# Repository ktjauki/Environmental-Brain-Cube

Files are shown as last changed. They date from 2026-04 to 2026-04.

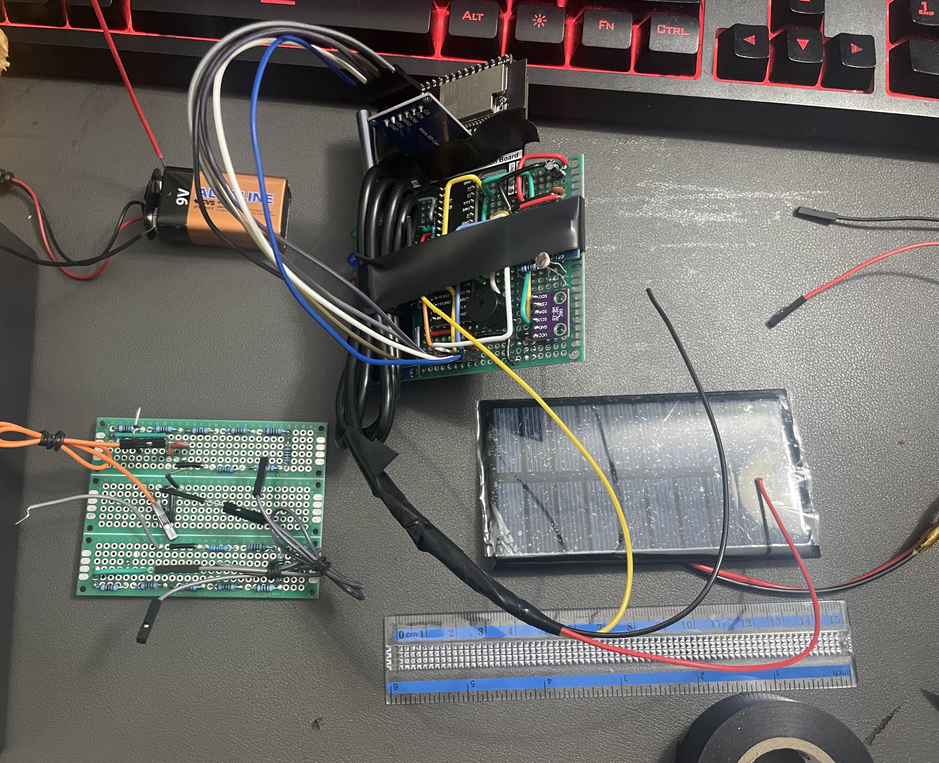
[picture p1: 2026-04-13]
Media/Components of system.JPG

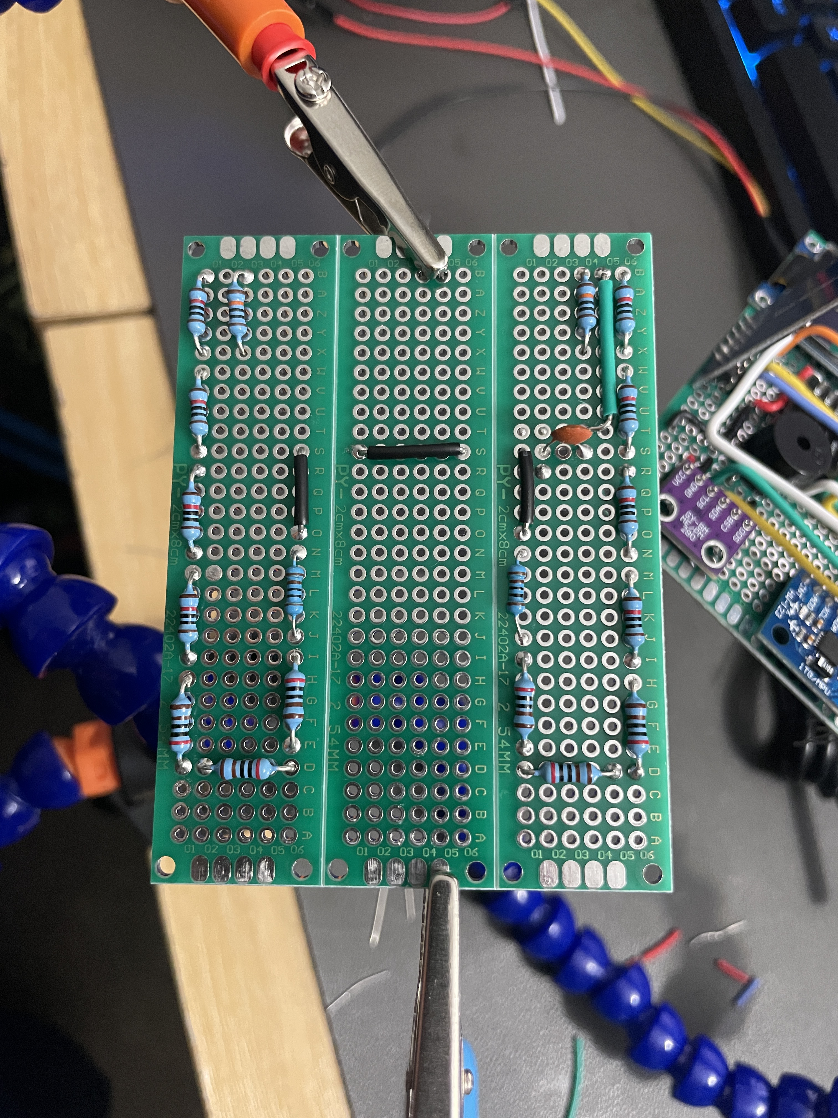
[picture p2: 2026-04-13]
Media/Voltage divider setup.JPG

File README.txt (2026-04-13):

Environmental Brain Cube (EBC)

Overview
The Environmental Brain Cube (EBC) is a compact ESP32-based embedded system designed to monitor, analyze, and evaluate environmental conditions in real time.

The system integrates multiple sensors to measure temperature, humidity, pressure, motion, light, and power, while logging data for post-processing in MATLAB. It is designed to determine environment classification and long-term suitability, with applications in space exploration and autonomous systems.

The project demonstrates a complete pipeline:
data acquisition → processing → evaluation → prediction → decision-making

Full Report:
See Project Report folder or GitHub repository.

Key Features
- Multi-sensor environmental monitoring
- Real-time OLED display + serial output
- SD card logging (CSV + summaries)
- Threshold-based warning system (LEDs + buzzer)
- Environment classification:
  - Normal
  - Warm-Dry
  - Warm-Humid
  - Cold
- MATLAB-based:
  - Data visualization
  - Trend analysis
  - Long-term prediction
  - Suitability evaluation

Hardware System

Core Components
- ESP32 WROVER-E (main controller)
- BME280 – air temperature, humidity, pressure
- DS18B20 – ground temperature
- MPU6050 – acceleration & gyroscope
- Photoresistor – light sensing
- OLED (SSD1306) – display
- SD Card Module – data logging
- 5V Solar Panel – power input sensing
- 9V Battery – power source

System Architecture

1. Data Acquisition
   Sensors collect environmental data continuously

2. Processing
   ESP32 converts raw data into usable values
   Invalid data is filtered

3. Evaluation
   Values compared to predefined thresholds
   Environment matched to closest profile

4. Output
   OLED + Serial Monitor display
   SD card logging
   LED/Buzzer alerts

5. Post-Processing
   MATLAB used for analysis, visualization, and predictions

Repository Structure

Environmental-Brain-Cube/
|
|-- Arduino Code/          # ESP32 programs (FREE run, MODES classification, SUITABILITY analysis)
|-- MATLAB Scripts/        # MATLAB scripts for data processing, plotting, and prediction
|-- MATLAB Outputs/        # Generated graphs, figures, and analysis results
|-- CSV Logged Data Files/ # Raw sensor data collected from test runs (CSV format)
|-- CAD Files/             # 3D models and design files for the enclosure
|-- Media/                 # Images of setup + Google Drive link to videos (videos stored externally due to large size)
|-- Project Report/        # Full engineering report (PDF)
|-- README.txt

Experimental Setup

Experiments were conducted using a controlled simulation box to replicate different environments:

- Normal – ambient conditions
- Warm-Dry – heated air, low humidity
- Warm-Humid – heated water, high humidity
- Cold – cooled environment

All conditions were stabilized before testing to ensure consistent data collection.

Data & Analysis

Data Collection
- Air temperature
- Ground temperature
- Humidity
- Pressure
- Light level
- Motion (acceleration)
- Battery voltage
- Solar voltage

MATLAB Processing
- Time-series plots
- Stability vs drift analysis
- Trend-based predictions
- Time-to-limit estimation
- Environment classification validation

Results Summary
- System successfully classified environments based on sensor data
- Stable environments showed consistent readings over time
- Trend analysis identified potential long-term instability
- Power analysis indicated battery depletion trends over extended use

Key Engineering Concepts
- Embedded systems design (ESP32)
- Sensor integration (I2C, analog, digital)
- Data logging and processing
- Environmental modeling
- Trend-based prediction systems
- Power monitoring (battery vs solar)
- Experimental validation

Applications
- Space exploration systems
- Planetary environmental monitoring
- Autonomous robotics
- Remote sensing platforms

Limitations
- Simplified simulation environment
- No direct current sensing (power estimated from voltage)
- Sensor accuracy constraints
- Prediction models are trend-based (not physics-based)

Future Work
- Add current sensing for accurate power analysis
- Implement wireless data transmission
- Improve prediction models (nonlinear / ML)
- Test in real-world outdoor environments
- Integrate into mobile robotic systems

Author
Kevin Jauki
Mechanical Engineering
George Mason University

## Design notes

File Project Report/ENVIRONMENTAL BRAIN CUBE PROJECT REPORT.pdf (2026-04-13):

# Environmental Brain Cube (EBC)

# Kevin Jauki

# Personal Project Report

3/20/2026

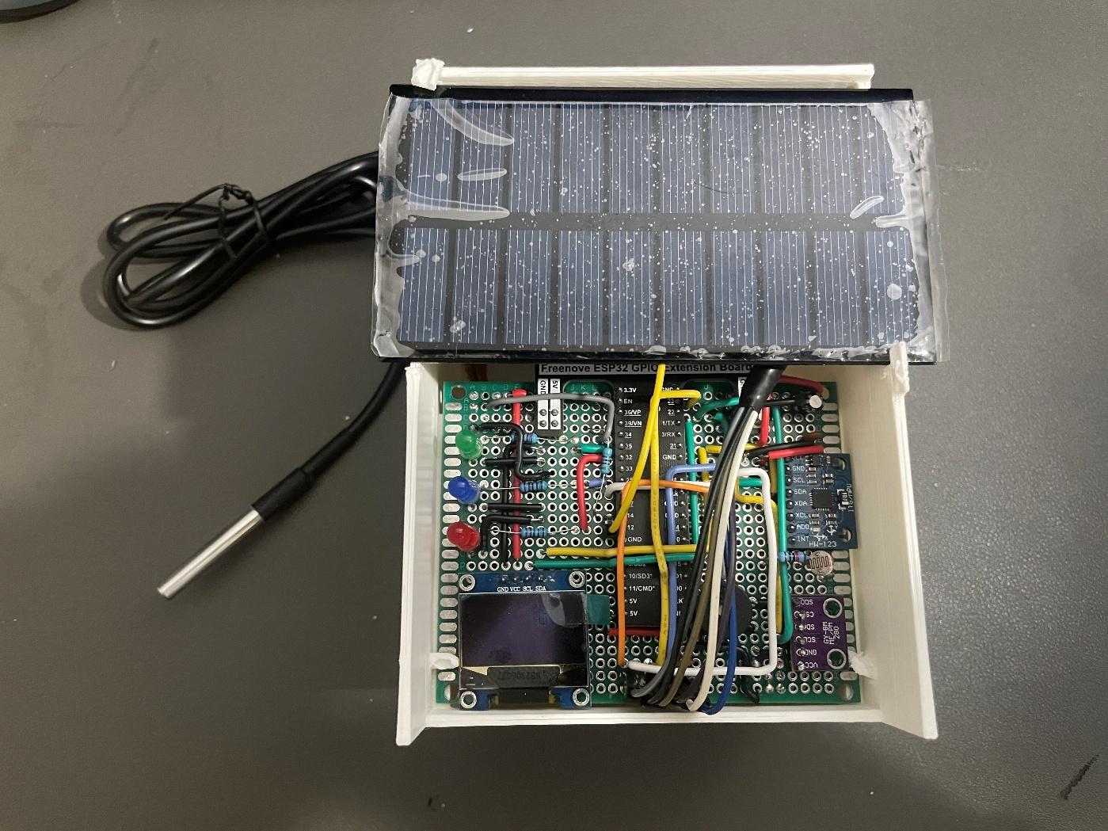
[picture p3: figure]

## Abstract

The Environmental Brain Cube (EBC) is a compact environmental monitoring and evaluation

system. It is designed to analyze environmental conditions and make conclusions per user

defined parameters. The system makes use of multiple sensors to measure air temperature,

ground temperature, pressure, humidity, motion, and light intensity. All these measurements are

displayed and logged to an SD card in real time.

The primary goal of this project is to see whether a system can autonomously make correct

conclusions of a given environment for long term use. The EBC was tested in simulated

environments of normal, warm-humid, warm-dry, and cold. These conditions were set in

controlled container setup. Output data was then analyzed using MATLAB to identify trends and

predict the environment’s long-term behavior.

Results showed that the system can correctly classify environments and determine suitability of

the system in a set environment. This demonstrates the foundation for applications in space

exploration as well as environmental monitoring systems.

## 1. Introduction

In a lot of engineering applications, understanding and adapting to environmental conditions is

very important for reliable operation. A system set in an unknown environment is vulnerable to

failure due to harsh conditions it was not prepared for. This is especially important in space

exploration, where factors such as temperature, pressure, and humidity can significantly impact

system functions and reliability. It is therefore important to collect data about a given

environment to better understand it and determine if any systems meant to run in this

environment will safely do so.

The purpose of this project is to develop an integrated system capable of sensing, monitoring,

and evaluating given environmental conditions in real time. The Environmental Brain Cube

allows for such capabilities, by using a multi-sensor platform to collect data, identify trends, and

determine whether a given environment is suitable for long term operation. This system provides

a comprehensive understanding of both ambient and surface level conditions.

To validate the system’s results, controlled experiments were conducted using a simulation box

with different environmental conditions including normal, warm-humid, warm-dry, and cold. The

data collected during these tests is logged and analyzed to evaluate system performance and

determine how accurately the EBC can classify an environment and predict suitability for long

term use.

## 2. System Overview

## 2.1 Hardware components

The system consists of sensing, processing, power, storage, and output components integrated

into one embedded system:

Table 1: EBC Component list

Component | Description
ESP32 WROVER (Microcontroller) | Dual-core processor used for data acquisition, control logic, power management, and communication between all components; operates at 3.3V
BME280 | Measures ambient temperature (°C), relative humidity (%), and atmospheric pressure (hPa)
MPU6050 | Measures motion responses including acceleration (x, y, z axes) and angular velocity (gyroscope)
DS18B20 | Measures ground temperature (°C) on which the system operates
5V Solar Panel | Reads voltage variations due to lighting conditions to estimate theoretical power output
9V Lithium Battery | Serves as the primary power storage source for the system
LEDs | Provide visual indicators when sensor readings exceed defined thresholds
Active Buzzer | Produces an audible alert when any system parameter crosses set limits
Photoresistor | Measures light intensity to classify environmental lighting conditions
OLED Display (SSD1306) | Displays real-time sensor data and system status
SD Card Module (128GB SD Card) | Logs collected data for storage and further analysis

Sensor specifications and operating characteristics were obtained from manufacturer datasheets

[1]–[3].

## 2.2 Voltage Divider

To safely measure voltages above the ESP32’s 3.3V ADC limit, voltage dividers were

implemented for both the battery and solar panel.

Each divider consisted of two resistors:

- Top resistor ≈ 100 kΩ
- Bottom resistor: ≈ 47 kΩ

The output voltage to the ESP32 is given by:

Vout = Vin ×

Rbottom

Rtop + Rbottom

This relation is based on standard voltage divider principles [5]

This ensures that higher input voltages, like those of the 9V battery and 5V solar panel, are

scaled down to a safe measurable range. The ESP32 reads this reduced voltage, and the original

voltage is reconstructed using the inverse relation.

## 2.3 Physical Construction and Integration

The system was assembled using a combination of soldered wiring on perfboards and a custom

housing design.

Circuit Assembly:

- Components were mounted on perfboards for structural stability
- Electrical connections were made using soldered wires
- Power and ground lines were distributed across common rails

Resistors and Supporting Components:

- 4.7 kΩ resistor used as pull-up for the DS18B20 data pin
- 220 Ω resistors used for current limiting on LEDs
- Voltage divider resistors (~100 kΩ and ~47 kΩ) used for voltage sensing
- ~10 kΩ resistor used in the photoresistor voltage divider

Capacitors

- 10 µF capacitors placed near power inputs (ESP32 and SD card module and Solar panel)

to stabilize voltage

- 0.1 µF capacitors used for noise filtering in sensitive analog pins

Housing Design

The enclosure was designed using Autodesk Inventor and fabricated using FDM 3D printing on

an Ender 3D printer. It was printed using PLA material to provide structural support and

protection for all components. Its main purpose was to organize internal wiring to reduce

interference and to allow access to sensors while maintaining compactness.

The final assembled system integrated all electrical and mechanical components into a compact,

portable unit suitable for controlled environmental testing.

## 2.4 Architecture

The system follows a layered process of sensing, processing, decision making, and outputting:

Data Acquisition

- Sensors collect environmental data:

- BME280 – temperature, humidity, and pressure
- DS18B20 – ground/surface temperature
- MPU6050 – motion and vibration
- Photoresistor – light intensity
- Voltage dividers – monitor power system readings from the solar panel and

battery

Processing

- Raw data is collected by the ESP32 from the sensors and converted to engineering units
- Any invalid or missing data is filtered to provide a reasonable reading
- Data is then organized for further calculations and logging

Evaluation

- The system evaluates the processed data against given thresholds
- For environmental classification, processed data is compared with set environment types,

and the best match is used as the final decision

- For environmental suitability, processed data is compared with set thresholds to see if it

stayed within those thresholds and how much the offsets were.

Output

- OLED Display:
- Shows a real-time visualization of measurements being taken or processing being

conducted

- Serial Monitor:

- Like the OLED display, the serial monitor shows a more in-depth real time

visualization of measurements and processes

- SD Card Logging:
- All collected data including result summaries and conclusions are logged to the

SD card as csv and text files.

- Warnings:
- Any values that cross past a threshold are flagged and activate a visual (led ON)

and audible (buzzer sound) output

Post-Processing

- Logged csv data is imported to MATLAB where it will be further processed to generate

graphs and comparison tables which will be used for trend analysis and long-term

predictions

## 3. Experimental Setup

## 3.1 Simulation Box

Experiments were conducted using a transparent plastic container with a lid, that served as a

controlled environment enclosure. This allowed conditions to be stabilized for the duration of a

test. The Environmental Brain Cube was first placed in a small open container with sand where

the DS18B20 was to be placed for ground temperature readings, then placed inside the main test

container.

## 3.2 Environmental Conditions

Different environments were made using these elements:

- Normal: No additions (left to operate alone in the box)
- Warm-Dry: A warm blower blew warm air into the container through a small opening.

This allowed for dry air to enter and reduces humidity (~15–35%).

- Warm-Humid: A bowl with hot water was set inside the container to increase

temperature and humidity (~60–70%)

- Cold: The simulation box was placed in a freezer to cool down(~4–12°C)
- Light: A desk lamp was used to simulate light input

All conditions were allowed to stabilize before data was recorded.

## 4. Methods

## 4.1 Test Procedure

Each test followed the same procedure

1. Place the EBC system inside the simulation box with the selected environment set up
2. Start the test run and begin data display and logging
3. Record the measured data to the SD card throughout the run
4. Monitor the system for any warnings or faults
5. End the test after the set duration and view the results

## 4.2 Data Collection

Data was continuously collected and stored on a time basis. This was in the form of a csv file

uploaded to the SD card for later analysis. Minimum and maximum values for each

parameter were collected for future average computation.

Logged parameters:

- Air temperature (BME280)
- Ground temperature (DS18B20)
- Humidity
- Pressure
- Light level
- Acceleration (motion and vibration)
- Battery voltage
- Solar panel voltage

## 5. Software and Logic

## 5.1 Arduino code system logic

The ESP32 system runs a continuous loop to monitor environmental and system parameters. The

control code was developed using the Arduino IDE [4].

- Sensor readings are taken for air temperature, ground temperature, humidity, pressure,

light level, acceleration, and voltage

- Each value is compared against predefined threshold limits
- Warnings are triggered if limits are exceeded
- All data is logged to the SD card with time tracking for later analysis
- The system uses non-blocking timing to ensure consistent and reliable data collection

## 5.2 Mode/Comparison Logic

The system compares collected data against predefined environmental profiles to match the best

profile with the test conditions that were set.

Table 2: Environment Profiles and their respective parameters

Mode | Temperature(°C) | Humidity (%) | Pressure (hPa)
Normal | 20.0 – 24.0 | 30.0 – 50.0 | 995.0 – 1025.0
Warm-Dry | 24.0 – 30.0 | 15.0 – 35.0 | 995.0 – 1025.0
Warm-Humid | 26.0 – 32.0 | 60.0 – 70.0 | 995.0 – 1025.0
Cold | 4.0 – 12.0 | 35.0 – 65.0 | 995.0 – 1025.0

At the end of a run, average values are calculated and compared to the ranges above for each

profile. The system determines which environment closely matches and a rating is assigned

based on how many parameters fall within the expected range.

## 5.3 Suitability Logic

The suitability logic determines whether the environment is safe for the system to run in for the

duration of the test run, as well as for future long-term use. The user sets environment parameters

for their needs and the system considers environment safe if all parameters of the test environment meet those of the set environment. Failure occurs when a parameter exceeds limits

for a continuous set time (not just a short spike). This triggers the system to deem the

environment unsafe and stop the program.

## 5.4 Prediction Logic

Prediction logic estimates long term behavior of an environment based on trends observed during

a run. Stable values that stabilize over time indicate that the environment is likely safe and steady

for continued use. Short spikes or disturbances are seen as external effects and are not used in

prediction calculations. However, continuous rising or falling trends are considered warnings of

instability for long term use of the system. Based on observed behavior, the system determines if

parameters will either stabilize around the most recent steady values or continue trending toward

the system limits. If a parameter shows continued increase or decrease, the system estimates

whether it may eventually reach set limits in the future.

## 6. Data Analysis

## 6.1 Graphs

MATLAB was used to create visualizations of the recorded parameters [6], which helped to

illustrate the system's behavior during each test. These parameters included air temperature,

ground temperature, humidity, pressure, light level, acceleration, battery voltage, and solar

voltage. Each graph showed how the values changed over the duration of the test. For example, a temperature plot for the warm-dry condition is shown in Figure 1 (Appendix), while humidity

and pressure plots are provided in Figures 2 and 3 (Appendix).

## 6.2 Environmental Matching

The collected data helped classify the test environment by comparing what was measured against

a set of predefined environmental conditions. To do this, average temperature, humidity, and

pressure values were calculated and then checked against the expected ranges for each mode.

Whichever environment came closest to the measured data was chosen as the match.

The plotted data in the Appendix backs up this comparison, allowing the relationship between

the measured values and the expected ranges to be visualized. The final classification shows how

closely the system's recorded conditions lined up with what the experimental setup was designed

to produce. A summary of the test run was also produced for each matching evaluation, as seen

in Figure 4.

## 6.3 Trend Analysis

Trend analysis was done by looking at the shape and progression of the plotted data over the

duration of the run. Parameters that appeared to stay rather constant or settled down were taken

as a sign of stability, suggesting that the environmental conditions were consistent throughout the

run. On the other hand, values that drifted gradually up or down were looked at more closely to

figure out whether they were genuine environmental changes or were simply brief disturbances.

Patterns that stood out, like a value stabilizing after an initial jump, or a steady drift in one

direction, were used to get a better read on how the system was behaving. Such trends can be

seen in the plotted results included in the Appendix, with Figure 5 being a good example.

## 6.3 Predictions

Predictions about future system behavior were drawn from the trends observed in the MATLAB

plots. For parameters that showed stable behavior, it was assumed they would continue to sit

within a steady range going forward. Where a continuous rise or fall was spotted, the system

estimated whether the parameter would eventually approach or push past defined limits, and

when relevant, a rough time frame for reaching those limits was worked out based on how

quickly the value was changing. For parameters that showed no real long-term trend, no

prediction of limit exceedance was needed.

Examples of this prediction behavior, along with trend extensions, are shown in the Appendix,

with Figure 5 being a good illustration where the prediction is overlaid directly onto the

measured data. A suitability summary at the end of suitability test run evaluations showed an

overview of performance and predictions, as shown in Figure 6.

## 7. Results and Discussion

The results from the experimental runs show that the Environmental Brain Cube (EBC) was able

to successfully monitor and record environmental conditions across all tested scenarios. The

collected data and the MATLAB analysis gave a clear picture of the system’s performance,

environmental behavior, and overall suitability.

For the different environments, the system operated steadily, with all most parameters staying

within defined safe thresholds. As expected, the warm and warm-humid environments produced

noticeable increases in both air and ground temperature, with humidity levels rising significantly in the warm-humid case. These trends are visible in the temperature and humidity plots shown in

Figure 9 and 10 in the Appendix. The warm-dry environment, on the other hand, showed high

temperatures but reduced humidity, confirming that the environmental controls used in the

simulation box were effective in making a warm-dry environment and the system correctly

identified that environment.

The cold environment led to lower temperature and humidity readings. All the parameters

remained within acceptable ranges throughout the test. No critical failures were observed in runs

where conditions stayed within threshold limits, suggesting that the system can hold up across a

range of moderate environments.

Trend analysis revealed that many parameters either stayed stable or showed minor fluctuations

before settling down. This shows that some disturbances were caused by external factors rather

than any underlying environmental instability. In cases where parameters showed a continuous

rise or fall, the prediction logic flagged this as unsuitable for long term use if those trends were

to continue. These behaviors can be seen in the plotted data with prediction overlays, such as he

voltage plot in Figure 7 in the Appendix, which shows that for long term use, the battery voltage

would decrease significantly and won’t power the system.

The environment matching logic further confirmed that the measured data lined up closely with

the intended test conditions. In most cases, the system correctly classified the environment based

on average temperature and humidity values, showing that both the experimental setup and the

comparison logic were effective in producing and identifying distinct environmental profiles.

Overall, the results indicate that the EBC system is well capable of reliably collecting

environmental data, identifying trends, and evaluating suitability. While the simulation setup offers a simplified model of real world conditions, the behavior observed throughout testing

suggests that the system could be extended to more complex environments with further

adjustments.

## 8. Conclusion

The Environmental Brain Cube (EBC) successfully demonstrated the ability to monitor, record,

and analyze environmental conditions within a controlled simulation setup. Across all test

environments, the system reliably collected data and provided meaningful insights into

temperature, humidity, pressure, and parameters such as power behavior.

The results showed that the system performs well under stable conditions and can distinguish

between different environmental profiles. The implemented suitability and prediction logic

allowed the system to assess whether an environment is safe for continued operation and identify

potential long-term risks based on observed trends.

Overall, the project validates the concept of a compact environmental monitoring system capable

of supporting decision making in different environments, for use in applications such as space

exploration, where systems must operate reliably in extreme and unpredictable environments

## 9. Limitations

While the system performed effectively, several limitations were identified:

- The simulation box represents a simplified environment and does not fully replicate real

world conditions

- Environmental changes were manually introduced, which may lead to inconsistencies

between runs

- Sensor accuracy and resolution (e.g. DHT11 limitations) may affect precision of collected

data

- Power calculations are based on voltage measurements and estimated assumptions rather

than direct current sensing

- Prediction models are trend based and do not account for complex physical interactions

or sudden environmental changes

These limitations should be considered when interpreting results and extending the system to real

applications.

## 10. Improvements

Several improvements can be made to enhance the system’s performance and applicability:

- Integrate current sensing for more accurate power and energy calculations
- Improve environmental control using automated heating, cooling, and humidity systems

- Use higher precision sensors to improve data accuracy
- Expand prediction models to include more advanced methods (e.g. machine learning)
- Test the system in more realistic outdoor or field environments

Future developments will focus on increasing realism, accuracy, and system autonomy.

## Appendix

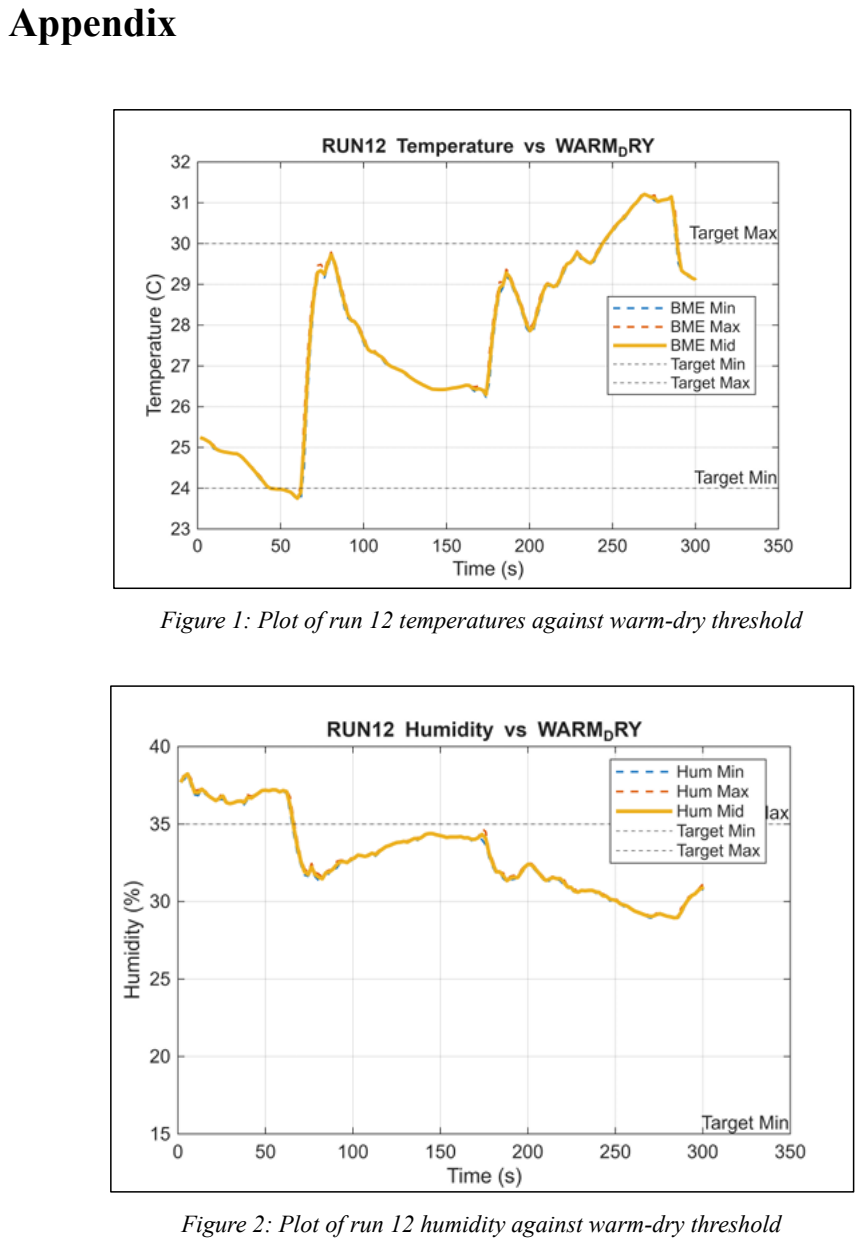
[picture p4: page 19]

Figure 1: Plot of run 12 temperatures against warm-dry threshold

Figure 2: Plot of run 12 humidity against warm-dry threshold

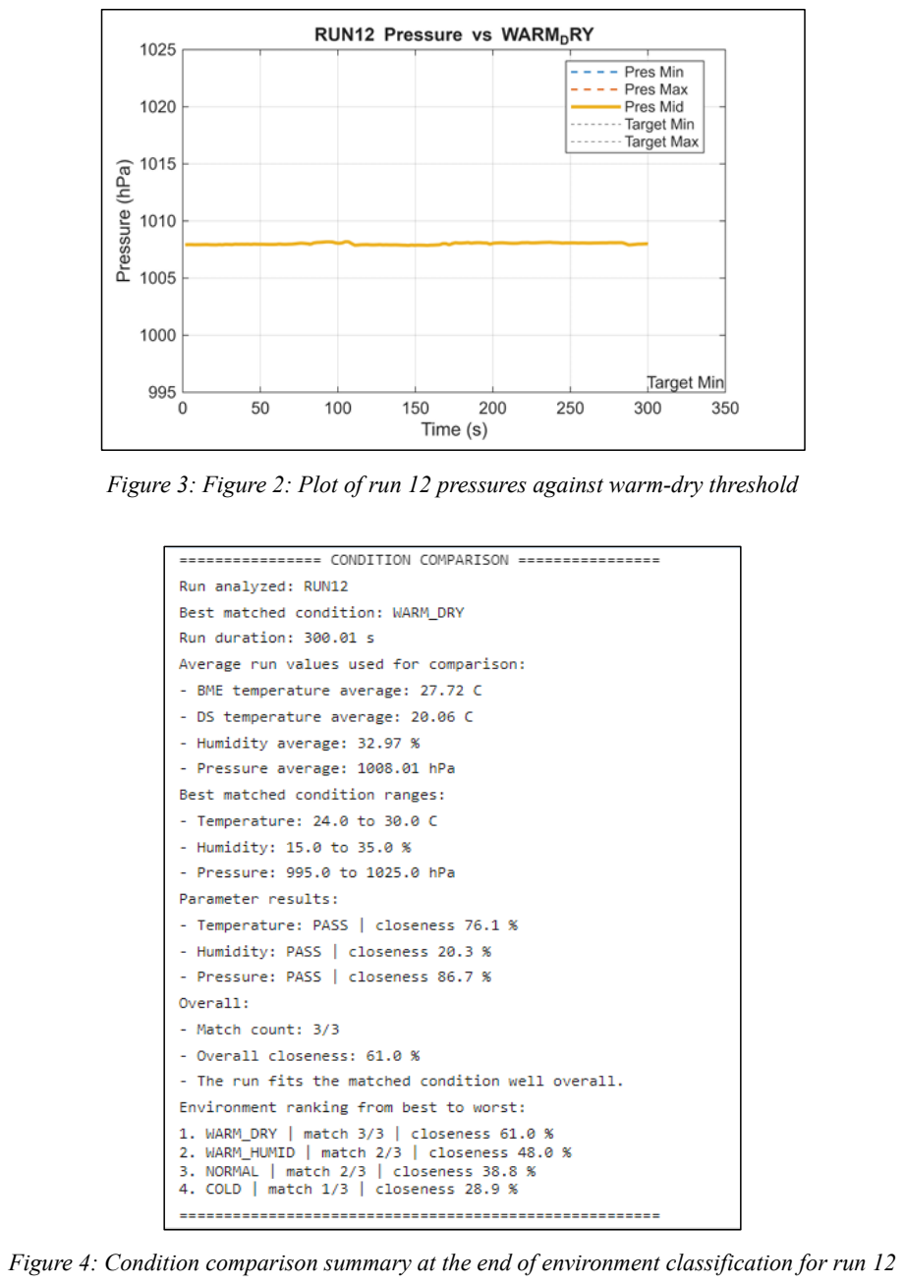
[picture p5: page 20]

Figure 3: Figure 2: Plot of run 12 pressures against warm-dry threshold

Figure 4: Condition comparison summary at the end of environment classification for run 12

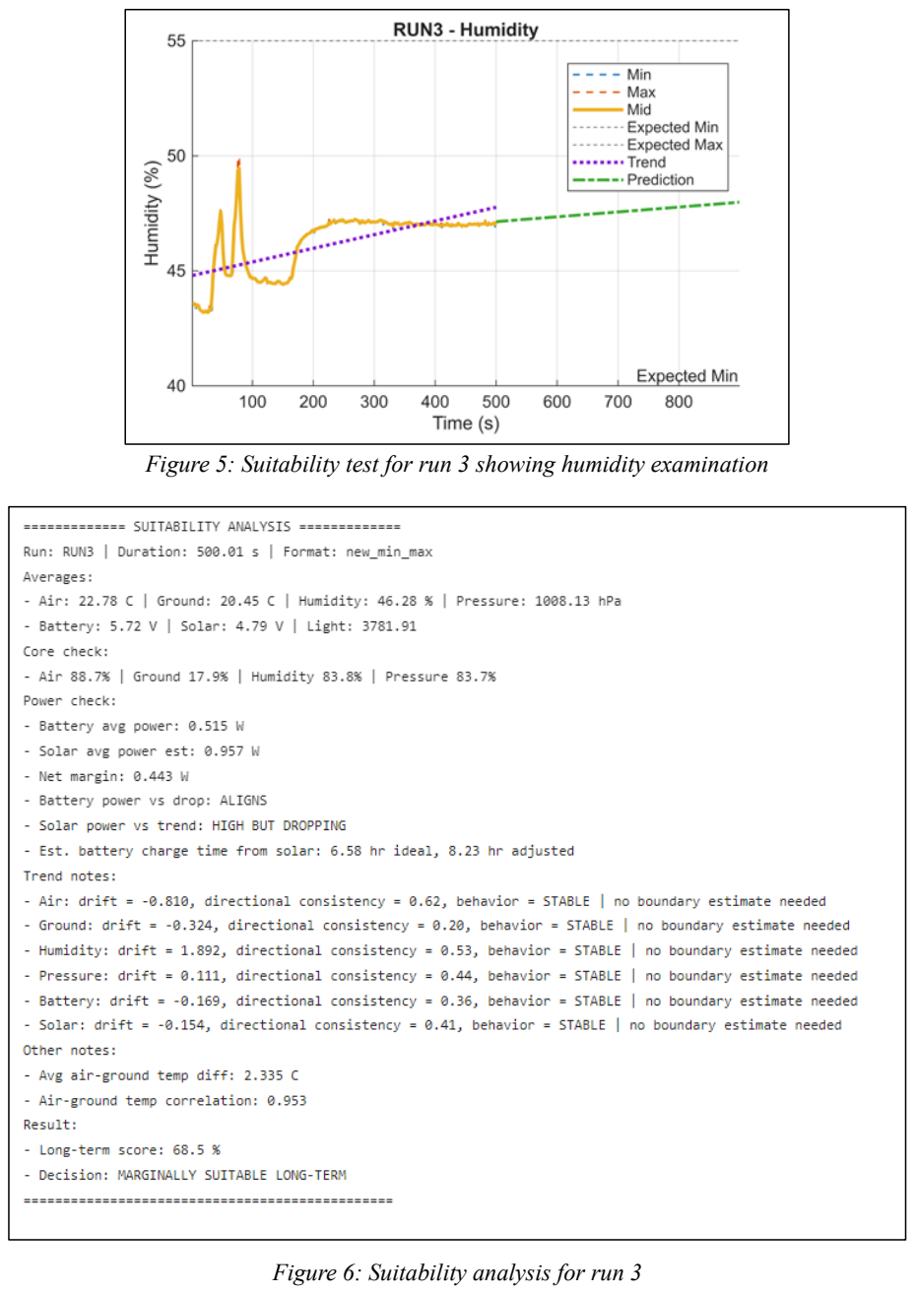
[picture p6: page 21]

Figure 5: Suitability test for run 3 showing humidity examination

Figure 6: Suitability analysis for run 3

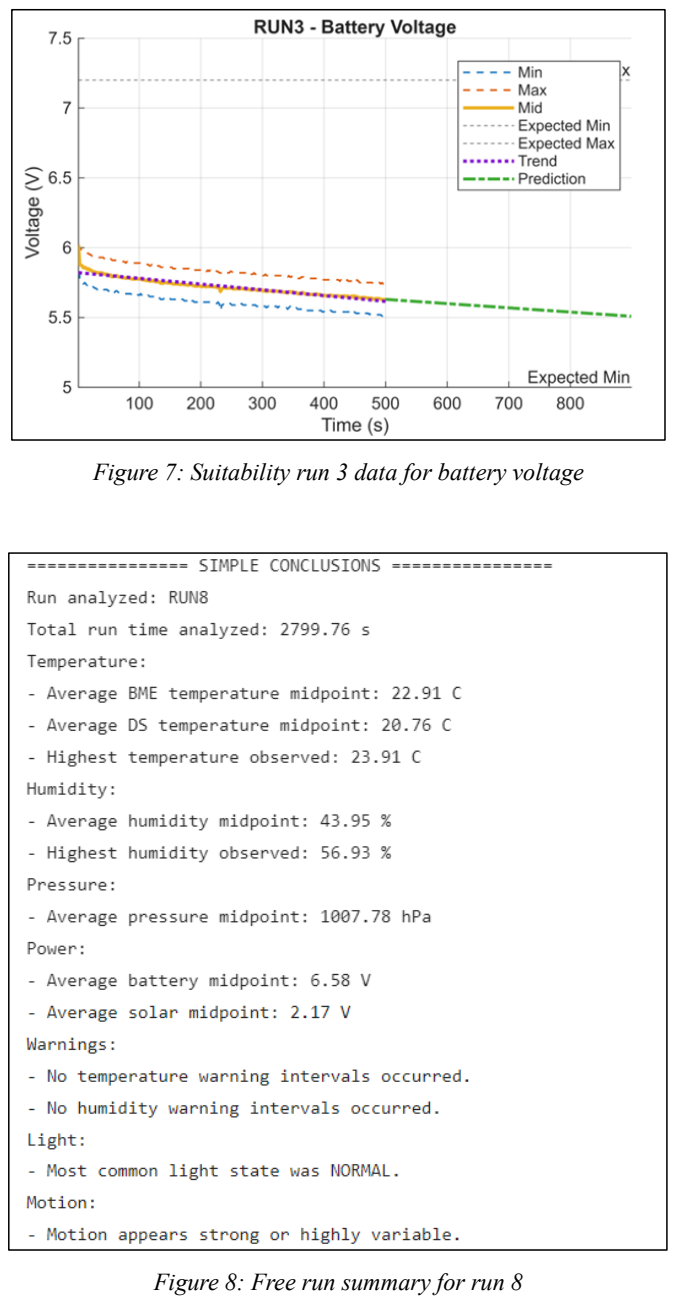
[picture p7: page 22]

Figure 7: Suitability run 3 data for battery voltage

Figure 8: Free run summary for run 8

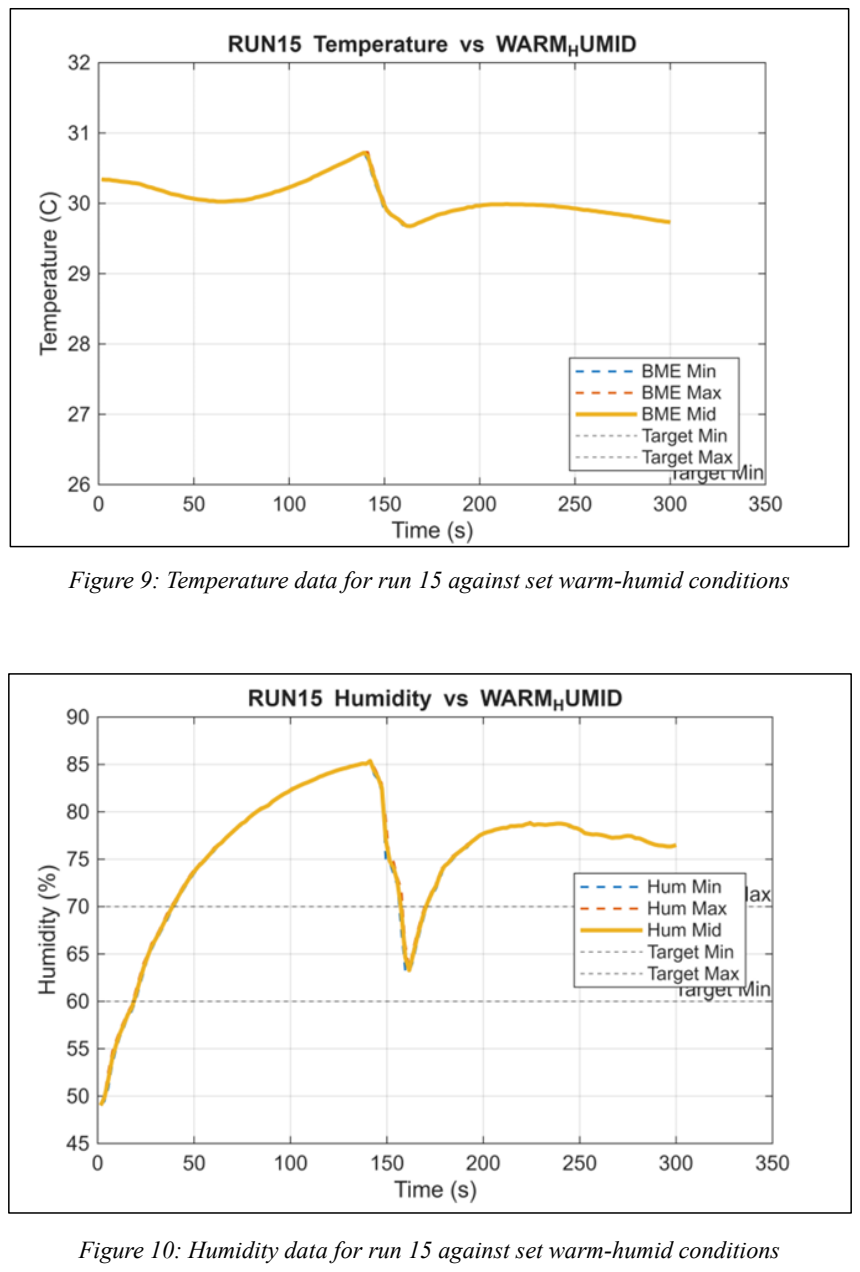
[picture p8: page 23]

Figure 9: Temperature data for run 15 against set warm-humid conditions

Figure 10: Humidity data for run 15 against set warm-humid conditions

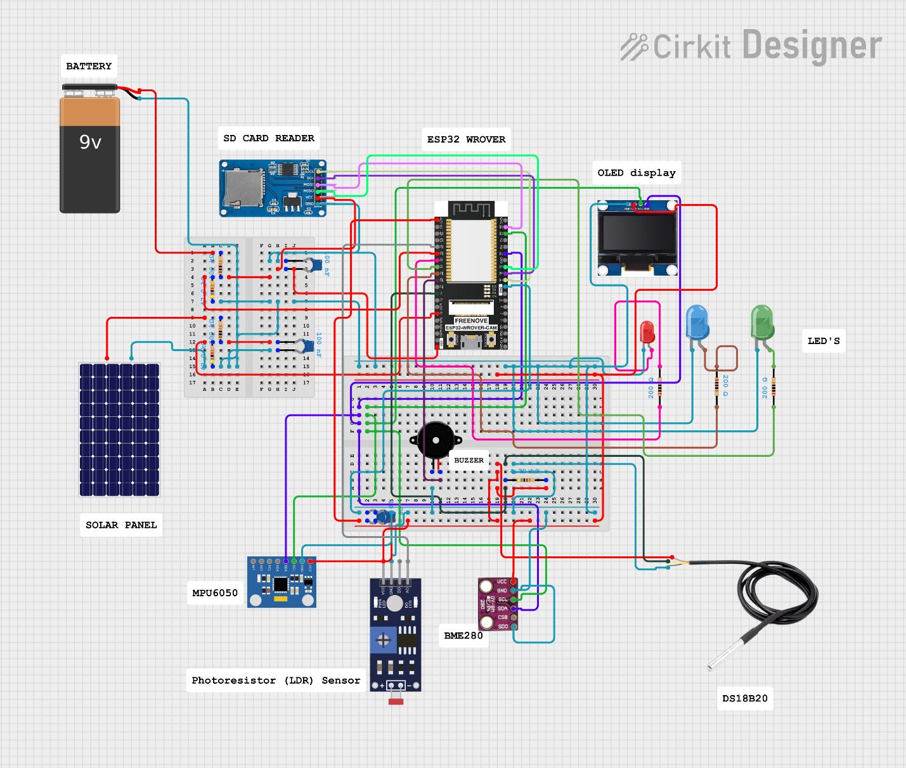
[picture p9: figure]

Figure 11: Rough layout of EBC components

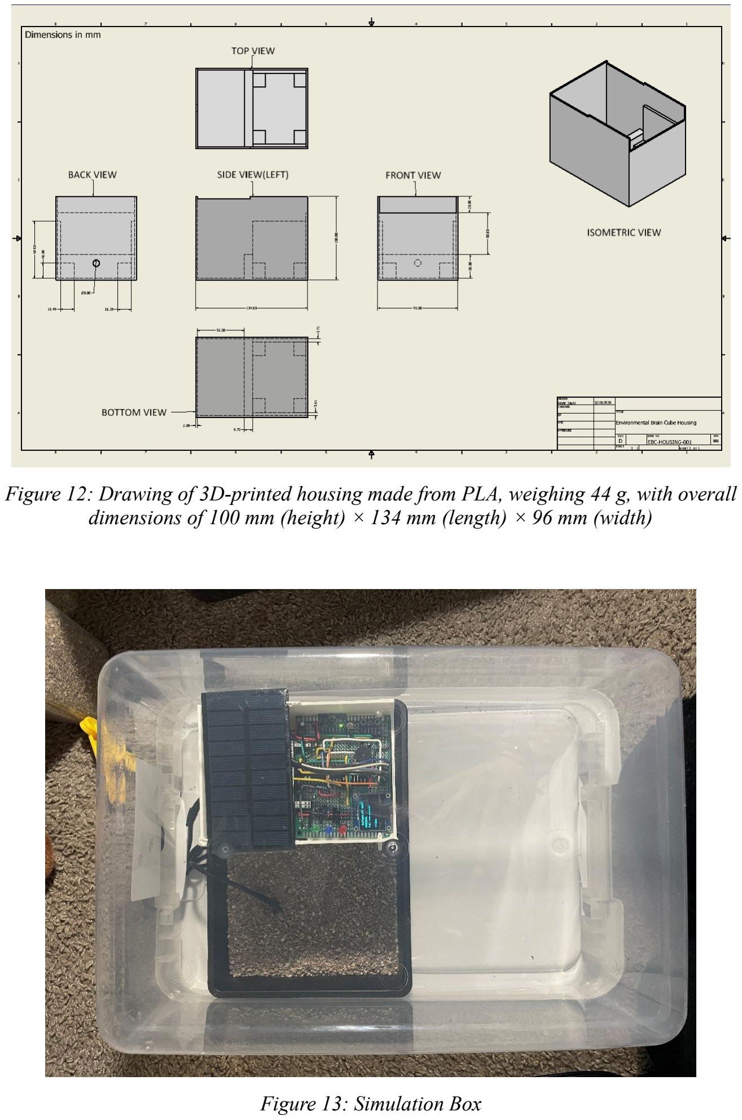
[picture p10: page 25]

Figure 12: Drawing of 3D-printed housing made from PLA, weighing 44 g, with overall dimensions of 100 mm (height) × 134 mm (length) × 96 mm (width)

Figure 13: Simulation Box

## Supplementary Material

All supporting materials including source code, data files, CAD models, and experimental media

are provided separately: https://github.com/ktjauki/Environmental-Brain-Cube.git

## References

[1] Bosch Sensortec, BME280 Datasheet, 2018.
[2] TDK InvenSense, MPU6050 Datasheet, 2013.
[3] Maxim Integrated, DS18B20 Datasheet, 2015.
[4] Arduino, Arduino IDE Documentation.
[5] J. W. Nilsson and S. A. Riedel, Electric Circuits.
[6] MathWorks, MATLAB Documentation.

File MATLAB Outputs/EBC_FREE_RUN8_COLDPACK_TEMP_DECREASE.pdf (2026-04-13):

## KEVIN JAUKI

%% Environmental Brain Cube - Free Scan Analysis
% This script looks at free scan log data from the cube. % It reads one run, makes graphs, shows warning counts, % and prints simple conclusions at the end.
%
% Main things:
% - reads the CSV text file
% - finds the run to use
% - makes midpoint values from min/max data
% - plots temperature, humidity, pressure, power, light, motion % - shows summary tables
% - prints simple conclusions
%

clear; clc; close all;

%% settings
fileName = "ebc_free_log.csv";
runChoice = "8"; | % "latest" or a run number like "2" (make sure run
number is accurate and quoted"")

tempWarnC = 50;
humWarnHigh = 85;

%% check file
if ~isfile(fileName)
error("File not found: " + fileName); end

%% read file as lines
txt = fileread(fileName);
lines = splitlines(string(txt)); lines = strtrim(lines);
lines = lines(lines ~= "");

%% keep only real data lines dataLines = strings(0,1);

for i = 1:length(lines)
lineNow = lines(i);

if startsWith(lineNow, "RUN") && ~startsWith(lineNow, "=== RUN") parts = split(lineNow, ",");
if numel(parts) >= 30
dataLines(end+1,1) = lineNow; %#ok<SAGROW>

end
end
end

if isempty(dataLines)
error("No valid RUN data rows found."); end

%% make arrays
n = length(dataLines);

runNum = nan(n,1);
timeSec = nan(n,1);

lightMin = nan(n,1);
lightMax = nan(n,1);
lightState = strings(n,1);

bmeTempMin = nan(n,1);
bmeTempMax = nan(n,1);

bmeHumMin = nan(n,1);
bmeHumMax = nan(n,1);

bmePresMin = nan(n,1);
bmePresMax = nan(n,1);

dsTempMin = nan(n,1);
dsTempMax = nan(n,1);

battMin = nan(n,1);
battMax = nan(n,1);

solarMin = nan(n,1);
solarMax = nan(n,1);

axMin = nan(n,1);
axMax = nan(n,1);

ayMin = nan(n,1);
ayMax = nan(n,1);

azMin = nan(n,1);
azMax = nan(n,1);

gxMin = nan(n,1);
gxMax = nan(n,1);

gyMin = nan(n,1);
gyMax = nan(n,1);

gzMin = nan(n,1);
gzMax = nan(n,1);

%% pull values from each row
for i = 1:n
row = split(dataLines(i), ",");
row = strtrim(row);

runNum(i) = sscanf(row(1), "RUN%d"); timeSec(i) = makeNum(row(3));

lightMin(i) = makeNum(row(4)); lightMax(i) = makeNum(row(5)); lightState(i) = row(6);

bmeTempMin(i) = makeNum(row(7)); bmeTempMax(i) = makeNum(row(8));

bmeHumMin(i) = makeNum(row(9)); bmeHumMax(i) = makeNum(row(10));

bmePresMin(i) = makeNum(row(11)); bmePresMax(i) = makeNum(row(12));

dsTempMin(i) = makeNum(row(13)); dsTempMax(i) = makeNum(row(14));

battMin(i) = makeNum(row(15)); battMax(i) = makeNum(row(16));

solarMin(i) = makeNum(row(17)); solarMax(i) = makeNum(row(18));

axMin(i) = makeNum(row(19)); axMax(i) = makeNum(row(20));

ayMin(i) = makeNum(row(21)); ayMax(i) = makeNum(row(22));

azMin(i) = makeNum(row(23)); azMax(i) = makeNum(row(24));

gxMin(i) = makeNum(row(25)); gxMax(i) = makeNum(row(26));

gyMin(i) = makeNum(row(27)); gyMax(i) = makeNum(row(28));

gzMin(i) = makeNum(row(29));

gzMax(i) = makeNum(row(30)); end

%% make table
T = table(runNum,timeSec,... lightMin,lightMax,lightState,... bmeTempMin,bmeTempMax,...
bmeHumMin,bmeHumMax,...
bmePresMin,bmePresMax,...
dsTempMin,dsTempMax,...
battMin,battMax,...
solarMin,solarMax,...
axMin,axMax,...
ayMin,ayMax,...
azMin,azMax,...
gxMin,gxMax,...
gyMin,gyMax,...
gzMin,gzMax);

%% choose run
allRuns = unique(T.runNum);

if runChoice == "latest"
runToUse = max(allRuns);
else
runToUse = double(runChoice); end

D = T(T.runNum == runToUse, :);
D = sortrows(D, "timeSec");

if isempty(D)
error("Selected run not found."); end

fprintf("Using RUN%d\n", runToUse);

Using RUN8
fprintf("Intervals logged: %d\n", height(D));

Intervals logged: 1381
fprintf("Run duration: %.2f s\n", max(D.timeSec));

Run duration: 2799.76 s

%% make midpoint values
D.bmeTempMid = (D.bmeTempMin + D.bmeTempMax) / 2; D.dsTempMid = (D.dsTempMin + D.dsTempMax) / 2; D.bmeHumMid = (D.bmeHumMin + D.bmeHumMax) / 2;

D.bmePresMid = (D.bmePresMin + D.bmePresMax) / 2;

D.battMid = (D.battMin + D.battMax) / 2; D.solarMid = (D.solarMin + D.solarMax) / 2; D.lightMid = (D.lightMin + D.lightMax) / 2;

D.axMid = (D.axMin + D.axMax) / 2;
D.ayMid = (D.ayMin + D.ayMax) / 2;
D.azMid = (D.azMin + D.azMax) / 2;

D.gxMid = (D.gxMin + D.gxMax) / 2; D.gyMid = (D.gyMin + D.gyMax) / 2; D.gzMid = (D.gzMin + D.gzMax) / 2;

%% temperature graph
figure
plot(D.timeSec, D.bmeTempMin, '--', 'LineWidth', 1) hold on
plot(D.timeSec, D.bmeTempMax, '--', 'LineWidth', 1) plot(D.timeSec, D.bmeTempMid, 'LineWidth', 2)

plot(D.timeSec, D.dsTempMin, ':', 'LineWidth', 1) plot(D.timeSec, D.dsTempMax, ':', 'LineWidth', 1) plot(D.timeSec, D.dsTempMid, 'LineWidth', 2)

yline(tempWarnC, '--', 'Temp warning')
grid on
xlabel('Time (s)')
ylabel('Temperature (C)')
title("RUN" + runToUse + " Temperature")
legend('BME Min','BME Max','BME Mid','DS Min','DS Max','DS Mid','Location','best')

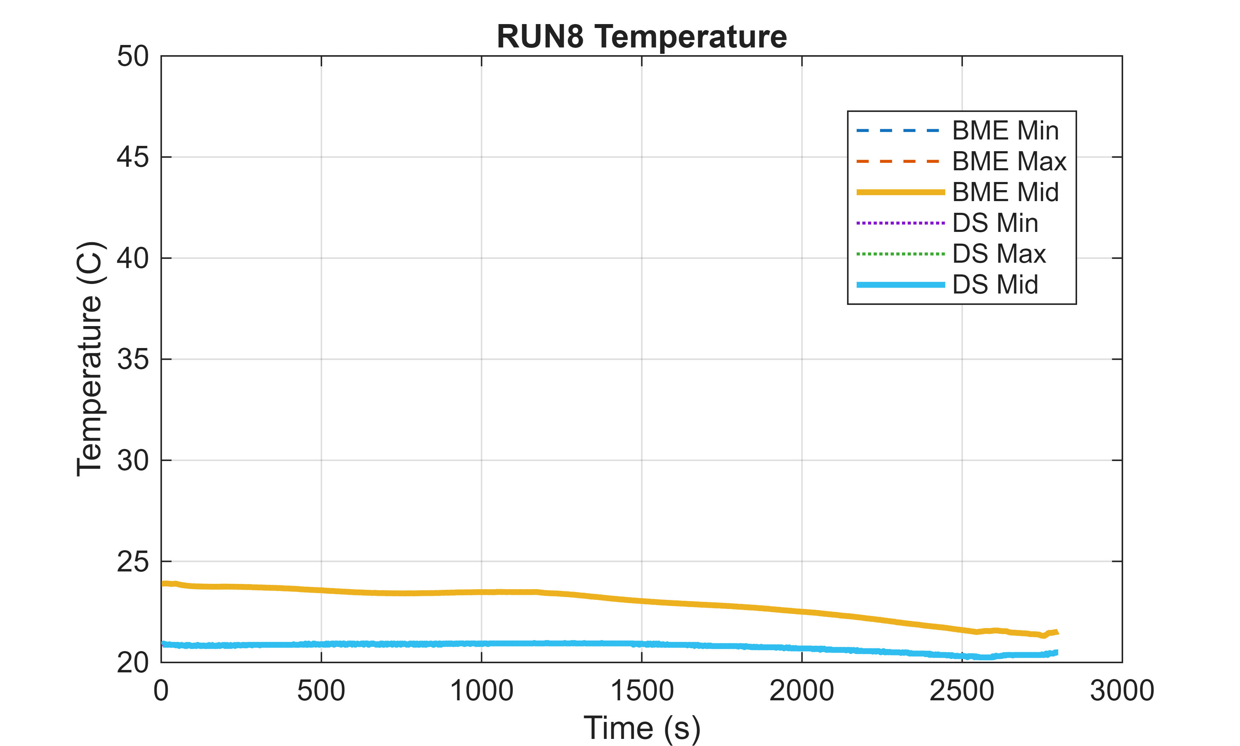
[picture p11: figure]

%% humidity graph
figure
plot(D.timeSec, D.bmeHumMin, '--', 'LineWidth', 1) hold on
plot(D.timeSec, D.bmeHumMax, '--', 'LineWidth', 1) plot(D.timeSec, D.bmeHumMid, 'LineWidth', 2) yline(humWarnHigh, '--', 'Humidity warning')
grid on
xlabel('Time (s)')
ylabel('Humidity (%)')
title("RUN" + runToUse + " Humidity")
legend('Hum Min','Hum Max','Hum Mid','Location','best')

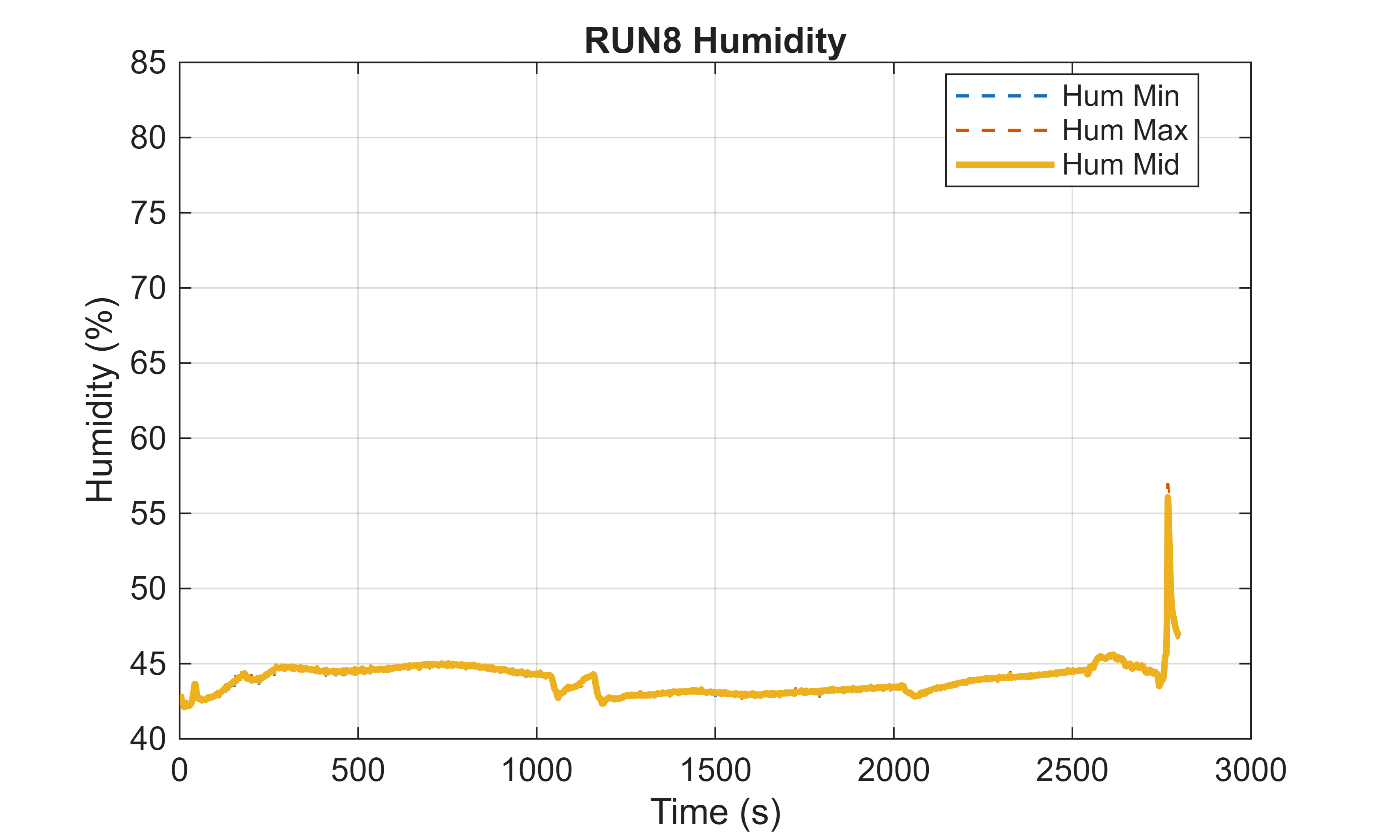
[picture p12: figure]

%% pressure graph
figure
plot(D.timeSec, D.bmePresMin, '--', 'LineWidth', 1) hold on
plot(D.timeSec, D.bmePresMax, '--', 'LineWidth', 1) plot(D.timeSec, D.bmePresMid, 'LineWidth', 2)
grid on
xlabel('Time (s)')
ylabel('Pressure (hPa)')
title("RUN" + runToUse + " Pressure")
legend('Pres Min','Pres Max','Pres Mid','Location','best')

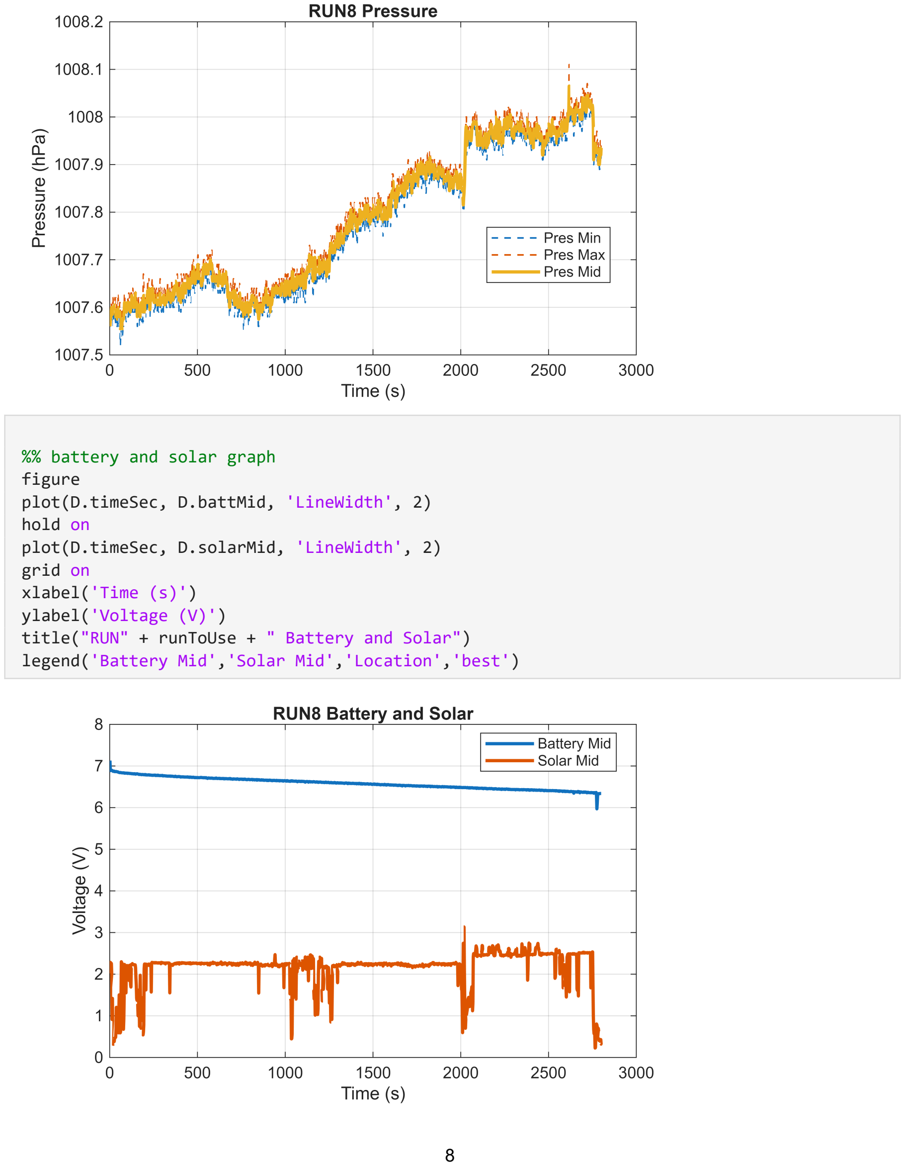
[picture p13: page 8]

%% battery and solar graph
figure
plot(D.timeSec, D.battMid, 'LineWidth', 2) hold on
plot(D.timeSec, D.solarMid, 'LineWidth', 2) grid on
xlabel('Time (s)')
ylabel('Voltage (V)')
title("RUN" + runToUse + " Battery and Solar") legend('Battery Mid','Solar Mid','Location','best')

%% light graph
figure
plot(D.timeSec, D.lightMin, '--', 'LineWidth', 1) hold on
plot(D.timeSec, D.lightMax, '--', 'LineWidth', 1) plot(D.timeSec, D.lightMid, 'LineWidth', 2)
grid on
xlabel('Time (s)')
ylabel('Light Raw')
title("RUN" + runToUse + " Light")
legend('Light Min','Light Max','Light Mid','Location','best')

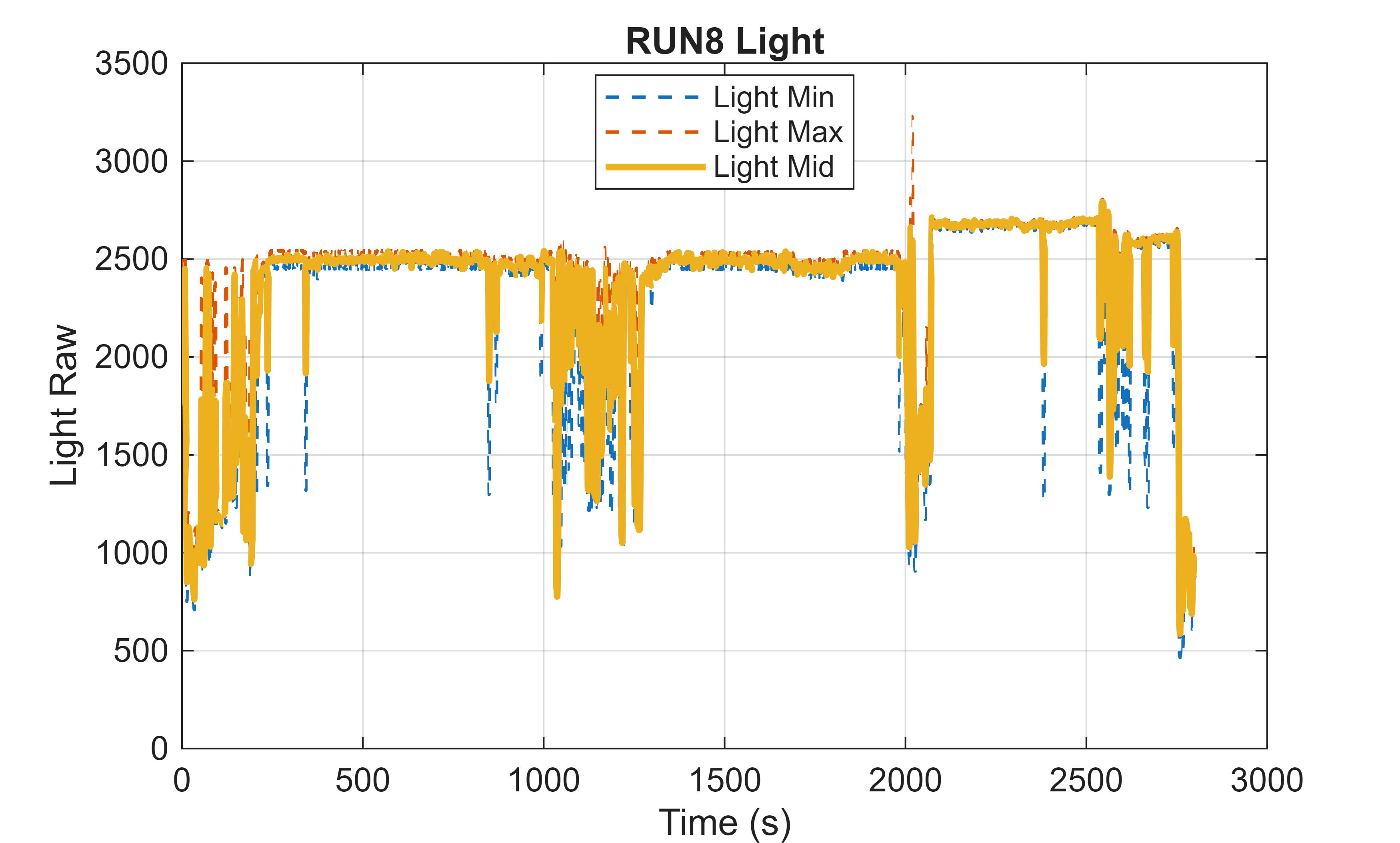
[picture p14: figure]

%% accel graph
figure
plot(D.timeSec, D.axMid, 'LineWidth', 1.5) hold on
plot(D.timeSec, D.ayMid, 'LineWidth', 1.5) plot(D.timeSec, D.azMid, 'LineWidth', 1.5) grid on
xlabel('Time (s)')
ylabel('Acceleration (m/s^2)')
title("RUN" + runToUse + " Acceleration Midpoints") legend('Ax','Ay','Az','Location','best')

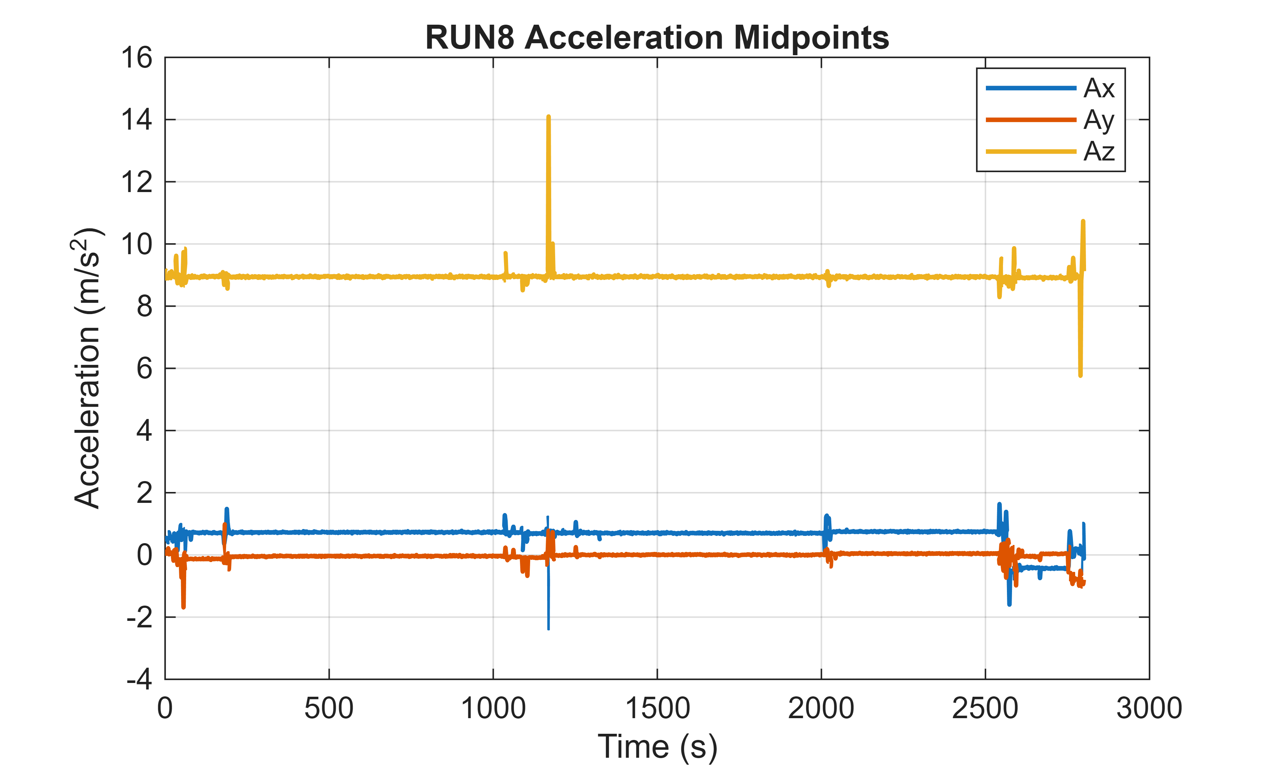
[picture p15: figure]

%% gyro graph
figure
plot(D.timeSec, D.gxMid, 'LineWidth', 1.5) hold on
plot(D.timeSec, D.gyMid, 'LineWidth', 1.5) plot(D.timeSec, D.gzMid, 'LineWidth', 1.5) grid on
xlabel('Time (s)')
ylabel('Gyro (dps)')
title("RUN" + runToUse + " Gyro Midpoints") legend('Gx','Gy','Gz','Location','best')

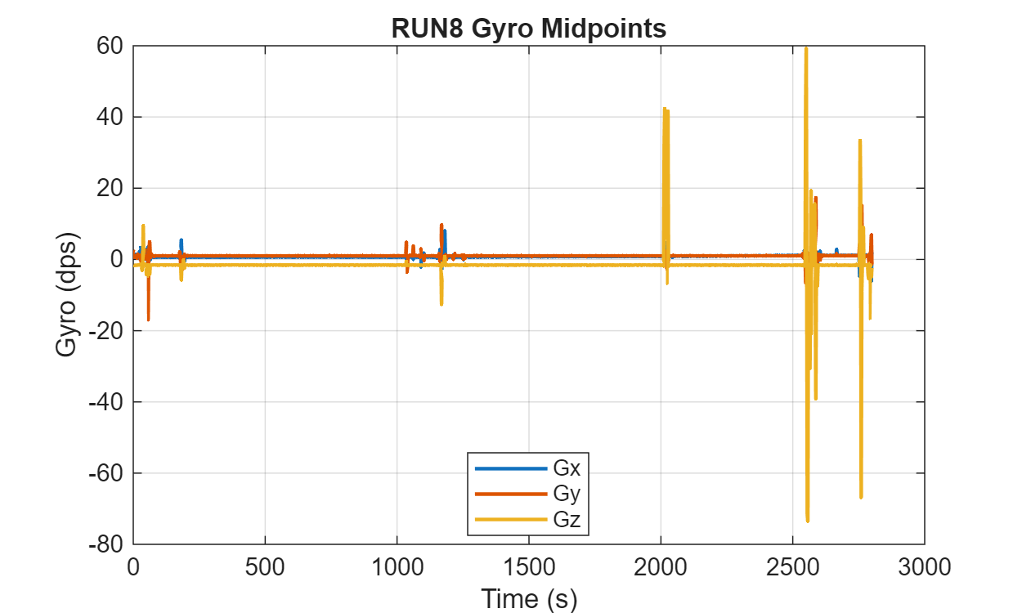
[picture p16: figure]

%% summary table
Parameter = [
"BME Temp (C)"
"DS Temp (C)"
"Humidity (%)"
"Pressure (hPa)"
"Battery (V)"
"Solar (V)"
"Light (raw)"
];

OverallMin = [
min(D.bmeTempMin,[],'omitnan') min(D.dsTempMin,[],'omitnan') min(D.bmeHumMin,[],'omitnan') min(D.bmePresMin,[],'omitnan') min(D.battMin,[],'omitnan') min(D.solarMin,[],'omitnan') min(D.lightMin,[],'omitnan') ];

OverallMax = [
max(D.bmeTempMax,[],'omitnan') max(D.dsTempMax,[],'omitnan') max(D.bmeHumMax,[],'omitnan') max(D.bmePresMax,[],'omitnan') max(D.battMax,[],'omitnan') max(D.solarMax,[],'omitnan') max(D.lightMax,[],'omitnan')

];

MidAverage = [
mean(D.bmeTempMid,'omitnan') mean(D.dsTempMid,'omitnan') mean(D.bmeHumMid,'omitnan') mean(D.bmePresMid,'omitnan') mean(D.battMid,'omitnan')
mean(D.solarMid,'omitnan')
mean(D.lightMid,'omitnan')
];

Summary = table(Parameter, OverallMin, OverallMax, MidAverage); Summary

Summary = 7×4 table

| Parameter | OverallMin | OverallMax | MidAverage
1 | "BME Temp (C)" | 21.3000 | 23.9100 | 22.9063
2 | "DS Temp (C)" | 20.2500 | 21 | 20.7584
3 | "Humidity (%)" | 41.9800 | 56.9300 | 43.9452
4 | "Pressure (hPa)" | 1.0075e+03 | 1.0081e+03 | 1.0078e+03
5 | "Battery (V)" | 5.8400 | 7.1300 | 6.5820
6 | "Solar (V)" | 0.0400 | 3.7300 | 2.1664
7 | "Light (raw)" | 464 | 3227 | 2.3468e+03

%% warning table
tempWarnCount = sum((D.bmeTempMax > tempWarnC) | (D.dsTempMax > tempWarnC));
humWarnCount = sum(D.bmeHumMax > humWarnHigh);

WarningSummary = table( ...
runToUse, ...
height(D), ...
tempWarnCount, ...
humWarnCount, ...
100*tempWarnCount/height(D), ...
100*humWarnCount/height(D), ...
'VariableNames', ...

{'Run','Intervals','TempWarningCount','HumidityWarningCount','TempWarningPercent','H umidityWarningPercent'});

WarningSummary

WarningSummary = 1×6 table

| Run | Intervals | TempWarningCount | HumidityWarningCount
1 | 8 | 1381 | 0 | 0

%% light summary
lightCat = categorical(D.lightState);
cats = categories(lightCat);
counts = countcats(lightCat);

LightSummary = table(cats, counts, 100*counts/sum(counts), ... 'VariableNames', {'LightState','Count','Percent'});

LightSummary

LightSummary = 2×3 table

| LightState | Count | Percent
1 | 'DARK' | 34 | 2.4620
2 | 'NORMAL' | 1347 | 97.5380

%% simple conclusions
fprintf('\n================ SIMPLE CONCLUSIONS ================\n');

================ SIMPLE CONCLUSIONS ================

fprintf('Run analyzed: RUN%d\n', runToUse);

Run analyzed: RUN8
fprintf('Total run time analyzed: %.2f s\n', max(D.timeSec));

Total run time analyzed: 2799.76 s

fprintf('\nTemperature:\n');

Temperature:
fprintf('- Average BME temperature midpoint: %.2f C\n', mean(D.bmeTempMid,'omitnan'));
- Average BME temperature midpoint: 22.91 C
fprintf('- Average DS temperature midpoint: %.2f C\n', mean(D.dsTempMid,'omitnan'));
- Average DS temperature midpoint: 20.76 C
fprintf('- Highest temperature observed: %.2f C\n', ... max([max(D.bmeTempMax,[],'omitnan'), max(D.dsTempMax,[],'omitnan')]));
- Highest temperature observed: 23.91 C

fprintf('\nHumidity:\n');

Humidity:
fprintf('- Average humidity midpoint: %.2f %%\n', mean(D.bmeHumMid,'omitnan'));
- Average humidity midpoint: 43.95 %
fprintf('- Highest humidity observed: %.2f %%\n', max(D.bmeHumMax,[],'omitnan'));
- Highest humidity observed: 56.93 %

fprintf('\nPressure:\n');

Pressure:
fprintf('- Average pressure midpoint: %.2f hPa\n', mean(D.bmePresMid,'omitnan'));
- Average pressure midpoint: 1007.78 hPa

fprintf('\nPower:\n');

Power:
fprintf('- Average battery midpoint: %.2f V\n', mean(D.battMid,'omitnan'));
- Average battery midpoint: 6.58 V
fprintf('- Average solar midpoint: %.2f V\n', mean(D.solarMid,'omitnan'));
- Average solar midpoint: 2.17 V

fprintf('\nWarnings:\n');

Warnings:
if tempWarnCount == 0
fprintf('- No temperature warning intervals occurred.\n');
else
fprintf('- Temperature warnings occurred in %d intervals.\n', tempWarnCount); end
- No temperature warning intervals occurred.

if humWarnCount == 0
fprintf('- No humidity warning intervals occurred.\n');
else
fprintf('- Humidity warnings occurred in %d intervals.\n', humWarnCount); end
- No humidity warning intervals occurred.

if ~isempty(cats)
[~, idx] = max(counts);
fprintf('\nLight:\n');
fprintf('- Most common light state was %s.\n', string(cats(idx))); end

Light:
- Most common light state was NORMAL.

accSpread = mean([ ...
max(D.axMax,[],'omitnan') - min(D.axMin,[],'omitnan'), ... max(D.ayMax,[],'omitnan') - min(D.ayMin,[],'omitnan'), ... max(D.azMax,[],'omitnan') - min(D.azMin,[],'omitnan')], 'omitnan');

gyroSpread = mean([ ...
max(D.gxMax,[],'omitnan') - min(D.gxMin,[],'omitnan'), ... max(D.gyMax,[],'omitnan') - min(D.gyMin,[],'omitnan'), ... max(D.gzMax,[],'omitnan') - min(D.gzMin,[],'omitnan')], 'omitnan');

fprintf('\nMotion:\n');

Motion:
if accSpread < 0.05 && gyroSpread < 10 fprintf('- Motion appears low and stable.\n'); elseif accSpread < 0.3 && gyroSpread < 50
fprintf('- Motion appears moderate.\n');
else
fprintf('- Motion appears strong or highly variable.\n'); end
- Motion appears strong or highly variable.

function x = makeNum(s)
s = strtrim(string(s));

if s == "NA" || s == ""
x = NaN;
else
x = str2double(s);
end
end

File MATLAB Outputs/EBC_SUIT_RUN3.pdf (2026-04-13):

## KEVIN JAUKI

%% Environmental Brain Cube - Suitability Analysis
% This script looks at one suitability run from the log file. %
% It does these things:
% - reads the suitability log
% - picks one run
% - works with old or new log format
% - compares values to expected ranges
% - checks if values seem stable or drifting % - makes plots for all main variables
% - gives a simple long term decision

clear; clc; close all;

%% settings
fileName = "ebc_suitability_log.csv";
runChoice = "3"; % "latest" or a run number like "2" (make sure run number is accurate and quoted"")

showMinMaxBands = true;
showTrendLines = true;
useGroundTempInCore = true;

% prediction window settings predictionMaxHours = 24;
predictionMinExtraFrac = 0.10; predictionMaxExtraFrac = 0.80;

% settling OR trend behavior settings prediction.recentFrac = 0.30; prediction.startFrac = 0.20; prediction.settleSlopeFrac = 0.35; prediction.returnFrac = 0.25; prediction.maxSettleHours = 8; prediction.maxLinearHours = 24; prediction.minPointsRecent = 6;

% prediction settings for battery / solar prediction.minSlopeForLinear = 0.02; prediction.energyMinSlopeForLinear = 0.05; prediction.energySettleSlopeFrac = 0.20;

% curved prediction settings prediction.allowCurved = true; prediction.curveImproveFrac = 0.90;

prediction.minCurveStrength = 0.002; prediction.maxCurveAccelFrac = 0.80; prediction.curvePoints = 140;

% keep graph future time under control
prediction.graphMaxHours = 24;

% power settings
powerCfg.measuredSystemCurrentA = 0.09; | % measured max system draw
powerCfg.measuredSupplyVoltageV = 5.83; | % measured supply voltage
powerCfg.solarRatedVoltageV = 5.0; | % panel rated voltage
powerCfg.solarRatedCurrentA = 0.20; | % panel rated current
powerCfg.solarRatedPowerW = powerCfg.solarRatedVoltageV * powerCfg.solarRatedCurrentA;

% simple battery charge assumption
% this is just an estimate from available solar power powerCfg.assumedBatteryVoltageV = 5.83; % use measured supply side as simple estimate
powerCfg.assumedBatteryCapacitymAh = 500; | % change if using a different battery
powerCfg.chargeEfficiency = 0.80; | % assumed charging loss estimate

% EXPECTED RANGES
% should match Arduino code
expected.TempAirMin = 20.0;
expected.TempAirMax = 25.0;

expected.TempGroundMin = 20.0; expected.TempGroundMax = 25.0;

expected.HumMin = 40.0;
expected.HumMax = 55.0;

expected.PresMin = 950.0;
expected.PresMax = 1050.0;

expected.BattMin = 5.00;
expected.BattMax = 7.20;

expected.SolarMin = 3.50;
expected.SolarMax = 5.50;

expected.LightMin = 0;
expected.LightMax = 4095;

expected.AxMin = -16.0; expected.AxMax = 16.0; expected.AyMin = -16.0; expected.AyMax = 16.0; expected.AzMin = -16.0; expected.AzMax = 16.0;

expected.GxMin = -250.0; expected.GxMax = 250.0;

expected.GyMin = -250.0; expected.GyMax = 250.0; expected.GzMin = -250.0; expected.GzMax = 250.0;

%% long term decision settings longTerm.centerGoodThreshold = 70; longTerm.centerMarginalThreshold = 45;

longTerm.nearFutureHoursCritical = 24; longTerm.nearFutureHoursWatch = 168;

longTerm.maxDriftTempC = 1.5; longTerm.maxDriftHumPct = 5.0; longTerm.maxDriftPreshPa = 3.0; longTerm.maxDriftBattV = 0.25; longTerm.maxDriftSolarV = 0.35;

longTerm.minDirectionalFraction = 0.70; longTerm.windowFraction = 0.20;

%% check file
if ~isfile(fileName)
error("File not found: " + fileName); end

%% read file lines
txt = fileread(fileName);
lines = splitlines(string(txt)); lines = strtrim(lines);
lines = lines(lines ~= "");

%% keep only real run rows dataLines = strings(0,1);

for i = 1:numel(lines)
lineNow = lines(i);

if startsWith(lineNow, "RUN") && ~startsWith(lineNow, "=== RUN") dataLines(end+1,1) = lineNow; %#ok<SAGROW>
end
end

if isempty(dataLines)
error("No valid RUN rows found."); end

%% detect log format
firstParts = split(dataLines(1), ","); numCols = numel(firstParts);

oldFormatCols = 19;

newFormatCols = 33;

if numCols == oldFormatCols logFormat = "old_single_value"; elseif numCols >= newFormatCols
logFormat = "new_min_max";
else
error("Unknown suitability log format. Found %d columns.", numCols); end

fprintf("Detected log format: %s\n", logFormat);

Detected log format: new_min_max

%% create arrays
N = numel(dataLines);

runNum = nan(N,1);
timeSec = nan(N,1);

lightMin = nan(N,1); lightMax = nan(N,1); lightMid = nan(N,1); lightState = strings(N,1);

bmeTempMin = nan(N,1); bmeTempMax = nan(N,1); bmeTempMid = nan(N,1); bmeHumMin = nan(N,1); bmeHumMax = nan(N,1); bmeHumMid = nan(N,1); bmePresMin = nan(N,1); bmePresMax = nan(N,1); bmePresMid = nan(N,1); dsTempMin = nan(N,1); dsTempMax = nan(N,1); dsTempMid = nan(N,1);

battMin = nan(N,1); battMax = nan(N,1); battMid = nan(N,1); solarMin = nan(N,1); solarMax = nan(N,1); solarMid = nan(N,1);

axMin = nan(N,1); axMax = nan(N,1); axMid = nan(N,1);
ayMin = nan(N,1); ayMax = nan(N,1); ayMid = nan(N,1);
azMin = nan(N,1); azMax = nan(N,1); azMid = nan(N,1);

gxMin = nan(N,1); gxMax = nan(N,1); gxMid = nan(N,1); gyMin = nan(N,1); gyMax = nan(N,1); gyMid = nan(N,1); gzMin = nan(N,1); gzMax = nan(N,1); gzMid = nan(N,1);

tempWarn = nan(N,1);
humWarn = nan(N,1);
presWarn = nan(N,1);

%% read rows
for i = 1:N
p = split(dataLines(i), ",");
p = strtrim(p);

runNum(i) = sscanf(p(1), "RUN%d"); timeSec(i) = toNum(p(3));

if logFormat == "old_single_value" lightMid(i) = toNum(p(4));
lightMin(i) = lightMid(i);
lightMax(i) = lightMid(i);
lightState(i) = classifyLight(lightMid(i), 1000, 3800);

bmeTempMid(i) = toNum(p(5)); bmeTempMin(i) = bmeTempMid(i); bmeTempMax(i) = bmeTempMid(i);
bmeHumMid(i) = toNum(p(6)); bmeHumMin(i) = bmeHumMid(i); bmeHumMax(i) = bmeHumMid(i);
bmePresMid(i) = toNum(p(7)); bmePresMin(i) = bmePresMid(i); bmePresMax(i) = bmePresMid(i);
dsTempMid(i) = toNum(p(8)); dsTempMin(i) = dsTempMid(i); dsTempMax(i) = dsTempMid(i);
battMid(i) = toNum(p(9)); | battMin(i) = battMid(i); | battMax(i) =
battMid(i);
solarMid(i) = toNum(p(10)); solarMin(i) = solarMid(i); solarMax(i) = solarMid(i);

axMid(i) = toNum(p(11)); axMin(i) = axMid(i); axMax(i) = axMid(i); ayMid(i) = toNum(p(12)); ayMin(i) = ayMid(i); ayMax(i) = ayMid(i); azMid(i) = toNum(p(13)); azMin(i) = azMid(i); azMax(i) = azMid(i);

gxMid(i) = toNum(p(14)); gxMin(i) = gxMid(i); gxMax(i) = gxMid(i); gyMid(i) = toNum(p(15)); gyMin(i) = gyMid(i); gyMax(i) = gyMid(i); gzMid(i) = toNum(p(16)); gzMin(i) = gzMid(i); gzMax(i) = gzMid(i);

tempWarn(i) = toNum(p(17));
humWarn(i) = toNum(p(18));
presWarn(i) = toNum(p(19));

else
lightMin(i) = toNum(p(4));
lightMax(i) = toNum(p(5));
lightMid(i) = mean([lightMin(i), lightMax(i)], 'omitnan');
lightState(i) = string(p(6));
bmeTempMin(i) = toNum(p(7)); | bmeTempMax(i) = toNum(p(8)); | bmeTempMid(i)
= mean([bmeTempMin(i), bmeTempMax(i)], 'omitnan'); bmeHumMin(i) = toNum(p(9)); bmeHumMax(i) = toNum(p(10)); bmeHumMid(i) = mean([bmeHumMin(i), bmeHumMax(i)], 'omitnan'); bmePresMin(i) = toNum(p(11)); bmePresMax(i) = toNum(p(12)); bmePresMid(i) = mean([bmePresMin(i), bmePresMax(i)], 'omitnan'); dsTempMin(i) = toNum(p(13)); dsTempMax(i) = toNum(p(14)); dsTempMid(i) = mean([dsTempMin(i), dsTempMax(i)], 'omitnan');
battMin(i) = toNum(p(15)); | battMax(i) = toNum(p(16)); | battMid(i) =
mean([battMin(i), battMax(i)], 'omitnan');

solarMin(i) = toNum(p(17)); solarMax(i) = toNum(p(18)); solarMid(i) = mean([solarMin(i), solarMax(i)], 'omitnan');

axMin(i) = toNum(p(19)); axMax(i) = toNum(p(20)); axMid(i) = mean([axMin(i), axMax(i)], 'omitnan'); ayMin(i) = toNum(p(21)); ayMax(i) = toNum(p(22)); ayMid(i) = mean([ayMin(i), ayMax(i)], 'omitnan'); azMin(i) = toNum(p(23)); azMax(i) = toNum(p(24)); azMid(i) = mean([azMin(i), azMax(i)], 'omitnan');

gxMin(i) = toNum(p(25)); gxMax(i) = toNum(p(26)); gxMid(i) = mean([gxMin(i), gxMax(i)], 'omitnan'); gyMin(i) = toNum(p(27)); gyMax(i) = toNum(p(28)); gyMid(i) = mean([gyMin(i), gyMax(i)], 'omitnan'); gzMin(i) = toNum(p(29)); gzMax(i) = toNum(p(30)); gzMid(i) = mean([gzMin(i), gzMax(i)], 'omitnan');

tempWarn(i) = toNum(p(31));
humWarn(i) = toNum(p(32));
presWarn(i) = toNum(p(33)); end
end

%% make table
T = table(runNum,timeSec, ... lightMin,lightMax,lightMid,lightState, ... bmeTempMin,bmeTempMax,bmeTempMid, ... bmeHumMin,bmeHumMax,bmeHumMid, ... bmePresMin,bmePresMax,bmePresMid, ... dsTempMin,dsTempMax,dsTempMid, ... battMin,battMax,battMid, ... solarMin,solarMax,solarMid, ... axMin,axMax,axMid, ...
ayMin,ayMax,ayMid, ...
azMin,azMax,azMid, ...
gxMin,gxMax,gxMid, ...
gyMin,gyMax,gyMid, ...
gzMin,gzMax,gzMid, ...
tempWarn,humWarn,presWarn);

%% choose run
runs = unique(T.runNum);
runs = runs(~isnan(runs));

if isempty(runs)
error("No valid runs found."); end

if runChoice == "latest"
runToUse = max(runs);

else
runToUse = double(runChoice); end

D = T(T.runNum == runToUse, :);
D = sortrows(D, "timeSec");

if isempty(D)
error("Selected run not found."); end

fprintf("Using RUN%d\n", runToUse);

Using RUN3
fprintf("Rows logged: %d\n", height(D));

Rows logged: 248
fprintf("Run duration: %.2f s\n", max(D.timeSec));

Run duration: 500.01 s

%% average values
runDurationSec = max(D.timeSec);

avgAirTemp = mean(D.bmeTempMid, 'omitnan'); avgGroundTemp = mean(D.dsTempMid, 'omitnan'); avgHum = mean(D.bmeHumMid, 'omitnan'); avgPres = mean(D.bmePresMid, 'omitnan'); avgBatt = mean(D.battMid, 'omitnan'); avgSolar = mean(D.solarMid, 'omitnan'); avgLight = mean(D.lightMid, 'omitnan');

avgAx = mean(D.axMid, 'omitnan'); avgAy = mean(D.ayMid, 'omitnan'); avgAz = mean(D.azMid, 'omitnan');

avgGx = mean(D.gxMid, 'omitnan'); avgGy = mean(D.gyMid, 'omitnan');
avgGz = mean(D.gzMid, 'omitnan');

summaryStats = table( ...
avgAirTemp, avgGroundTemp, avgHum, avgPres, avgBatt, avgSolar, avgLight, ... avgAx, avgAy, avgAz, avgGx, avgGy, avgGz, ...
'VariableNames', {'AvgAirTemp','AvgGroundTemp','AvgHumidity','AvgPressure', ...

'AvgBattery','AvgSolar','AvgLight','AvgAx','AvgAy','AvgAz','AvgGx','AvgGy','AvgGz'}) ;

disp("Run average values:")

Run average values:
disp(summaryStats)
AvgAirTemp | AvgGroundTemp | AvgHumidity | AvgPressure | AvgBattery | AvgSolar | AvgLight | AvgAx | AvgAy | AvgAz | AvgGx | AvgGy | AvgGz
__________ | _____________ | ___________ | ___________ | __________ | ________ | ________ | _______ | ________ | ______ | _______ | _____ | _______
22.782 | 20.447 | 46.284 | 1008.1 | 5.7183 | 4.7869 | 3781.9 | 0.31395 | -0.71393 | 8.9636 | 0.88518 | 1.047 | -1.6077

%% compare averages to expected ranges
[airPass, airClose, airOffset] = compareToRange(avgAirTemp, expected.TempAirMin,
expected.TempAirMax);
[groundPass, groundClose, groundOffset] = compareToRange(avgGroundTemp, expected.TempGroundMin, expected.TempGroundMax);
[humPass, humClose, humOffset] = compareToRange(avgHum, expected.HumMin, expected.HumMax);
[presPass, presClose, presOffset] = compareToRange(avgPres, expected.PresMin, expected.PresMax);

[battPass, battClose, battOffset] = compareToRange(avgBatt, expected.BattMin, expected.BattMax);
[solarPass, solarClose, solarOffset] = compareToRange(avgSolar, expected.SolarMin, expected.SolarMax);
[lightPass, lightClose, lightOffset] = compareToRange(avgLight, expected.LightMin, expected.LightMax);

[axPass, axClose, axOffset] = compareToRange(avgAx, expected.AxMin, expected.AxMax); [ayPass, ayClose, ayOffset] = compareToRange(avgAy, expected.AyMin, expected.AyMax); [azPass, azClose, azOffset] = compareToRange(avgAz, expected.AzMin, expected.AzMax);

[gxPass, gxClose, gxOffset] = compareToRange(avgGx, expected.GxMin, expected.GxMax); [gyPass, gyClose, gyOffset] = compareToRange(avgGy, expected.GyMin, expected.GyMax); [gzPass, gzClose, gzOffset] = compareToRange(avgGz, expected.GzMin, expected.GzMax);

Parameter = [ ...
"Air Temperature"; "Ground Temperature"; "Humidity"; "Pressure"; ...
"Battery"; "Solar"; "Light"; ...
"Accel X"; "Accel Y"; "Accel Z"; ...
"Gyro X"; "Gyro Y"; "Gyro Z"];

RunAverage = [ ...
avgAirTemp; avgGroundTemp; avgHum; avgPres; ... avgBatt; avgSolar; avgLight; ...
avgAx; avgAy; avgAz; ...
avgGx; avgGy; avgGz];

TargetMin = [ ...
expected.TempAirMin; expected.TempGroundMin; expected.HumMin; expected.PresMin; ...
expected.BattMin; expected.SolarMin; expected.LightMin; ...

expected.AxMin; expected.AyMin; expected.AzMin; ...
expected.GxMin; expected.GyMin; expected.GzMin];

TargetMax = [ ...
expected.TempAirMax; expected.TempGroundMax; expected.HumMax; expected.PresMax; ...
expected.BattMax; expected.SolarMax; expected.LightMax; ...
expected.AxMax; expected.AyMax; expected.AzMax; ...
expected.GxMax; expected.GyMax; expected.GzMax];

Pass = [ ...
airPass; groundPass; humPass; presPass; ... battPass; solarPass; lightPass; ...
axPass; ayPass; azPass; ...
gxPass; gyPass; gzPass];

ClosenessPercent = [ ...
airClose; groundClose; humClose; presClose; ... battClose; solarClose; lightClose; ... axClose; ayClose; azClose; ...
gxClose; gyClose; gzClose];

CenterOffsetPercent = [ ...
airOffset; groundOffset; humOffset; presOffset; ... battOffset; solarOffset; lightOffset; ...
axOffset; ayOffset; azOffset; ...
gxOffset; gyOffset; gzOffset];

ComparisonTable = table(Parameter, RunAverage, TargetMin, TargetMax, ... Pass, ClosenessPercent, CenterOffsetPercent);

disp("Comparison to expected ranges:")

Comparison to expected ranges:
disp(ComparisonTable)
Parameter | RunAverage | TargetMin | TargetMax | Pass | ClosenessPercent | CenterOffsetPercent
____________________ | __________ | _________ | _________ | _____ | ________________ | ___________________
"Air Temperature" | 22.782 | 20 | 25 | true | 88.716 | 11.284
"Ground Temperature" | 20.447 | 20 | 25 | true | 17.868 | 82.132
"Humidity" | 46.284 | 40 | 55 | true | 83.793 | 16.207
"Pressure" | 1008.1 | 950 | 1050 | true | 83.735 | 16.265
"Battery" | 5.7183 | 5 | 7.2 | true | 65.299 | 34.701
"Solar" | 4.7869 | 3.5 | 5.5 | true | 71.315 | 28.685
"Light" | 3781.9 | 0 | 4095 | true | 15.291 | 84.709
"Accel X" | 0.31395 | -16 | 16 | true | 98.038 | 1.9622
"Accel Y" | -0.71393 | -16 | 16 | true | 95.538 | 4.4621
"Accel Z" | 8.9636 | -16 | 16 | true | 43.978 | 56.022
"Gyro X" | 0.88518 | -250 | 250 | true | 99.646 | 0.35407
"Gyro Y" | 1.047 | -250 | 250 | true | 99.581 | 0.41879
"Gyro Z" | -1.6077 | -250 | 250 | true | 99.357 | 0.64307

%% trend and drift checks
timeHr = D.timeSec / 3600;

trend.airTemp = analyzeLongTermTrend(timeHr, D.bmeTempMid, expected.TempAirMin, expected.TempAirMax, ...
longTerm.maxDriftTempC, longTerm.minDirectionalFraction, longTerm.windowFraction);

trend.groundTemp = analyzeLongTermTrend(timeHr, D.dsTempMid, expected.TempGroundMin, expected.TempGroundMax, ... longTerm.maxDriftTempC, longTerm.minDirectionalFraction, longTerm.windowFraction);

trend.humidity = analyzeLongTermTrend(timeHr, D.bmeHumMid, expected.HumMin, expected.HumMax, ...
longTerm.maxDriftHumPct, longTerm.minDirectionalFraction, longTerm.windowFraction);

trend.pressure = analyzeLongTermTrend(timeHr, D.bmePresMid, expected.PresMin, expected.PresMax, ...
longTerm.maxDriftPreshPa, longTerm.minDirectionalFraction, longTerm.windowFraction);

trend.battery = analyzeLongTermTrend(timeHr, D.battMid, expected.BattMin, expected.BattMax, ...
longTerm.maxDriftBattV, longTerm.minDirectionalFraction, longTerm.windowFraction);

trend.solar = analyzeLongTermTrend(timeHr, D.solarMid, expected.SolarMin, expected.SolarMax, ...
longTerm.maxDriftSolarV, longTerm.minDirectionalFraction, longTerm.windowFraction);

TrendSummary = table( ...
["Air Temp"; "Ground Temp"; "Humidity"; "Pressure"; "Battery"; "Solar"], ... [trend.airTemp.startEndDrift; trend.groundTemp.startEndDrift; trend.humidity.startEndDrift; ...
trend.pressure.startEndDrift; trend.battery.startEndDrift; trend.solar.startEndDrift], ...
[trend.airTemp.directionalFraction; trend.groundTemp.directionalFraction; trend.humidity.directionalFraction; ...
trend.pressure.directionalFraction; trend.battery.directionalFraction; trend.solar.directionalFraction], ...
[displayBoundaryTime(trend.airTemp); displayBoundaryTime(trend.groundTemp); displayBoundaryTime(trend.humidity); ...
displayBoundaryTime(trend.pressure); displayBoundaryTime(trend.battery); displayBoundaryTime(trend.solar)], ...
[string(trend.airTemp.behavior); string(trend.groundTemp.behavior); string(trend.humidity.behavior); ...

string(trend.pressure.behavior); string(trend.battery.behavior); string(trend.solar.behavior)], ...
'VariableNames',
{'Parameter','StartEndDrift','DirectionalFraction','TimeToBoundaryHours','Behavior'} );

disp("Trend summary:")

Trend summary:
disp(TrendSummary)
Parameter | StartEndDrift | DirectionalFraction | TimeToBoundaryHours | Behavior
_____________ | _____________ | ___________________ | ___________________ | ________
"Air Temp" | -0.8096 | 0.61943 | NaN | "STABLE"
"Ground Temp" | -0.3235 | 0.19838 | NaN | "STABLE"
"Humidity" | 1.8919 | 0.53441 | NaN | "STABLE"
"Pressure" | 0.1113 | 0.43725 | NaN | "STABLE"
"Battery" | -0.1685 | 0.36437 | NaN | "STABLE"
"Solar" | -0.1539 | 0.40891 | NaN | "STABLE"

%% power calculations
D.battPowerW = D.battMid * powerCfg.measuredSystemCurrentA;

avgBattPowerW = mean(D.battPowerW, 'omitnan'); maxBattPowerW = max(D.battPowerW, [], 'omitnan'); battEnergyWhRun = integratePowerWh(D.timeSec, D.battPowerW);

% direct measured supply reference
measuredSupplyPowerW = powerCfg.measuredSupplyVoltageV * powerCfg.measuredSystemCurrentA;

% solar side estimate from rated panel power scaled by logged solar voltage solarVoltageFrac = max(0, min(1.20, D.solarMid / powerCfg.solarRatedVoltageV)); D.solarPowerEstW = powerCfg.solarRatedPowerW * solarVoltageFrac;

avgSolarPowerEstW = mean(D.solarPowerEstW, 'omitnan');
maxSolarPowerEstW = max(D.solarPowerEstW, [], 'omitnan');
solarEnergyEstWhRun = integratePowerWh(D.timeSec, D.solarPowerEstW);

% net margin
D.netPowerMarginW = D.solarPowerEstW - D.battPowerW;
avgNetPowerMarginW = mean(D.netPowerMarginW, 'omitnan');

% 24 h predicted voltage and power
battPred24hV = predictValueAtHours(D.timeSec, D.battMid, expected.BattMin, expected.BattMax, trend.battery, prediction, true, 24);
solarPred24hV = predictValueAtHours(D.timeSec, D.solarMid, expected.SolarMin, expected.SolarMax, trend.solar, prediction, true, 24);

if ~isnan(battPred24hV)

battPred24hPowerW = battPred24hV * powerCfg.measuredSystemCurrentA; else
battPred24hPowerW = NaN;
end

if ~isnan(solarPred24hV)
solarPred24hPowerW = powerCfg.solarRatedPowerW * max(0, min(1.20, solarPred24hV / powerCfg.solarRatedVoltageV));
else
solarPred24hPowerW = NaN;
end

% battery voltage-drop check
battDropRateVph = min(0, trend.battery.recentSlopePerHour);

if isnan(battDropRateVph)
battPowerDropAlignment = "NOT ENOUGH DATA";
elseif avgBattPowerW > 0 && battDropRateVph < 0 battPowerDropAlignment = "ALIGNS";
elseif avgBattPowerW > 0 && abs(battDropRateVph) < 1e-6 battPowerDropAlignment = "MOSTLY STABLE";
else
battPowerDropAlignment = "MIXED";
end

% solar trend check
solarSlopeVph = trend.solar.recentSlopePerHour;

if isnan(solarSlopeVph)
solarPowerTrendAlignment = "NOT ENOUGH DATA";
elseif avgSolarPowerEstW > avgBattPowerW && solarSlopeVph >= 0 solarPowerTrendAlignment = "ALIGNS";
elseif avgSolarPowerEstW > avgBattPowerW && solarSlopeVph < 0 solarPowerTrendAlignment = "HIGH BUT DROPPING";
elseif avgSolarPowerEstW <= avgBattPowerW && solarSlopeVph < 0 solarPowerTrendAlignment = "ALIGNS";
else
solarPowerTrendAlignment = "MIXED";
end

% battery charging estimate from solar surplus
% this is an assumed estimate, not a full battery model batteryEnergyWhAssumed = (powerCfg.assumedBatteryCapacitymAh / 1000) * powerCfg.assumedBatteryVoltageV;

if avgNetPowerMarginW > 0
chargeTimeHoursIdeal = batteryEnergyWhAssumed / avgNetPowerMarginW; chargeTimeHoursAdj = batteryEnergyWhAssumed / (avgNetPowerMarginW * powerCfg.chargeEfficiency);
else chargeTimeHoursIdeal = Inf; chargeTimeHoursAdj = Inf;
end

PowerSummary = table( ...
avgBattPowerW, maxBattPowerW, battEnergyWhRun, ... avgSolarPowerEstW, maxSolarPowerEstW, solarEnergyEstWhRun, ... avgNetPowerMarginW, measuredSupplyPowerW, ...
battPred24hV, battPred24hPowerW, ...
solarPred24hV, solarPred24hPowerW, ...
chargeTimeHoursIdeal, chargeTimeHoursAdj, ... string(battPowerDropAlignment), string(solarPowerTrendAlignment), ... 'VariableNames', {'AvgBattPowerW','MaxBattPowerW','BattEnergyWhRun', ... 'AvgSolarPowerEstW','MaxSolarPowerEstW','SolarEnergyEstWhRun', ... 'AvgNetPowerMarginW','MeasuredSupplyPowerW', ... 'BattPred24hV','BattPred24hPowerW', ... 'SolarPred24hV','SolarPred24hPowerW', ... 'ChargeTimeHrIdeal','ChargeTimeHrAdj', ... 'BattPowerVsDrop','SolarPowerVsTrend'});

disp("Power summary:")

Power summary:
disp(PowerSummary)
AvgBattPowerW | MaxBattPowerW | BattEnergyWhRun | AvgSolarPowerEstW | MaxSolarPowerEstW | SolarEnergyEstWhRun | AvgNetPowerMarginW | MeasuredSupplyPowerW | BattPred24hV | BattPred24hPowerW | SolarPred24hV | SolarPred24hPowerW | ChargeTimeHrIdeal | ChargeTimeHrAdj | BattPowerVsDrop | SolarPowerVsTrend
_____________ | _____________ | _______________ | _________________ | _________________ | ___________________ | __________________ | ____________________ | ____________ | _________________ | _____________ | __________________ | _________________ | _______________ | _______________ | ___________________
0.51465 | 0.5418 | 0.071257 | 0.95737 | 0.996 | 0.13259 | 0.44273 | 0.5247 | NaN | NaN | NaN | NaN | 6.5842 | 8.2303 | "ALIGNS" | "HIGH BUT DROPPING"

%% air temp vs ground temp
avgAirGroundDelta = mean(D.bmeTempMid - D.dsTempMid, 'omitnan');
maxAirGroundDelta = max(abs(D.bmeTempMid - D.dsTempMid), [], 'omitnan');

if nnz(~isnan(D.bmeTempMid) & ~isnan(D.dsTempMid)) >= 3
airGroundCorr = corr(D.bmeTempMid, D.dsTempMid, 'Rows', 'complete'); else
airGroundCorr = NaN;
end

ExtraSummary = table( ...
avgAirGroundDelta, maxAirGroundDelta, airGroundCorr, ... 'VariableNames',
{'AvgAirMinusGroundTempC','MaxAbsAirGroundTempDiffC','AirGroundCorrelation'});

disp("Extra deductions:")

Extra deductions:
disp(ExtraSummary)

AvgAirMinusGroundTempC | MaxAbsAirGroundTempDiffC | AirGroundCorrelation
______________________ | ________________________ | ____________________
2.3354 | 2.86 | 0.95298

%% long-term score
coreClosenessList = [airClose, humClose, presClose];

if useGroundTempInCore
coreClosenessList = [coreClosenessList, groundClose]; end

coreAverageCloseness = mean(coreClosenessList, 'omitnan');

coreTrendPenalty = 0;
coreComments = strings(0,1);

[coreTrendPenalty, coreComments] = applyRealDriftPenalty( ... coreTrendPenalty, coreComments, "Air temperature", trend.airTemp, ... longTerm.nearFutureHoursCritical, longTerm.nearFutureHoursWatch);

if useGroundTempInCore
[coreTrendPenalty, coreComments] = applyRealDriftPenalty( ... coreTrendPenalty, coreComments, "Ground temperature", trend.groundTemp, ... longTerm.nearFutureHoursCritical, longTerm.nearFutureHoursWatch);
end

[coreTrendPenalty, coreComments] = applyRealDriftPenalty( ... coreTrendPenalty, coreComments, "Humidity", trend.humidity, ... longTerm.nearFutureHoursCritical, longTerm.nearFutureHoursWatch);

[coreTrendPenalty, coreComments] = applyRealDriftPenalty( ... coreTrendPenalty, coreComments, "Pressure", trend.pressure, ... longTerm.nearFutureHoursCritical, longTerm.nearFutureHoursWatch);

longTermScore = max(0, coreAverageCloseness - coreTrendPenalty); supportAverageCloseness = mean([battClose, solarClose, lightClose], 'omitnan');

coreFail = strcmp(trend.airTemp.behavior, "UNSAFE_RISING") || ... strcmp(trend.humidity.behavior, "UNSAFE_RISING") || ... strcmp(trend.pressure.behavior, "UNSAFE_RISING");

if useGroundTempInCore
coreFail = coreFail || strcmp(trend.groundTemp.behavior, "UNSAFE_RISING"); end

if coreFail
longTermDecision = "NOT IDEAL FOR LONG-TERM USE";
elseif longTermScore >= longTerm.centerGoodThreshold longTermDecision = "LIKELY SUITABLE LONG-TERM";

elseif longTermScore >= longTerm.centerMarginalThreshold longTermDecision = "MARGINALLY SUITABLE LONG-TERM";
else
longTermDecision = "WATCH FOR NEAR-FUTURE ENVIRONMENTAL CHANGE"; end

%% warning percentages
tempWarnFraction = mean(D.tempWarn == 1, 'omitnan') * 100; humWarnFraction = mean(D.humWarn == 1, 'omitnan') * 100; presWarnFraction = mean(D.presWarn == 1, 'omitnan') * 100;

%% overall summary
OverallSummary = table( ...
runToUse, runDurationSec, ...
coreAverageCloseness, supportAverageCloseness, coreTrendPenalty, longTermScore, ...
tempWarnFraction, humWarnFraction, presWarnFraction, ... string(longTermDecision), ...
'VariableNames',
{'Run','DurationSec','CoreAverageClosenessPct','SupportAverageClosenessPct', ...

'CoreTrendPenalty','LongTermScorePct','TempWarnPct','HumWarnPct','PresWarnPct','Long TermDecision'});

disp("Overall suitability summary:")

Overall suitability summary:
disp(OverallSummary)
Run | DurationSec | CoreAverageClosenessPct | SupportAverageClosenessPct | CoreTrendPenalty | LongTermScorePct | TempWarnPct | HumWarnPct | PresWarnPct | LongTermDecision
___ | ___________ | _______________________ | __________________________ | ________________ | ________________ | ___________ | __________ | ___________ | _______________________________
3 | 500.01 | 68.528 | 50.635 | 0 | 68.528 | 0 | 0 | 0 | "MARGINALLY SUITABLE LONG-TERM"

%% plots
plotVariableWithBand(D.timeSec, D.bmeTempMin, D.bmeTempMax, D.bmeTempMid, ...
expected.TempAirMin, expected.TempAirMax, ...
"Air Temperature (BME)", "Temperature (C)", runToUse, ... showMinMaxBands, showTrendLines, trend.airTemp, prediction, predictionMinExtraFrac, predictionMaxExtraFrac, false);

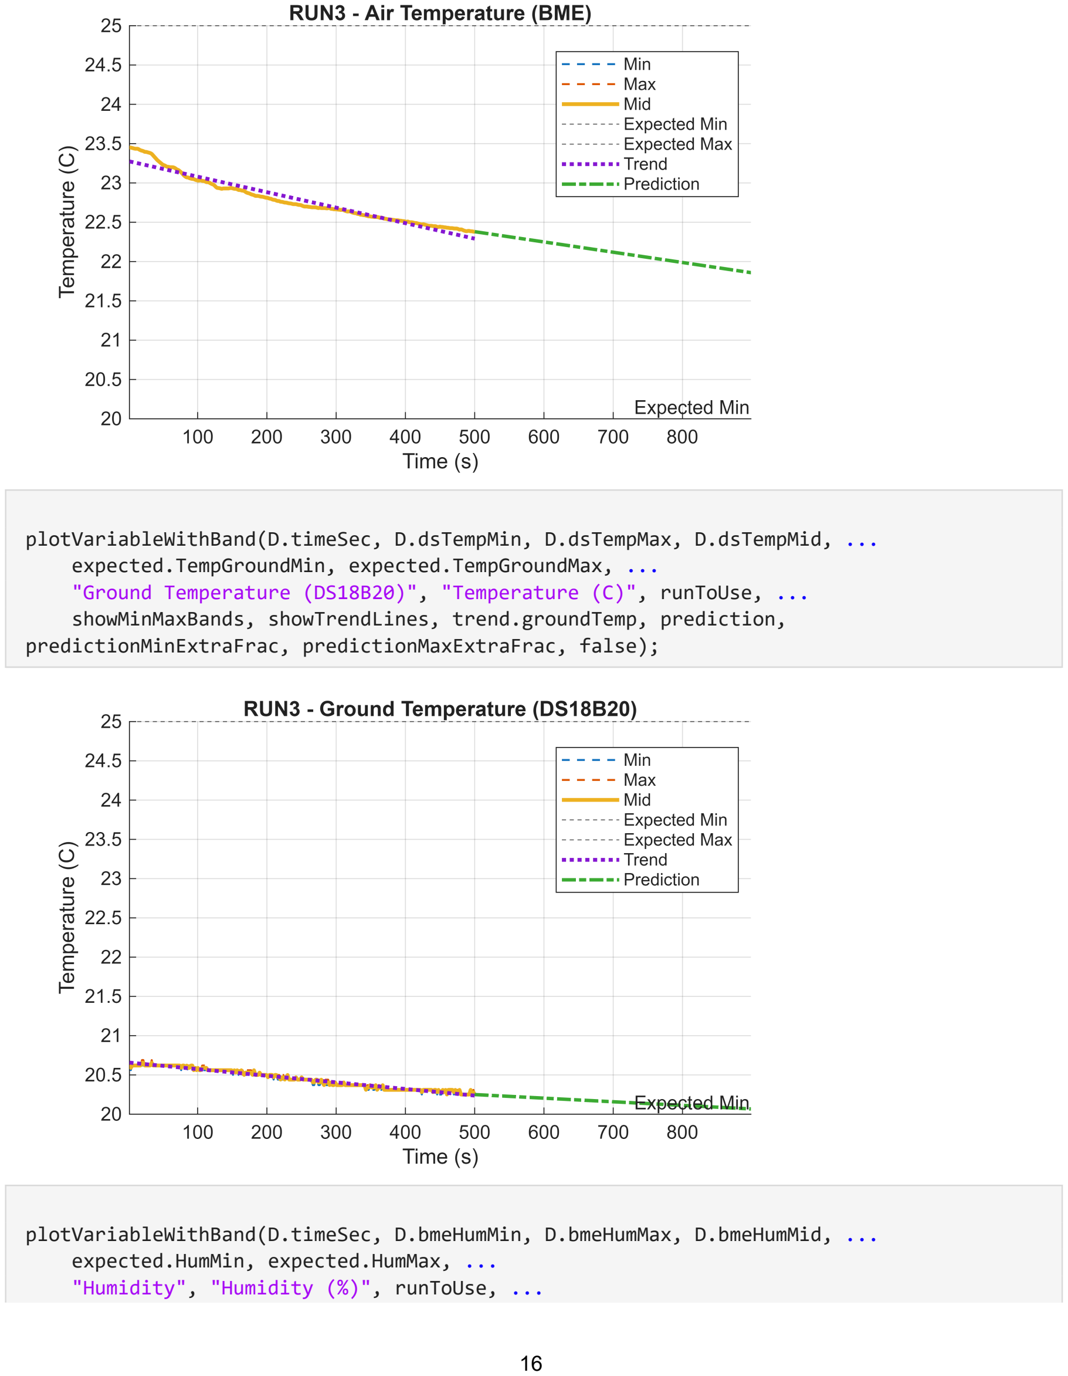
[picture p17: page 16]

plotVariableWithBand(D.timeSec, D.dsTempMin, D.dsTempMax, D.dsTempMid, ... expected.TempGroundMin, expected.TempGroundMax, ...
"Ground Temperature (DS18B20)", "Temperature (C)", runToUse, ... showMinMaxBands, showTrendLines, trend.groundTemp, prediction, predictionMinExtraFrac, predictionMaxExtraFrac, false);

plotVariableWithBand(D.timeSec, D.bmeHumMin, D.bmeHumMax, D.bmeHumMid, ... expected.HumMin, expected.HumMax, ...
"Humidity", "Humidity (%)", runToUse, ...

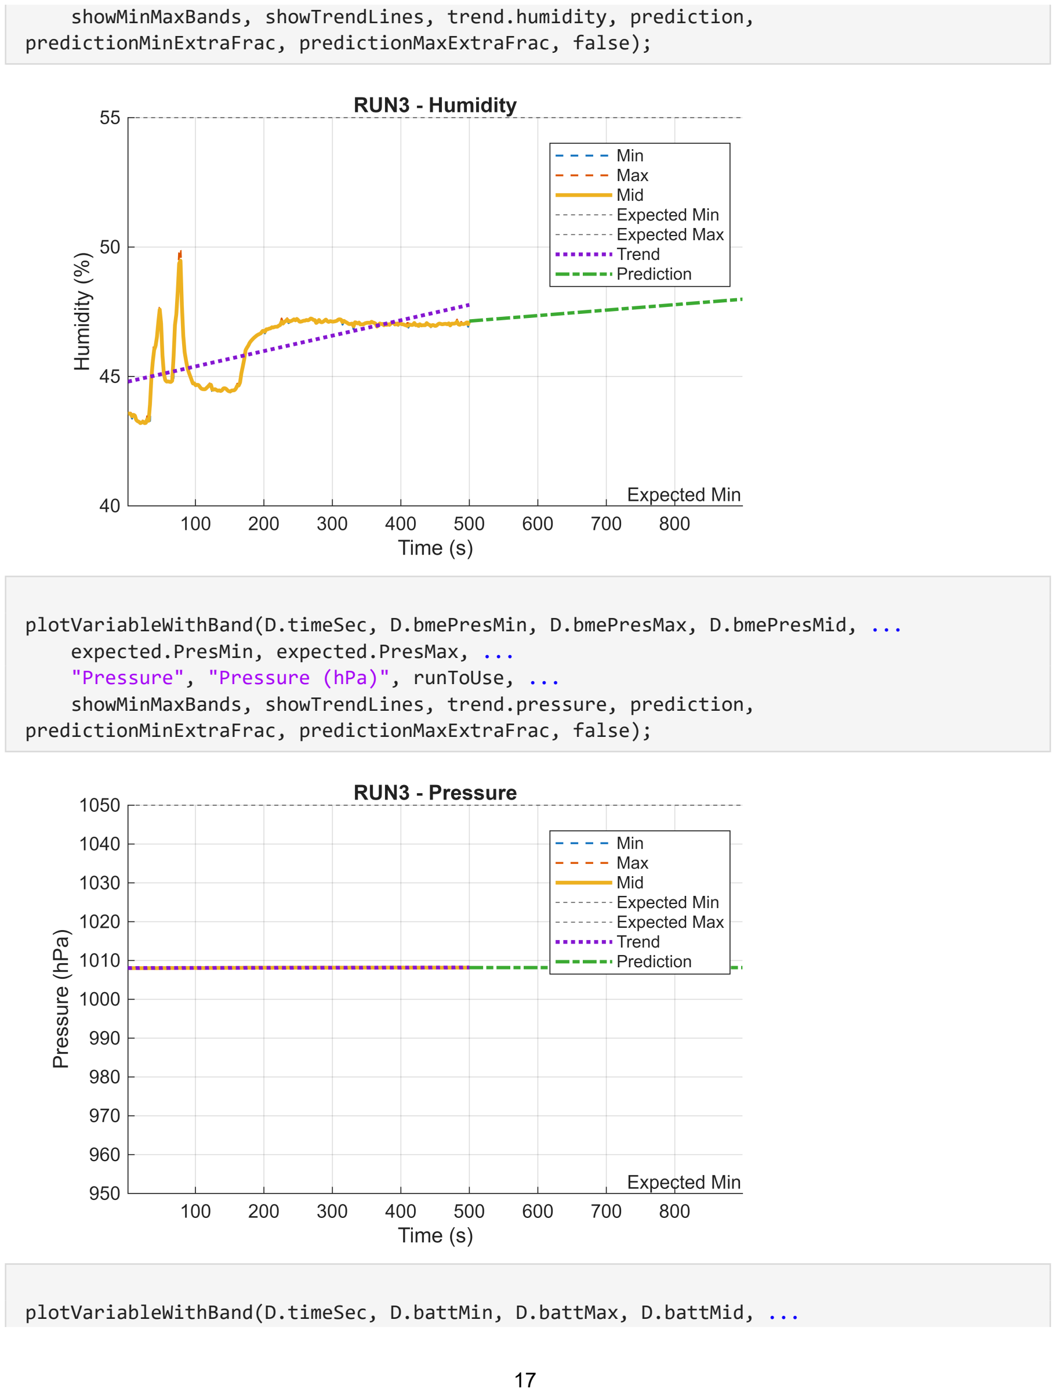
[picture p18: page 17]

showMinMaxBands, showTrendLines, trend.humidity, prediction, predictionMinExtraFrac, predictionMaxExtraFrac, false);

plotVariableWithBand(D.timeSec, D.bmePresMin, D.bmePresMax, D.bmePresMid, ... expected.PresMin, expected.PresMax, ...
"Pressure", "Pressure (hPa)", runToUse, ...
showMinMaxBands, showTrendLines, trend.pressure, prediction, predictionMinExtraFrac, predictionMaxExtraFrac, false);

plotVariableWithBand(D.timeSec, D.battMin, D.battMax, D.battMid, ...

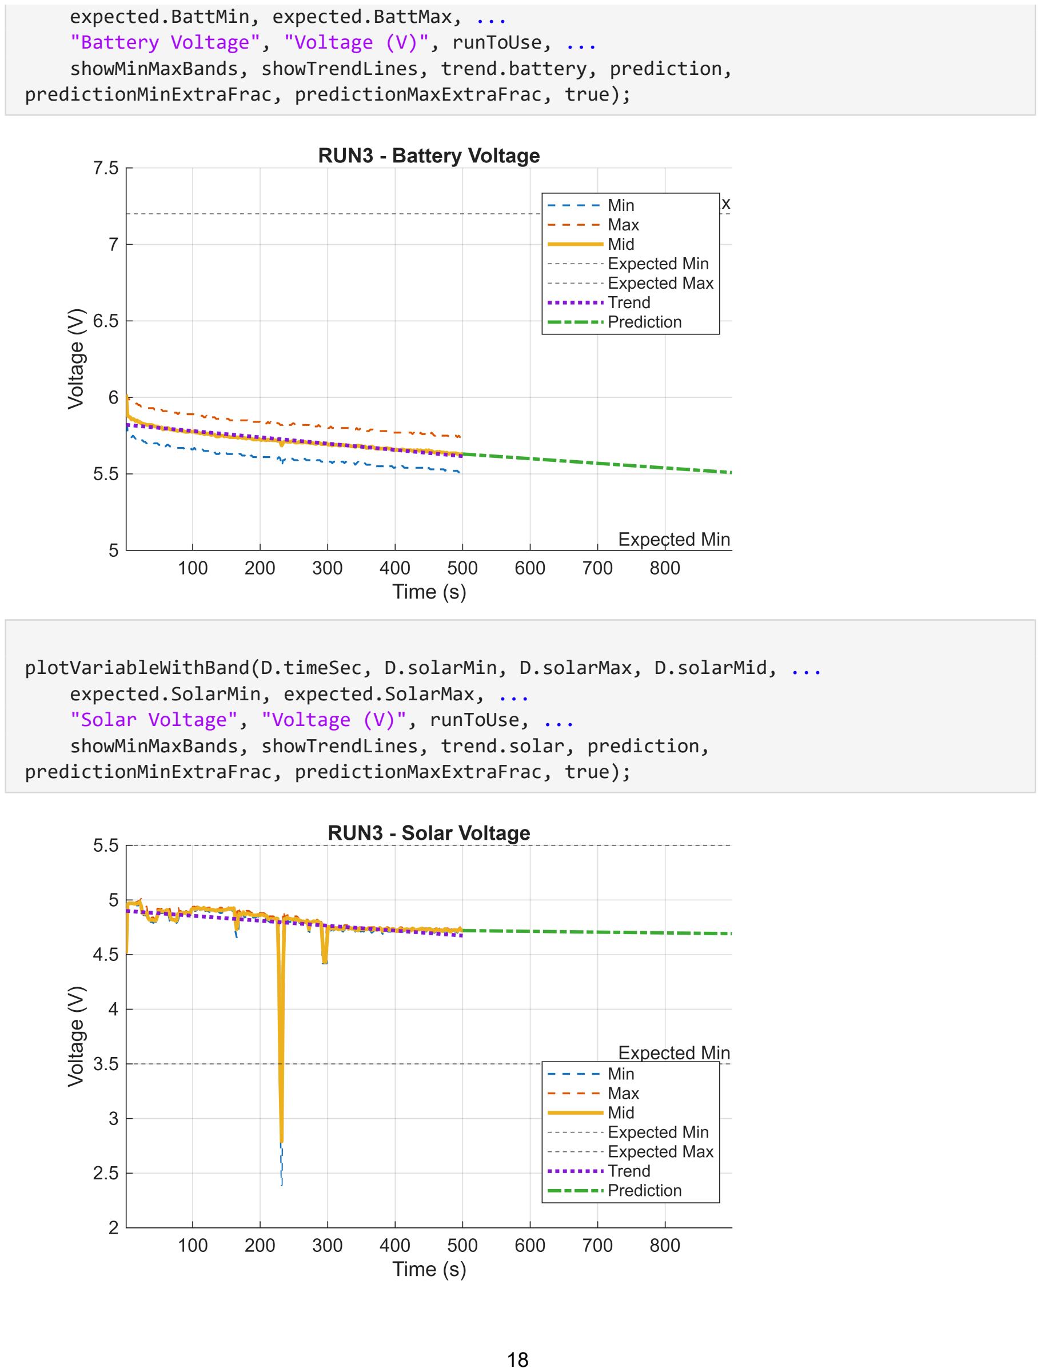
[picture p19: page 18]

expected.BattMin, expected.BattMax, ...
"Battery Voltage", "Voltage (V)", runToUse, ... showMinMaxBands, showTrendLines, trend.battery, prediction, predictionMinExtraFrac, predictionMaxExtraFrac, true);

plotVariableWithBand(D.timeSec, D.solarMin, D.solarMax, D.solarMid, ... expected.SolarMin, expected.SolarMax, ...
"Solar Voltage", "Voltage (V)", runToUse, ...
showMinMaxBands, showTrendLines, trend.solar, prediction, predictionMinExtraFrac, predictionMaxExtraFrac, true);

plotVariableWithBand(D.timeSec, D.lightMin, D.lightMax, D.lightMid, ... expected.LightMin, expected.LightMax, ...
"Light Raw", "Raw ADC", runToUse, ...
showMinMaxBands, showTrendLines, struct(), prediction, predictionMinExtraFrac, predictionMaxExtraFrac, false);

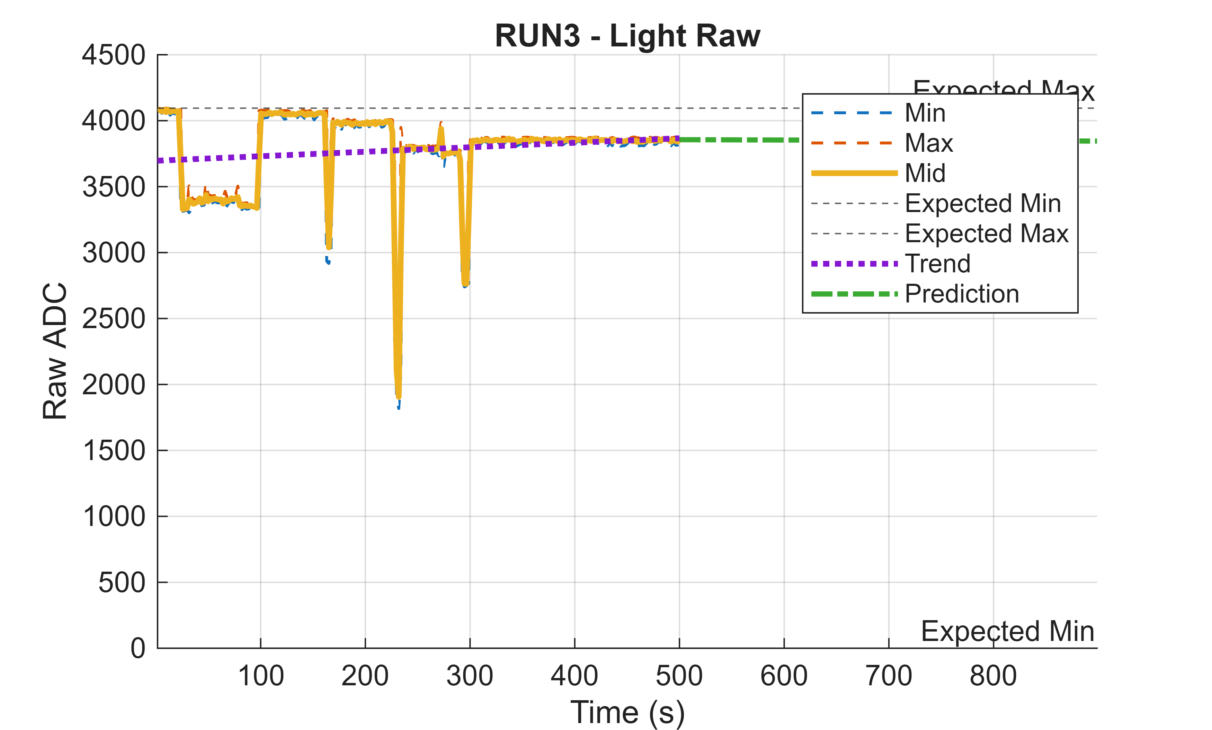
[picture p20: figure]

plotVariableWithBand(D.timeSec, D.axMin, D.axMax, D.axMid, ...
expected.AxMin, expected.AxMax, ...
"Acceleration X", "m/s^2", runToUse, ...
showMinMaxBands, showTrendLines, struct(), prediction, predictionMinExtraFrac, predictionMaxExtraFrac, false);

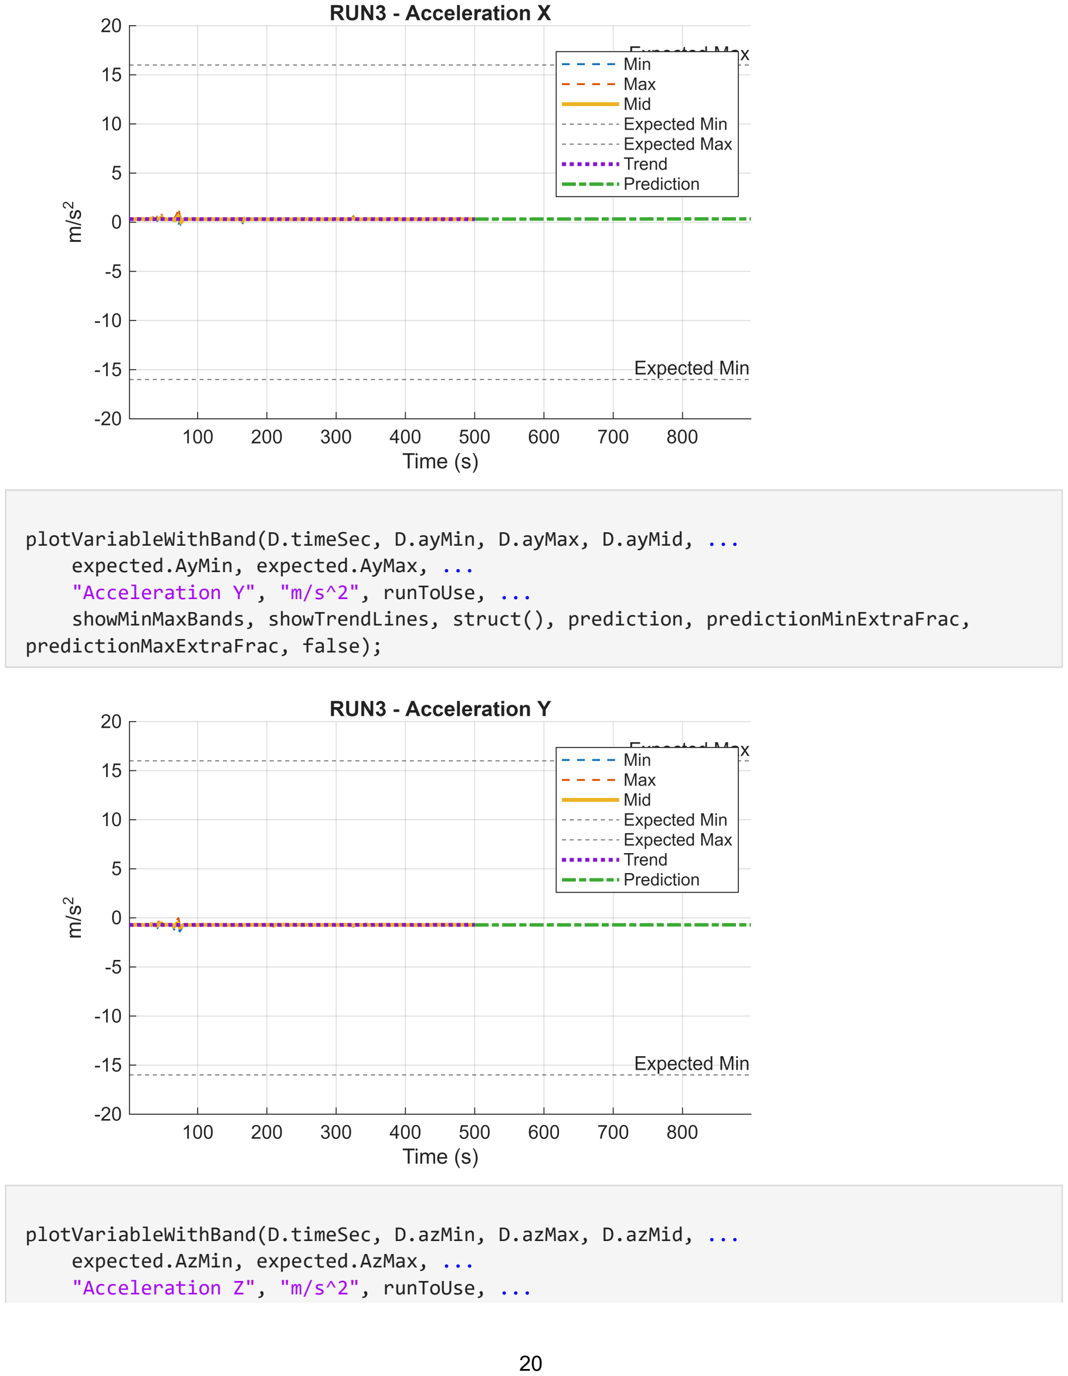
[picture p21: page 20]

plotVariableWithBand(D.timeSec, D.ayMin, D.ayMax, D.ayMid, ...
expected.AyMin, expected.AyMax, ...
"Acceleration Y", "m/s^2", runToUse, ...
showMinMaxBands, showTrendLines, struct(), prediction, predictionMinExtraFrac, predictionMaxExtraFrac, false);

plotVariableWithBand(D.timeSec, D.azMin, D.azMax, D.azMid, ... expected.AzMin, expected.AzMax, ...
"Acceleration Z", "m/s^2", runToUse, ...

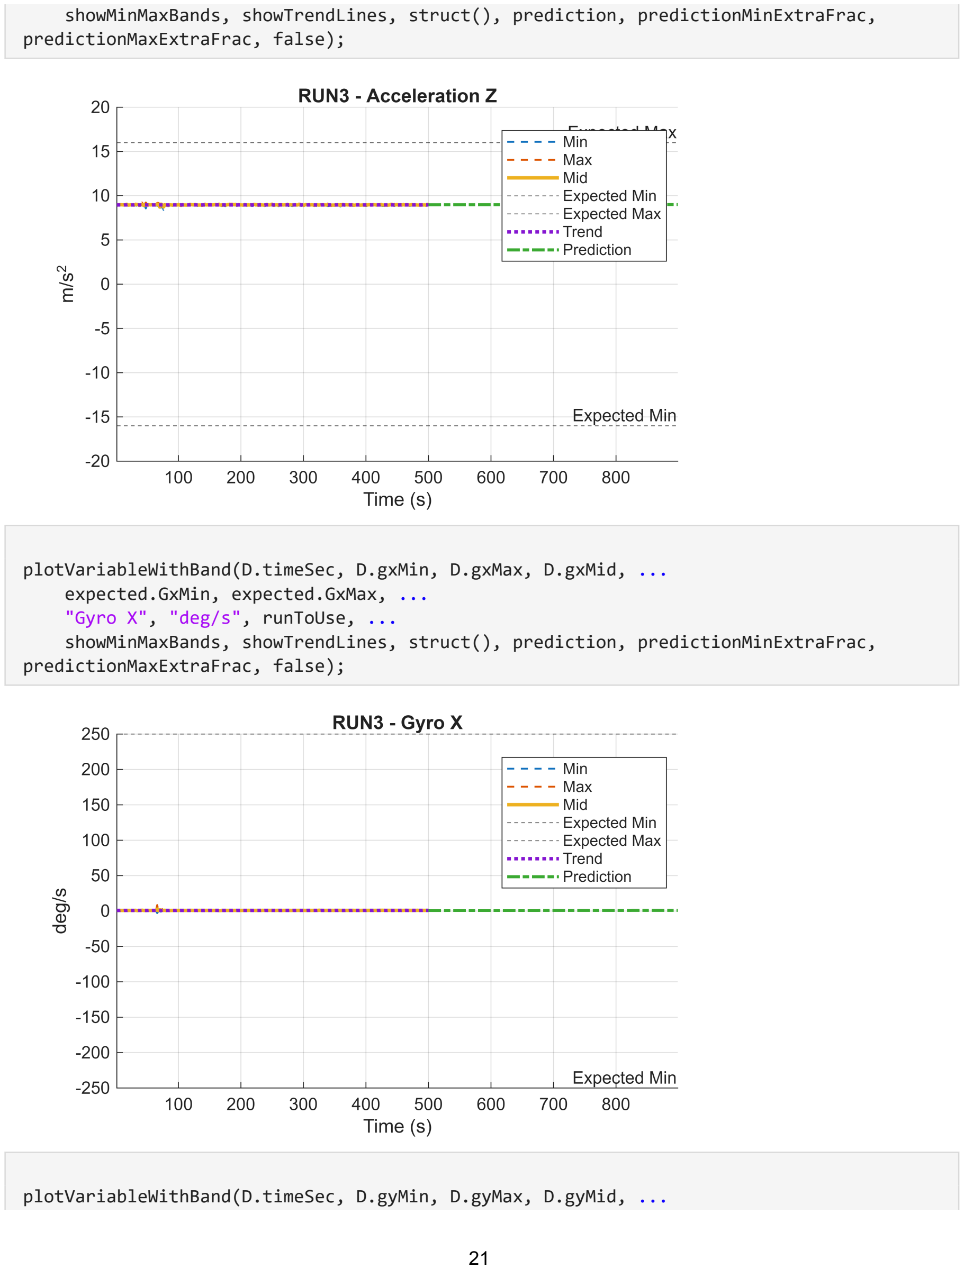
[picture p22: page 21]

showMinMaxBands, showTrendLines, struct(), prediction, predictionMinExtraFrac, predictionMaxExtraFrac, false);

plotVariableWithBand(D.timeSec, D.gxMin, D.gxMax, D.gxMid, ...
expected.GxMin, expected.GxMax, ...
"Gyro X", "deg/s", runToUse, ...
showMinMaxBands, showTrendLines, struct(), prediction, predictionMinExtraFrac, predictionMaxExtraFrac, false);

plotVariableWithBand(D.timeSec, D.gyMin, D.gyMax, D.gyMid, ...

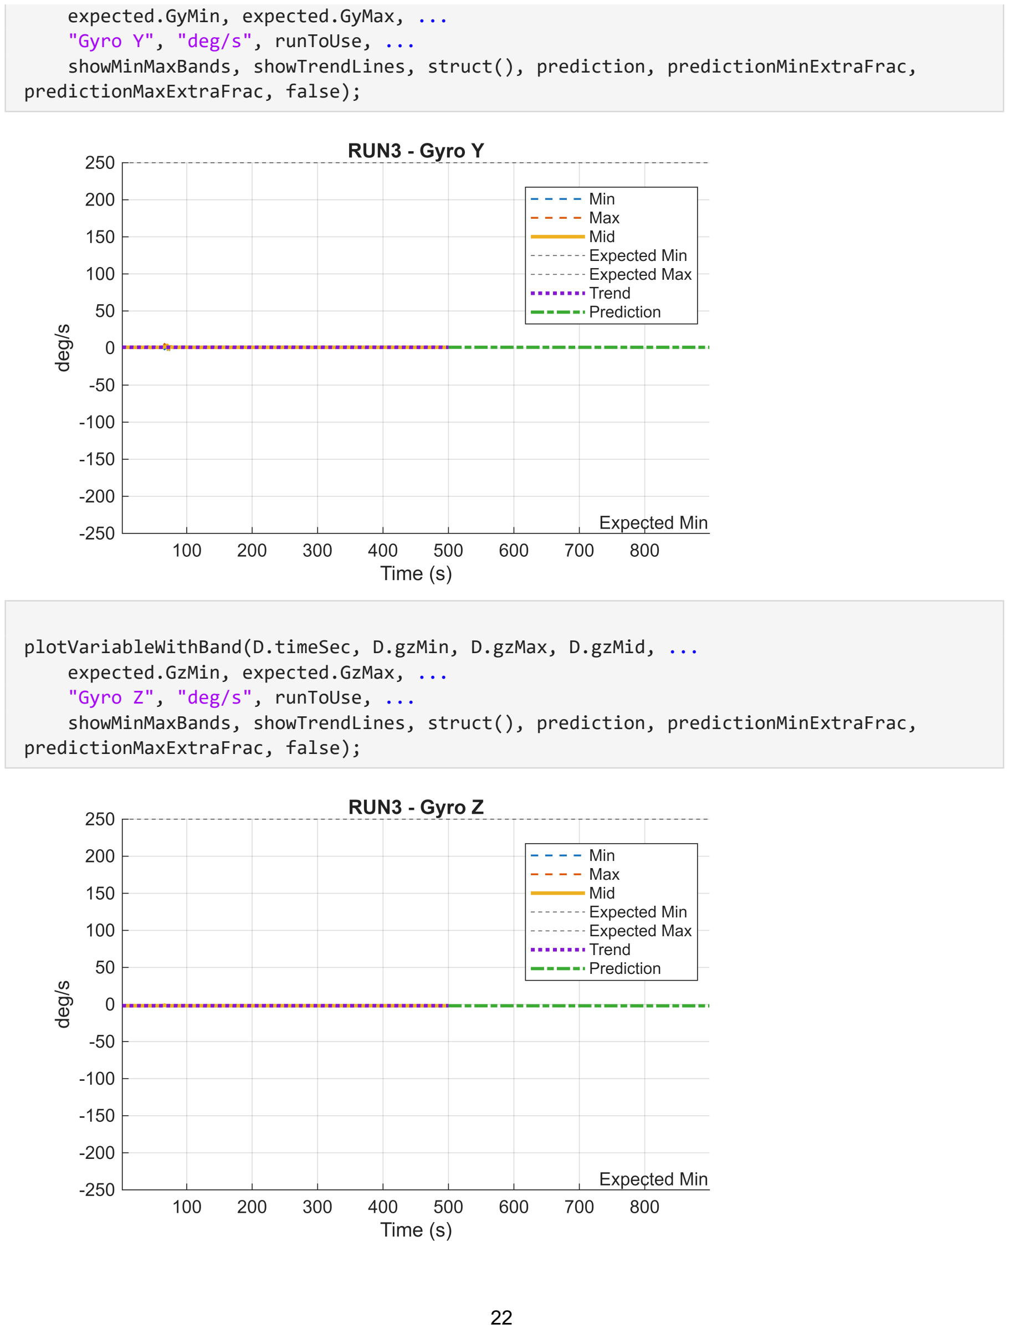
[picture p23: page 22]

expected.GyMin, expected.GyMax, ...
"Gyro Y", "deg/s", runToUse, ...
showMinMaxBands, showTrendLines, struct(), prediction, predictionMinExtraFrac, predictionMaxExtraFrac, false);

plotVariableWithBand(D.timeSec, D.gzMin, D.gzMax, D.gzMid, ...
expected.GzMin, expected.GzMax, ...
"Gyro Z", "deg/s", runToUse, ...
showMinMaxBands, showTrendLines, struct(), prediction, predictionMinExtraFrac, predictionMaxExtraFrac, false);

figure
bar([airClose, groundClose, humClose, presClose, longTermScore])
set(gca, 'XTickLabel', {'Air T','Ground T','Humidity','Pressure','Long-Term'}) ylabel('Score (%)')
title("RUN" + runToUse + " Core Closeness / Long-Term Score")
grid on

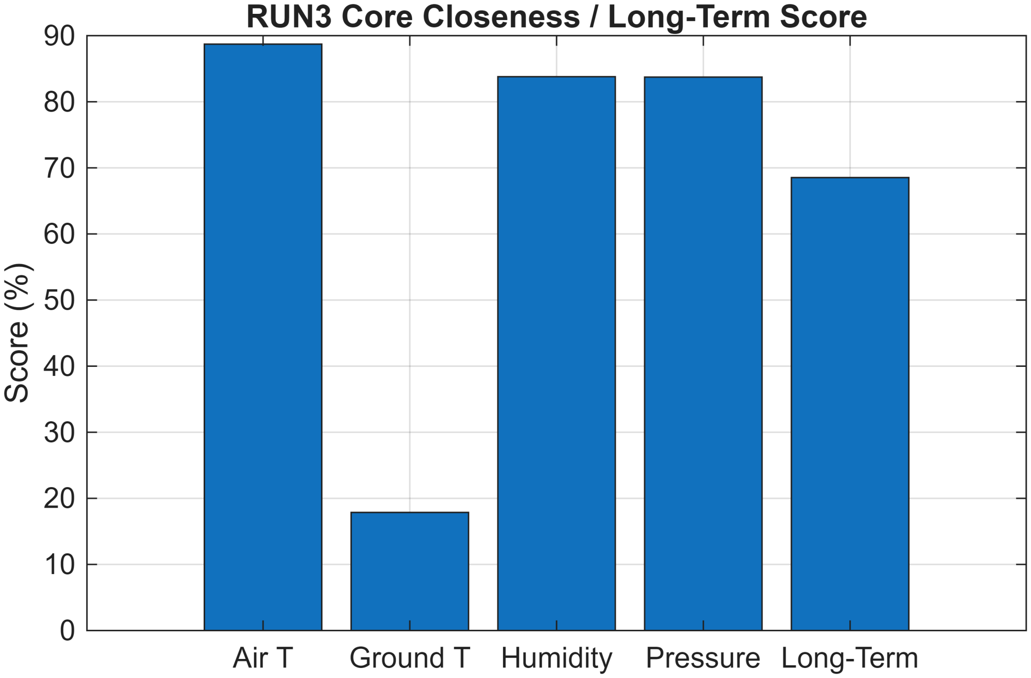
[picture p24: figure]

figure
bar([battClose, solarClose, lightClose, supportAverageCloseness]) set(gca, 'XTickLabel', {'Battery','Solar','Light','Support Avg'}) ylabel('Score (%)')
title("RUN" + runToUse + " Support Variable Closeness")
grid on

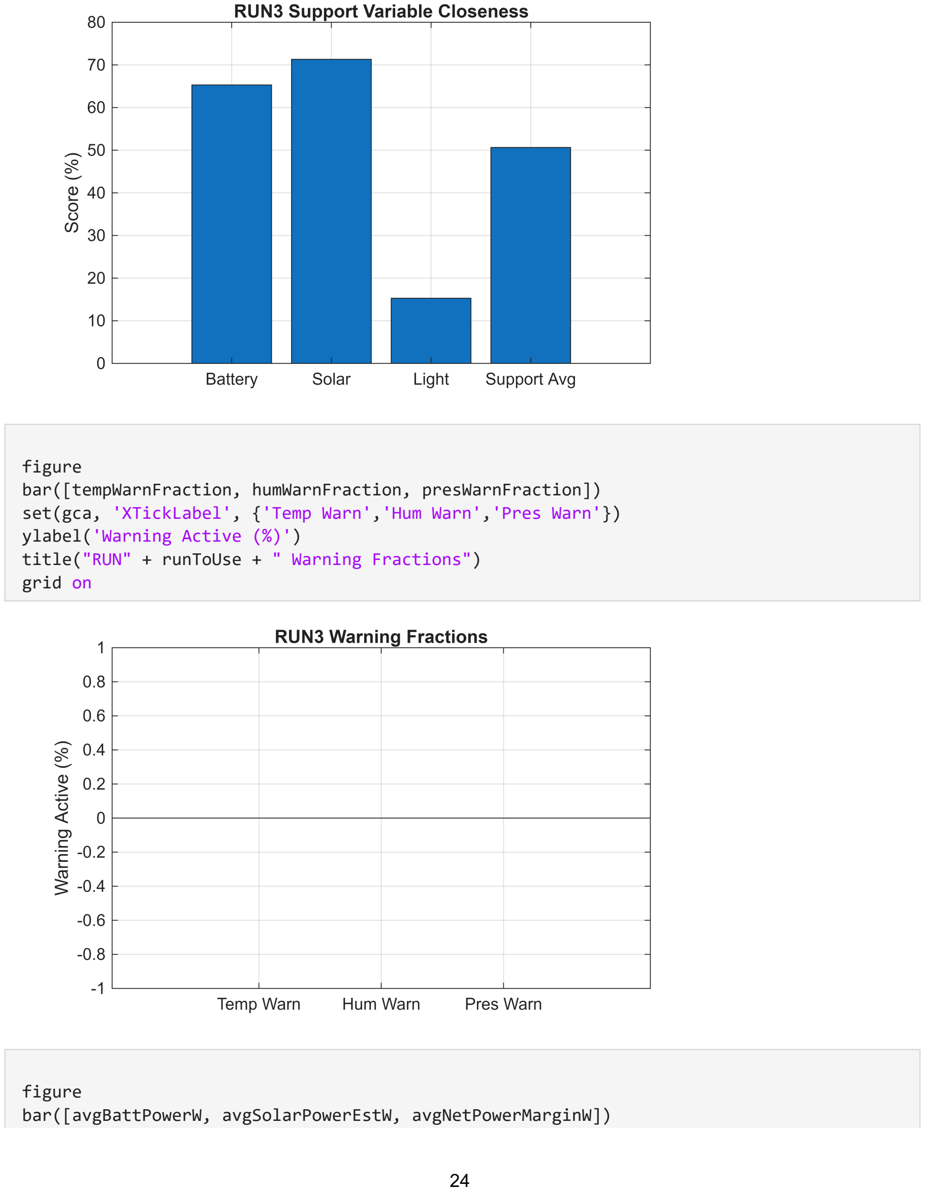
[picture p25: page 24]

figure
bar([tempWarnFraction, humWarnFraction, presWarnFraction]) set(gca, 'XTickLabel', {'Temp Warn','Hum Warn','Pres Warn'}) ylabel('Warning Active (%)')
title("RUN" + runToUse + " Warning Fractions")
grid on

figure
bar([avgBattPowerW, avgSolarPowerEstW, avgNetPowerMarginW])

set(gca, 'XTickLabel', {'Batt Power','Solar Power Est','Net Margin'}) ylabel('Power (W)')
title("RUN" + runToUse + " Power Comparison")
grid on

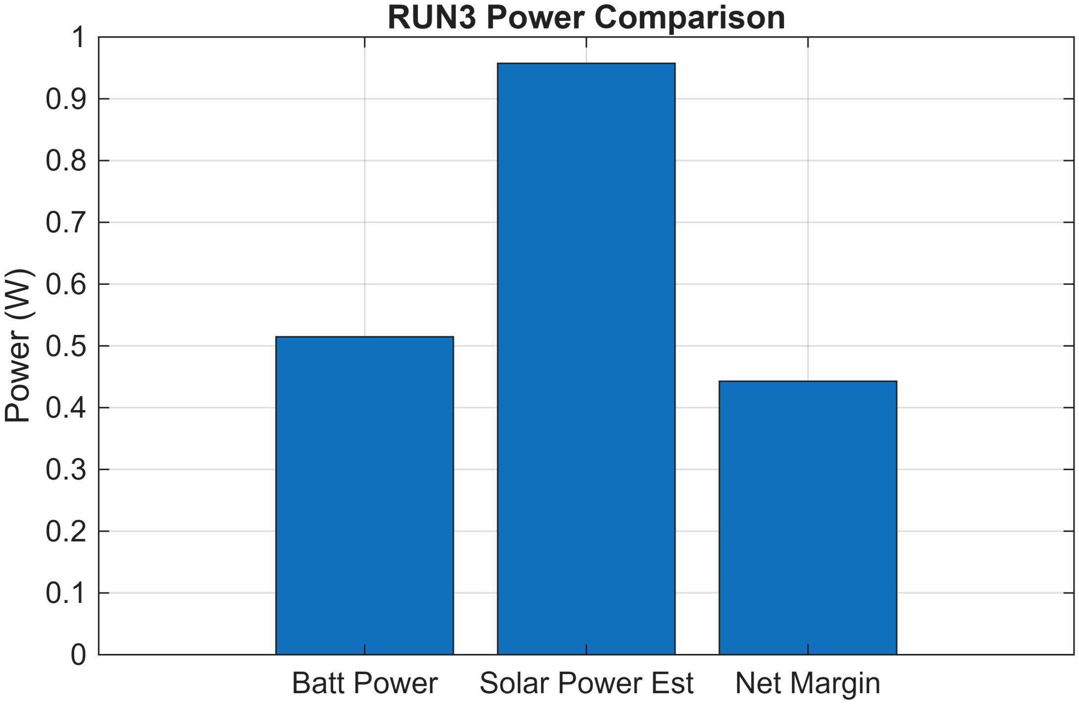
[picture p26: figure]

%% conclusions
fprintf('\n============= SUITABILITY ANALYSIS =============\n');

============= SUITABILITY ANALYSIS =============
fprintf('Run: RUN%d | Duration: %.2f s | Format: %s\n', runToUse, runDurationSec,
logFormat);
Run: RUN3 | Duration: 500.01 s | Format: new_min_max

fprintf('\nAverages:\n');

Averages:
fprintf('- Air: %.2f C | Ground: %.2f C | Humidity: %.2f %% | Pressure: %.2f
hPa\n', ...
avgAirTemp, avgGroundTemp, avgHum, avgPres);
- Air: 22.78 C | Ground: 20.45 C | Humidity: 46.28 % | Pressure: 1008.13 hPa
fprintf('- Battery: %.2f V | Solar: %.2f V | Light: %.2f\n', ...
avgBatt, avgSolar, avgLight);
- Battery: 5.72 V | Solar: 4.79 V | Light: 3781.91

fprintf('\nCore check:\n');

Core check:
fprintf('- Air %.1f%% | Ground %.1f%% | Humidity %.1f%% | Pressure %.1f%%\n', ...
airClose, groundClose, humClose, presClose);
- Air 88.7% | Ground 17.9% | Humidity 83.8% | Pressure 83.7%

fprintf('\nPower check:\n');

Power check:
fprintf('- Battery avg power: %.3f W\n', avgBattPowerW);
- Battery avg power: 0.515 W
fprintf('- Solar avg power est: %.3f W\n', avgSolarPowerEstW);
- Solar avg power est: 0.957 W
fprintf('- Net margin: %.3f W\n', avgNetPowerMarginW);
- Net margin: 0.443 W
fprintf('- Battery power vs drop: %s\n', battPowerDropAlignment);
- Battery power vs drop: ALIGNS
fprintf('- Solar power vs trend: %s\n', solarPowerTrendAlignment);
- Solar power vs trend: HIGH BUT DROPPING

if isfinite(chargeTimeHoursAdj)
fprintf('- Est. battery charge time from solar: %.2f hr ideal, %.2f hr adjusted\n', ...
chargeTimeHoursIdeal, chargeTimeHoursAdj);
else
fprintf('- Est. battery charge time from solar: not supported by current average solar margin\n');
end
- Est. battery charge time from solar: 6.58 hr ideal, 8.23 hr adjusted

fprintf('\nTrend notes:\n');

Trend notes:
printTrend("Air", trend.airTemp);
- Air: drift = -0.810, directional consistency = 0.62, behavior = STABLE | no boundary estimate needed
printTrend("Ground", trend.groundTemp);
- Ground: drift = -0.324, directional consistency = 0.20, behavior = STABLE | no boundary estimate needed

printTrend("Humidity", trend.humidity);

- Humidity: drift = 1.892, directional consistency = 0.53, behavior = STABLE | no boundary estimate needed
printTrend("Pressure", trend.pressure);
- Pressure: drift = 0.111, directional consistency = 0.44, behavior = STABLE | no boundary estimate needed
printTrend("Battery", trend.battery);
- Battery: drift = -0.169, directional consistency = 0.36, behavior = STABLE | no boundary estimate needed
printTrend("Solar", trend.solar);
- Solar: drift = -0.154, directional consistency = 0.41, behavior = STABLE | no boundary estimate needed

fprintf('\nOther notes:\n');

Other notes:
fprintf('- Avg air-ground temp diff: %.3f C\n', avgAirGroundDelta);
- Avg air-ground temp diff: 2.335 C
if ~isnan(airGroundCorr)
fprintf('- Air-ground temp correlation: %.3f\n', airGroundCorr); end
- Air-ground temp correlation: 0.953

fprintf('\nResult:\n');

Result:
fprintf('- Long-term score: %.1f %%\n', longTermScore);
- Long-term score: 68.5 %
fprintf('- Decision: %s\n', longTermDecision);
- Decision: MARGINALLY SUITABLE LONG-TERM

if ~isempty(coreComments)
fprintf('- Notes:\n');
for i = 1:numel(coreComments)
fprintf(' * %s\n', coreComments(i)); end
end

fprintf('===============================================\n');

===============================================

%% local functions
function x = toNum(s)
s = strtrim(string(s));

if s == "NA" || s == ""
x = NaN;
else
x = str2double(s);
end
end

function out = classifyLight(v, darkTh, brightTh) if isnan(v)
out = "NA";
elseif v <= darkTh
out = "DARK";
elseif v < brightTh
out = "NORMAL";
else
out = "BRIGHT";
end
end

function [isPass, closeness, centerOffsetPercent] = compareToRange(v, vMin, vMax) if isnan(v) || isnan(vMin) || isnan(vMax) || (vMax <= vMin)
isPass = false;
closeness = NaN;
centerOffsetPercent = NaN;
return
end

center = (vMin + vMax) / 2;
halfRange = (vMax - vMin) / 2;

centerOffsetPercent = abs(v - center) / halfRange * 100; closeness = max(0, 100 - centerOffsetPercent);
isPass = (v >= vMin) && (v <= vMax);
end

function tr = analyzeLongTermTrend(tHr, y, yMin, yMax, maxAllowedDrift, minDirectionalFraction, windowFraction)
good = ~(isnan(tHr) | isnan(y));
tHr = tHr(good);
y = y(good);

tr.startEndDrift = NaN;
tr.directionalFraction = NaN; tr.slopePerHour = NaN;
tr.recentSlopePerHour = NaN; tr.timeToBoundaryHours = Inf;

tr.behavior = "INSUFFICIENT_DATA"; tr.trendingTowardLimit = false; tr.predictedEndValue24h = NaN; tr.startMean = NaN;
tr.endMean = NaN;
tr.settlingLike = false;

if numel(y) < 5
return
end

n = numel(y);
w = max(2, round(windowFraction * n));

yStart = mean(y(1:w), 'omitnan');
yEnd = mean(y(end-w+1:end), 'omitnan'); drift = yEnd - yStart;

tr.startMean = yStart;
tr.endMean = yEnd;
tr.startEndDrift = drift;

dy = diff(y);

if drift > 0
dirFrac = mean(dy > 0, 'omitnan'); elseif drift < 0
dirFrac = mean(dy < 0, 'omitnan'); else
dirFrac = 0.5;
end

tr.directionalFraction = dirFrac;

pAll = polyfit(tHr, y, 1);
tr.slopePerHour = pAll(1);

recentStartIdx = max(1, n - max(3, round(0.30 * n)) + 1); tRecent = tHr(recentStartIdx:end);
yRecent = y(recentStartIdx:end);

if numel(yRecent) >= 3
pRecent = polyfit(tRecent, yRecent, 1); tr.recentSlopePerHour = pRecent(1); end

yNow = y(end);

if ~isnan(tr.recentSlopePerHour)
tr.predictedEndValue24h = yNow + tr.recentSlopePerHour * 24;

end

slopeSettling = false;
if ~isnan(tr.slopePerHour) && ~isnan(tr.recentSlopePerHour) && abs(tr.slopePerHour) > eps
slopeSettling = abs(tr.recentSlopePerHour) <= 0.35 * abs(tr.slopePerHour); end

returningTowardStart = false;
if ~isnan(yStart)
returningTowardStart = abs(yNow - yStart) < abs(yEnd - yStart) + 1e-9; end

flattening = false;
recentHalf = floor(numel(yRecent)/2);
if recentHalf >= 2
p1 = polyfit(tRecent(1:recentHalf), yRecent(1:recentHalf), 1); p2 = polyfit(tRecent(recentHalf:end), yRecent(recentHalf:end), 1); flattening = abs(p2(1)) < abs(p1(1));
end

tr.settlingLike = slopeSettling || returningTowardStart || flattening;

if abs(drift) <= maxAllowedDrift
tr.behavior = "STABLE";

elseif dirFrac < minDirectionalFraction tr.behavior = "TEMPORARY_BUMP";

elseif tr.settlingLike
tr.behavior = "SETTLING";

else
slopeToUse = tr.recentSlopePerHour; if isnan(slopeToUse)
slopeToUse = tr.slopePerHour;
end

if slopeToUse > 0
tr.trendingTowardLimit = yNow < yMax; if tr.trendingTowardLimit
dt = (yMax - yNow) / slopeToUse; if dt > 0
tr.timeToBoundaryHours = dt; end
end
elseif slopeToUse < 0
tr.trendingTowardLimit = yNow > yMin; if tr.trendingTowardLimit
dt = (yMin - yNow) / slopeToUse;

if dt > 0
tr.timeToBoundaryHours = dt; end
end
end

if isfinite(tr.timeToBoundaryHours) && tr.timeToBoundaryHours <= 24 tr.behavior = "UNSAFE_RISING";
elseif isfinite(tr.timeToBoundaryHours) && tr.timeToBoundaryHours <= 168 tr.behavior = "WATCH";
else
tr.behavior = "SLOW_DRIFT";
end
end

if any(strcmp(string(tr.behavior), ["STABLE","TEMPORARY_BUMP","SETTLING"])) tr.timeToBoundaryHours = Inf;
tr.trendingTowardLimit = false;
end
end

function [penalty, comments] = applyRealDriftPenalty(penalty, comments, name, tr, ~, watchHours)
switch string(tr.behavior)
case "STABLE"

case "TEMPORARY_BUMP"
comments(end+1,1) = name + " changed briefly, but not enough to count as real drift.";

case "SETTLING"
comments(end+1,1) = name + " looks like it is settling, so no continuing boundary estimate is needed.";

case "SLOW_DRIFT"
if isfinite(tr.timeToBoundaryHours) && tr.timeToBoundaryHours > watchHours
comments(end+1,1) = name + " is drifting, but the boundary looks far away, so near-future risk is low."; else
penalty = penalty + 8;
comments(end+1,1) = name + " shows drift and should be watched."; end

case "WATCH"
penalty = penalty + 15;
comments(end+1,1) = name + " is trending enough to affect the near future.";

case "UNSAFE_RISING"

penalty = penalty + 30;
comments(end+1,1) = name + " is changing consistently enough to become unsafe soon.";

otherwise
penalty = penalty + 5;
comments(end+1,1) = name + " did not have enough clear data for a strong prediction.";
end
end

function txt = passText(tf) if tf
txt = "PASS";
else
txt = "FAIL";
end
end

function printTrend(name, tr) fprintf('- %s: ', name);

if isnan(tr.startEndDrift) fprintf('insufficient data\n');
return
end

fprintf('drift = %.3f, directional consistency = %.2f, behavior = %s', ... tr.startEndDrift, tr.directionalFraction, tr.behavior);

if isfinite(tr.timeToBoundaryHours)
fprintf(' | est. time to boundary = %.2f hr\n', tr.timeToBoundaryHours);
else
fprintf(' | no boundary estimate needed\n');
end
end

function v = displayBoundaryTime(tr) if isfinite(tr.timeToBoundaryHours) v = tr.timeToBoundaryHours; else
v = NaN;
end
end

function energyWh = integratePowerWh(tSec, pW)
good = ~(isnan(tSec) | isnan(pW));
tSec = tSec(good);
pW = pW(good);

if numel(tSec) < 2
energyWh = NaN;
return
end

energyWh = trapz(tSec / 3600, pW);
end

function yPred = predictValueAtHours(tSec, y, expectedMin, expectedMax, tr, cfg, isEnergyVariable, hoursAhead)
pred = buildPredictionPath(tSec, y, expectedMin, expectedMax, tr, cfg, isEnergyVariable);

if isempty(pred.t)
yPred = NaN;
return
end

tTarget = max(tSec) + hoursAhead * 3600;

if tTarget < pred.t(1) || tTarget > pred.t(end) yPred = NaN;
return
end

yPred = interp1(pred.t, pred.y, tTarget, 'linear', NaN);
end

function pred = buildPredictionPath(tSec, y, expectedMin, expectedMax, tr, cfg, isEnergyVariable)
pred.t = [];
pred.y = [];
pred.mode = "none";
good = ~(isnan(tSec) | isnan(y));
tSec = tSec(good);
y = y(good);

if numel(y) < max(6, cfg.minPointsRecent) return
end

n = numel(y);
nRecent = max(cfg.minPointsRecent, round(cfg.recentFrac * n)); nStart = max(3, round(cfg.startFrac * n));

iRecent = max(1, n - nRecent + 1);

tRecent = tSec(iRecent:end);
yRecent = y(iRecent:end);

startMean = mean(y(1:nStart), 'omitnan'); recentMean = mean(yRecent, 'omitnan'); lastVal = y(end);

tRecentHr = (tRecent - tRecent(1)) / 3600; tLast = tSec(end);

pRecent = polyfit(tRecent/3600, yRecent, 1); recentSlope = pRecent(1);

pAll = polyfit(tSec/3600, y, 1);
fullSlope = pAll(1);

rangeWidth = expectedMax - expectedMin; if rangeWidth <= 0
rangeWidth = max(abs(lastVal), 1);
end

if isEnergyVariable
settleSlopeFracToUse = cfg.energySettleSlopeFrac; minSlopeForLinearToUse = cfg.energyMinSlopeForLinear;
else
settleSlopeFracToUse = cfg.settleSlopeFrac; minSlopeForLinearToUse = max(0.004, cfg.minSlopeForLinear * 0.25); end

slopeSettling = false;
if ~isnan(fullSlope) && ~isnan(recentSlope) && abs(fullSlope) > eps slopeSettling = abs(recentSlope) <= settleSlopeFracToUse * abs(fullSlope); end

returningTowardStart = false;
if ~isnan(startMean)
distNow = abs(lastVal - startMean);
distRecentMean = abs(recentMean - startMean); returningTowardStart = distNow <= distRecentMean + cfg.returnFrac * rangeWidth;
end

recentHalf = floor(numel(yRecent)/2);
flattening = false;
if recentHalf >= 2
p1 = polyfit(tRecent(1:recentHalf)/3600, yRecent(1:recentHalf), 1); p2 = polyfit(tRecent(recentHalf:end)/3600, yRecent(recentHalf:end), 1); flattening = abs(p2(1)) < abs(p1(1));
end

strongRecentDrift = abs(recentSlope) >= minSlopeForLinearToUse; sameDirection = sign(recentSlope) == sign(fullSlope) || abs(fullSlope) < eps;

if isEnergyVariable
shouldSettle = false;
else
shouldSettle = ~strongRecentDrift && ...
(slopeSettling || returningTowardStart || flattening || ... strcmp(string(tr.behavior),"TEMPORARY_BUMP") || ... strcmp(string(tr.behavior),"STABLE") || ... strcmp(string(tr.behavior),"SETTLING"));
end

if strongRecentDrift && sameDirection shouldSettle = false;
end

if shouldSettle
target = recentMean;
if abs(startMean - lastVal) < abs(recentMean - lastVal) target = startMean;
end

target = min(max(target, expectedMin), expectedMax);

tFutureEnd = tLast + min(cfg.maxSettleHours, cfg.graphMaxHours) * 3600; tFuture = linspace(tLast, tFutureEnd, cfg.curvePoints);

tau = max((min(cfg.maxSettleHours, cfg.graphMaxHours) * 3600)/4, 60); yFuture = target + (lastVal - target) * exp(-(tFuture - tLast)/tau);

pred.mode = "settling";
pred.t = tFuture;
pred.y = yFuture;
return
end

curveUsed = false;
if cfg.allowCurved && numel(yRecent) >= 5 pLinRecent = polyfit(tRecentHr, yRecent, 1); yLinRecent = polyval(pLinRecent, tRecentHr);

pQuadRecent = polyfit(tRecentHr, yRecent, 2);
yQuadRecent = polyval(pQuadRecent, tRecentHr);

rmseLin = sqrt(mean((yRecent - yLinRecent).^2, 'omitnan')); rmseQuad = sqrt(mean((yRecent - yQuadRecent).^2, 'omitnan'));

curveStrength = abs(2 * pQuadRecent(1));
slopeAtEnd = 2 * pQuadRecent(1) * tRecentHr(end) + pQuadRecent(2);

dataSpanHr = max(tRecentHr) - min(tRecentHr);

if dataSpanHr <= 0
dataSpanHr = 1;
end

maxAllowedAccel = cfg.maxCurveAccelFrac * max(abs(recentSlope), minSlopeForLinearToUse) / dataSpanHr; curveAccel = min(max(2 * pQuadRecent(1), -maxAllowedAccel), maxAllowedAccel);

sameDirectionAsRecent = true;
if abs(recentSlope) > eps && abs(slopeAtEnd) > eps
sameDirectionAsRecent = sign(slopeAtEnd) == sign(recentSlope);
end

curveOkay = (rmseQuad <= cfg.curveImproveFrac * rmseLin || rmseLin < eps) && ...
(abs(curveStrength) >= cfg.minCurveStrength || abs(recentSlope) >= minSlopeForLinearToUse) && ... sameDirectionAsRecent;

if curveOkay
maxFutureSec = min(cfg.maxLinearHours, cfg.graphMaxHours) * 3600; tFuture = linspace(tLast, tLast + maxFutureSec, cfg.curvePoints); dtHr = (tFuture - tLast) / 3600;
yFuture = lastVal + slopeAtEnd * dtHr + 0.5 * curveAccel * dtHr.^2;

idxStop = firstBoundaryHit(yFuture, expectedMin, expectedMax);
if ~isempty(idxStop)
tFuture = tFuture(1:idxStop);
yFuture = yFuture(1:idxStop);
yFuture(end) = min(max(yFuture(end), expectedMin), expectedMax); end

if numel(yFuture) >= 2
pred.mode = "curved";
pred.t = tFuture;
pred.y = yFuture;
curveUsed = true;
end
end
end

if curveUsed
return
end

maxFutureSec = min(cfg.maxLinearHours, cfg.graphMaxHours) * 3600; tBoundary = NaN;

if recentSlope > 0 && lastVal < expectedMax dtHr = (expectedMax - lastVal) / recentSlope; if dtHr > 0
tBoundary = tLast + dtHr * 3600;
end
elseif recentSlope < 0 && lastVal > expectedMin dtHr = (expectedMin - lastVal) / recentSlope; if dtHr > 0
tBoundary = tLast + dtHr * 3600;
end
end

if isnan(tBoundary)
tEnd = tLast + maxFutureSec;
else
tEnd = min(tBoundary, tLast + maxFutureSec); end

if tEnd <= tLast
return
end

tFuture = linspace(tLast, tEnd, cfg.curvePoints);
yFuture = lastVal + recentSlope * ((tFuture - tLast)/3600);

if ~isnan(tBoundary) && abs(tFuture(end) - tBoundary) < 1 if recentSlope > 0
yFuture(end) = expectedMax; elseif recentSlope < 0
yFuture(end) = expectedMin; end
end

pred.mode = "linear";
pred.t = tFuture;
pred.y = yFuture;
end

function idx = firstBoundaryHit(y, yMin, yMax)
idx = find(y <= yMin | y >= yMax, 1, 'first');
end

function plotVariableWithBand(t, yMin, yMax, yMid, expectedMin, expectedMax, plotTitleText, yLabelText, runNum, showBands, showTrend, tr, predictionCfg, predictionMinExtraFrac, predictionMaxExtraFrac, isEnergyVariable)
figure
hold on
good = ~(isnan(t) | isnan(yMid));

if nnz(good) < 2

if showBands
plot(t, yMin, '--', 'LineWidth', 1) plot(t, yMax, '--', 'LineWidth', 1) end

plot(t, yMid, 'LineWidth', 2) yline(expectedMin, '--', 'Expected Min') yline(expectedMax, '--', 'Expected Max') grid on
xlabel('Time (s)')
ylabel(yLabelText)
title("RUN" + runNum + " - " + plotTitleText) legend('Location','best')
return
end

tData = t(good);
yData = yMid(good);

if showBands
plot(t, yMin, '--', 'LineWidth', 1) plot(t, yMax, '--', 'LineWidth', 1) end

plot(t, yMid, 'LineWidth', 2) yline(expectedMin, '--', 'Expected Min') yline(expectedMax, '--', 'Expected Max')

if showTrend
p = polyfit(tData, yData, 1);
yFit = polyval(p, tData);
plot(tData, yFit, ':', 'LineWidth', 2)
end

pred = buildPredictionPath(tData, yData, expectedMin, expectedMax, tr, predictionCfg, isEnergyVariable);

predictionPlotted = false;
xEndPlot = max(tData);

if ~isempty(pred.t)
plot(pred.t, pred.y, '-.', 'LineWidth', 1.8)
predictionPlotted = true;
xEndPlot = min(max(pred.t), max(tData) + predictionCfg.graphMaxHours * 3600);
end

runDuration = max(tData) - min(tData);
minExtra = predictionMinExtraFrac * max(runDuration, 1);

maxExtra = min(predictionMaxExtraFrac * max(runDuration, 1), predictionCfg.graphMaxHours * 3600);

desiredExtra = xEndPlot - max(tData);
desiredExtra = max(desiredExtra, minExtra);
desiredExtra = min(desiredExtra, maxExtra);

xlim([min(tData), max(tData) + desiredExtra])

grid on
xlabel('Time (s)')
ylabel(yLabelText)
title("RUN" + runNum + " - " + plotTitleText)

if predictionPlotted && showBands && showTrend legend('Min','Max','Mid','Expected Min','Expected Max','Trend','Prediction','Location','best') elseif predictionPlotted && showBands legend('Min','Max','Mid','Expected Min','Expected Max','Prediction','Location','best') elseif predictionPlotted && showTrend legend('Mid','Expected Min','Expected Max','Trend','Prediction','Location','best') elseif predictionPlotted
legend('Mid','Expected Min','Expected Max','Prediction','Location','best') elseif showBands && showTrend
legend('Min','Max','Mid','Expected Min','Expected Max','Trend','Location','best') elseif showBands
legend('Min','Max','Mid','Expected Min','Expected Max','Location','best') elseif showTrend
legend('Mid','Expected Min','Expected Max','Trend','Location','best') else
legend('Mid','Expected Min','Expected Max','Location','best')
end
end

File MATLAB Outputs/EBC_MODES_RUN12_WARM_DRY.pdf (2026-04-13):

## KEVIN JAUKI

%% Environmental Brain Cube - Modes Analysis
% This script checks how close one mode run was to a chosen condition. %
% It does these things:
% - reads the modes log file
% - picks one run
% - compares run averages to all conditions % - makes plots
% - shows simple tables and conclusions
% - makes final match of environment profile %

clear; clc; close all;

%% settings
fileName = "ebc_modes_log.csv";
runChoice = "12"; | % "latest" or a run number like "2" (make sure run
number is accurate and quoted"")

%% condition table
% should match Arduino code
profiles = table( ...
["NORMAL"; "WARM_HUMID"; "WARM_DRY"; "COLD"], ... [20.0; 26.0; 24.0; 4.0], ...
[24.0; 32.0; 30.0; 12.0], ...
[30.0; 60.0; 15.0; 35.0], ...
[50.0; 70.0; 35.0; 65.0], ... [995.0; 995.0; 995.0; 995.0], ...
[1025.0; 1025.0; 1025.0; 1025.0], ...
'VariableNames',
{'Name','TempMin','TempMax','HumMin','HumMax','PresMin','PresMax'});

%% check file
if ~isfile(fileName)
error("File not found: " + fileName);
end

%% read file lines
txt = fileread(fileName);
lines = splitlines(string(txt)); lines = strtrim(lines);
lines = lines(lines ~= "");

%% keep only real RUN rows dataLines = strings(0,1);

for i = 1:length(lines)
lineNow = lines(i);

if startsWith(lineNow, "RUN") && ~startsWith(lineNow, "=== RUN") parts = split(lineNow, ",");
if numel(parts) >= 30
dataLines(end+1,1) = lineNow; %#ok<SAGROW> end
end
end

if isempty(dataLines)
error("No valid RUN data rows found."); end

%% make arrays
n = length(dataLines);

runNum = nan(n,1);
timeSec = nan(n,1);

lightMin = nan(n,1);
lightMax = nan(n,1);
lightState = strings(n,1);

bmeTempMin = nan(n,1);
bmeTempMax = nan(n,1);

bmeHumMin = nan(n,1);
bmeHumMax = nan(n,1);

bmePresMin = nan(n,1);
bmePresMax = nan(n,1);

dsTempMin = nan(n,1);
dsTempMax = nan(n,1);

battMin = nan(n,1);
battMax = nan(n,1);

solarMin = nan(n,1);
solarMax = nan(n,1);

axMin = nan(n,1);
axMax = nan(n,1);

ayMin = nan(n,1);
ayMax = nan(n,1);

azMin = nan(n,1);
azMax = nan(n,1);

gxMin = nan(n,1);
gxMax = nan(n,1);

gyMin = nan(n,1);
gyMax = nan(n,1);

gzMin = nan(n,1);
gzMax = nan(n,1);

%% pull values from each row
for i = 1:n
row = split(dataLines(i), ",");
row = strtrim(row);

runNum(i) = sscanf(row(1), "RUN%d"); timeSec(i) = makeNum(row(3));

lightMin(i) = makeNum(row(4)); lightMax(i) = makeNum(row(5)); lightState(i) = row(6);

bmeTempMin(i) = makeNum(row(7)); bmeTempMax(i) = makeNum(row(8));

bmeHumMin(i) = makeNum(row(9)); bmeHumMax(i) = makeNum(row(10));

bmePresMin(i) = makeNum(row(11)); bmePresMax(i) = makeNum(row(12));

dsTempMin(i) = makeNum(row(13)); dsTempMax(i) = makeNum(row(14));

battMin(i) = makeNum(row(15)); battMax(i) = makeNum(row(16));

solarMin(i) = makeNum(row(17)); solarMax(i) = makeNum(row(18));

axMin(i) = makeNum(row(19)); axMax(i) = makeNum(row(20));

ayMin(i) = makeNum(row(21)); ayMax(i) = makeNum(row(22));

azMin(i) = makeNum(row(23)); azMax(i) = makeNum(row(24));

gxMin(i) = makeNum(row(25)); gxMax(i) = makeNum(row(26));

gyMin(i) = makeNum(row(27)); gyMax(i) = makeNum(row(28));

gzMin(i) = makeNum(row(29)); gzMax(i) = makeNum(row(30)); end

%% make table
T = table(runNum,timeSec,... lightMin,lightMax,lightState,... bmeTempMin,bmeTempMax,...
bmeHumMin,bmeHumMax,...
bmePresMin,bmePresMax,...
dsTempMin,dsTempMax,...
battMin,battMax,...
solarMin,solarMax,...
axMin,axMax,...
ayMin,ayMax,...
azMin,azMax,...
gxMin,gxMax,...
gyMin,gyMax,...
gzMin,gzMax);

%% choose run
allRuns = unique(T.runNum);

if runChoice == "latest"
runToUse = max(allRuns);
else
runToUse = double(runChoice); end

D = T(T.runNum == runToUse, :);
D = sortrows(D, "timeSec");

if isempty(D)
error("Selected run not found."); end

fprintf("Using RUN%d\n", runToUse);

Using RUN12
fprintf("Intervals logged: %d\n", height(D));

Intervals logged: 148 fprintf("Run duration: %.2f s\n", max(D.timeSec));

Run duration: 300.01 s

%% midpoint values
D.bmeTempMid = (D.bmeTempMin + D.bmeTempMax) / 2; D.dsTempMid = (D.dsTempMin + D.dsTempMax) / 2; D.bmeHumMid = (D.bmeHumMin + D.bmeHumMax) / 2; D.bmePresMid = (D.bmePresMin + D.bmePresMax) / 2;

%% average values for fit
avgBmeTemp = mean(D.bmeTempMid, 'omitnan'); avgDsTemp = mean(D.dsTempMid, 'omitnan');
avgHum | = mean(D.bmeHumMid, 'omitnan');
avgPres | = mean(D.bmePresMid, 'omitnan');

% use BME air temp for matching condition avgTempForFit = avgBmeTemp;

%% compare to all conditions and rank them envName = strings(height(profiles),1);

tempPassAll = false(height(profiles),1); humPassAll = false(height(profiles),1); presPassAll = false(height(profiles),1);

tempCloseAll = nan(height(profiles),1); humCloseAll = nan(height(profiles),1); presCloseAll = nan(height(profiles),1);

tempOffsetAll = nan(height(profiles),1); humOffsetAll = nan(height(profiles),1); presOffsetAll = nan(height(profiles),1);

matchCountAll = nan(height(profiles),1); overallClosenessAll = nan(height(profiles),1);

for k = 1:height(profiles)
envName(k) = profiles.Name(k);

[tempPassAll(k), tempCloseAll(k), tempOffsetAll(k)] = compareToRange(avgTempForFit, profiles.TempMin(k), profiles.TempMax(k)); [humPassAll(k), humCloseAll(k), humOffsetAll(k)] = compareToRange(avgHum, profiles.HumMin(k), profiles.HumMax(k));
[presPassAll(k), presCloseAll(k), presOffsetAll(k)] = compareToRange(avgPres, profiles.PresMin(k), profiles.PresMax(k));

matchCountAll(k) = sum([tempPassAll(k), humPassAll(k), presPassAll(k)]);

overallClosenessAll(k) = mean([tempCloseAll(k), humCloseAll(k), presCloseAll(k)], 'omitnan');
end

%% ranked environment table
EnvironmentRanking = table( ... envName, ...
matchCountAll, ...
overallClosenessAll, ...
tempPassAll, humPassAll, presPassAll, ... tempCloseAll, humCloseAll, presCloseAll, ... tempOffsetAll, humOffsetAll, presOffsetAll, ... 'VariableNames', ...
{'Environment','MatchCount','OverallClosenessPercent', ... 'TempPass','HumPass','PresPass', ... 'TempClosenessPercent','HumClosenessPercent','PresClosenessPercent', ... 'TempCenterOffsetPercent','HumCenterOffsetPercent','PresCenterOffsetPercent'});

EnvironmentRanking = sortrows(EnvironmentRanking, {'MatchCount','OverallClosenessPercent'}, {'descend','descend'});

EnvironmentRanking

EnvironmentRanking = 4×12 table

| Environment | MatchCount | OverallClosenessPercent | TempPass | HumPass
1 | "WARM_DRY" | 3 | 61.0482 | true | true
2 | "WARM_HUMID" | 2 | 47.9852 | true | false
3 | "NORMAL" | 2 | 38.8025 | false | true
4 | "COLD" | 1 | 28.9083 | false | false

%% choose best condition automatically
selectedCondition = EnvironmentRanking.Environment(1);
profileRow = profiles(profiles.Name == selectedCondition, :);

disp("Best matched condition:")

Best matched condition:
disp(profileRow)
Name | TempMin | TempMax | HumMin | HumMax | PresMin | PresMax
__________ | _______ | _______ | ______ | ______ | _______ | _______
"WARM_DRY" | 24 | 30 | 15 | 35 | 995 | 1025

%% compare to selected condition
[tempPass, tempClose, tempOffset] = compareToRange(avgTempForFit, profileRow.TempMin, profileRow.TempMax);

[humPass, humClose, humOffset] = compareToRange(avgHum, profileRow.HumMin, profileRow.HumMax);
[presPass, presClose, presOffset] = compareToRange(avgPres, profileRow.PresMin, profileRow.PresMax);

overallCloseness = mean([tempClose, humClose, presClose], 'omitnan'); matchCount = sum([tempPass, humPass, presPass]);

%% comparison table
Parameter = ["Temperature"; "Humidity"; "Pressure"];
RunAverage = [avgTempForFit; avgHum; avgPres];
TargetMin = [profileRow.TempMin; profileRow.HumMin; profileRow.PresMin]; TargetMax = [profileRow.TempMax; profileRow.HumMax; profileRow.PresMax]; Pass = [tempPass; humPass; presPass];
ClosenessPercent = [tempClose; humClose; presClose]; CenterOffsetPercent = [tempOffset; humOffset; presOffset];

ComparisonTable = table(Parameter, RunAverage, TargetMin, TargetMax, ... Pass, ClosenessPercent, CenterOffsetPercent);

ComparisonTable

ComparisonTable = 3×7 table; Parameter; RunAverage; TargetMin; TargetMax; Pass; ClosenessPercent; "Temperature"; true; "Humidity"; "Pressure"; %% overall summary table OverallSummary = table( ... string(selectedCondition), ... runToUse, ... max(D.timeSec), ... avgBmeTemp, ... avgDsTemp, ... avgHum, ... avgPres, ... matchCount, ... overallCloseness, ... 'VariableNames', ...; {'Condition','Run','DurationSec','AvgBmeTemp','AvgDsTemp','AvgHumidity','AvgPressure ','MatchCount','OverallClosenessPercent'});; OverallSummary; OverallSummary = 1×9 table

| Condition | Run | DurationSec | AvgBmeTemp | AvgDsTemp | AvgHumidity
1 | "WARM_DRY" | 12 | 300.0100 | 27.7169 | 20.0572 | 32.9683

%% temperature plot
figure
plot(D.timeSec, D.bmeTempMin, '--', 'LineWidth', 1) hold on
plot(D.timeSec, D.bmeTempMax, '--', 'LineWidth', 1) plot(D.timeSec, D.bmeTempMid, 'LineWidth', 2) yline(profileRow.TempMin, '--', 'Target Min') yline(profileRow.TempMax, '--', 'Target Max')
grid on
xlabel('Time (s)')
ylabel('Temperature (C)')
title("RUN" + runToUse + " Temperature vs " + selectedCondition)
legend('BME Min','BME Max','BME Mid','Target Min','Target Max','Location','best')


%% humidity plot
figure
plot(D.timeSec, D.bmeHumMin, '--', 'LineWidth', 1) hold on
plot(D.timeSec, D.bmeHumMax, '--', 'LineWidth', 1) plot(D.timeSec, D.bmeHumMid, 'LineWidth', 2) yline(profileRow.HumMin, '--', 'Target Min') yline(profileRow.HumMax, '--', 'Target Max')
grid on
xlabel('Time (s)')

ylabel('Humidity (%)')
title("RUN" + runToUse + " Humidity vs " + selectedCondition)
legend('Hum Min','Hum Max','Hum Mid','Target Min','Target Max','Location','best')


%% pressure plot
figure
plot(D.timeSec, D.bmePresMin, '--', 'LineWidth', 1) hold on
plot(D.timeSec, D.bmePresMax, '--', 'LineWidth', 1) plot(D.timeSec, D.bmePresMid, 'LineWidth', 2) yline(profileRow.PresMin, '--', 'Target Min') yline(profileRow.PresMax, '--', 'Target Max')
grid on
xlabel('Time (s)')
ylabel('Pressure (hPa)')
title("RUN" + runToUse + " Pressure vs " + selectedCondition)
legend('Pres Min','Pres Max','Pres Mid','Target Min','Target Max','Location','best')


%% closeness bar chart
figure
bar([tempClose, humClose, presClose, overallCloseness]) set(gca, 'XTickLabel', {'Temp','Humidity','Pressure','Overall'}) ylabel('Closeness (%)')
title("RUN" + runToUse + " Closeness to " + selectedCondition) grid on

%% simple conclusions fprintf('\n================ CONDITION COMPARISON ================\n');

================ CONDITION COMPARISON ================
fprintf('Run analyzed: RUN%d\n', runToUse);

Run analyzed: RUN12
fprintf('Best matched condition: %s\n', selectedCondition);

Best matched condition: WARM_DRY
fprintf('Run duration: %.2f s\n', max(D.timeSec));

Run duration: 300.01 s

fprintf('\nAverage run values used for comparison:\n');

Average run values used for comparison:
fprintf('- BME temperature average: %.2f C\n', avgBmeTemp);
- BME temperature average: 27.72 C
fprintf('- DS temperature average: %.2f C\n', avgDsTemp);
- DS temperature average: 20.06 C
fprintf('- Humidity average: %.2f %%\n', avgHum);
- Humidity average: 32.97 %
fprintf('- Pressure average: %.2f hPa\n', avgPres);
- Pressure average: 1008.01 hPa

fprintf('\nBest matched condition ranges:\n');

Best matched condition ranges:
fprintf('- Temperature: %.1f to %.1f C\n', profileRow.TempMin, profileRow.TempMax);
- Temperature: 24.0 to 30.0 C
fprintf('- Humidity: %.1f to %.1f %%\n', profileRow.HumMin, profileRow.HumMax);
- Humidity: 15.0 to 35.0 %
fprintf('- Pressure: %.1f to %.1f hPa\n', profileRow.PresMin, profileRow.PresMax);
- Pressure: 995.0 to 1025.0 hPa

fprintf('\nParameter results:\n');

Parameter results:

fprintf('- Temperature: %s | closeness %.1f %%\n', passText(tempPass), tempClose);
- Temperature: PASS | closeness 76.1 %
fprintf('- Humidity: %s | closeness %.1f %%\n', passText(humPass), humClose);
- Humidity: PASS | closeness 20.3 %
fprintf('- Pressure: %s | closeness %.1f %%\n', passText(presPass), presClose);
- Pressure: PASS | closeness 86.7 %

fprintf('\nOverall:\n');

Overall:
fprintf('- Match count: %d/3\n', matchCount);
- Match count: 3/3
fprintf('- Overall closeness: %.1f %%\n', overallCloseness);
- Overall closeness: 61.0 %

if matchCount == 3
fprintf('- The run fits the matched condition well overall.\n');
elseif matchCount == 2
fprintf('- The run is fairly close, but one value is outside range.\n'); elseif matchCount == 1
fprintf('- The run only weakly matches the matched condition.\n');
else
fprintf('- The run does not closely match the matched condition.\n'); end
- The run fits the matched condition well overall.

fprintf('\nEnvironment ranking from best to worst:\n');

Environment ranking from best to worst:
for i = 1:height(EnvironmentRanking)
fprintf('%d. %s | match %d/3 | closeness %.1f %%\n', ...
i, EnvironmentRanking.Environment(i), ... EnvironmentRanking.MatchCount(i), ... EnvironmentRanking.OverallClosenessPercent(i)); end
1. WARM_DRY | match 3/3 | closeness 61.0 %
2. WARM_HUMID | match 2/3 | closeness 48.0 %
3. NORMAL | match 2/3 | closeness 38.8 %
4. COLD | match 1/3 | closeness 28.9 %

fprintf('======================================================\n');

======================================================

function x = makeNum(s)
s = strtrim(string(s));

if s == "NA" || s == ""
x = NaN;
else
x = str2double(s);
end
end

function [isPass, closeness, centerOffsetPercent] = compareToRange(v, vMin, vMax) if isnan(v)
isPass = false;
closeness = NaN;
centerOffsetPercent = NaN; return
end

center = (vMin + vMax) / 2; halfRange = (vMax - vMin) / 2;

if halfRange <= 0
isPass = false;
closeness = NaN;
centerOffsetPercent = NaN;
return
end

centerOffsetPercent = abs(v - center) / halfRange * 100; closeness = max(0, 100 - centerOffsetPercent);
isPass = (v >= vMin) && (v <= vMax);
end

function txt = passText(tf)
if tf
txt = 'PASS';
else
txt = 'FAIL';
end
end

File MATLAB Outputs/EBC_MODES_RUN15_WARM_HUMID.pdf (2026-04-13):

## KEVIN JAUKI

%% Environmental Brain Cube - Modes Analysis
% This script checks how close one mode run was to a chosen condition. %
% It does these things:
% - reads the modes log file
% - picks one run
% - compares run averages to all conditions % - makes plots
% - shows simple tables and conclusions
% - makes final match of environment profile %

clear; clc; close all;

%% settings
fileName = "ebc_modes_log.csv";
runChoice = "15"; | % "latest" or a run number like "2" (make sure run
number is accurate and quoted"")

%% condition table
% should match Arduino code
profiles = table( ...
["NORMAL"; "WARM_HUMID"; "WARM_DRY"; "COLD"], ... [20.0; 26.0; 24.0; 4.0], ...
[24.0; 32.0; 30.0; 12.0], ...
[30.0; 60.0; 15.0; 35.0], ...
[50.0; 70.0; 35.0; 65.0], ... [995.0; 995.0; 995.0; 995.0], ...
[1025.0; 1025.0; 1025.0; 1025.0], ...
'VariableNames',
{'Name','TempMin','TempMax','HumMin','HumMax','PresMin','PresMax'});

%% check file
if ~isfile(fileName)
error("File not found: " + fileName);
end

%% read file lines
txt = fileread(fileName);
lines = splitlines(string(txt)); lines = strtrim(lines);
lines = lines(lines ~= "");

%% keep only real RUN rows dataLines = strings(0,1);

for i = 1:length(lines)
lineNow = lines(i);

if startsWith(lineNow, "RUN") && ~startsWith(lineNow, "=== RUN") parts = split(lineNow, ",");
if numel(parts) >= 30
dataLines(end+1,1) = lineNow; %#ok<SAGROW> end
end
end

if isempty(dataLines)
error("No valid RUN data rows found."); end

%% make arrays
n = length(dataLines);

runNum = nan(n,1);
timeSec = nan(n,1);

lightMin = nan(n,1);
lightMax = nan(n,1);
lightState = strings(n,1);

bmeTempMin = nan(n,1);
bmeTempMax = nan(n,1);

bmeHumMin = nan(n,1);
bmeHumMax = nan(n,1);

bmePresMin = nan(n,1);
bmePresMax = nan(n,1);

dsTempMin = nan(n,1);
dsTempMax = nan(n,1);

battMin = nan(n,1);
battMax = nan(n,1);

solarMin = nan(n,1);
solarMax = nan(n,1);

axMin = nan(n,1);
axMax = nan(n,1);

ayMin = nan(n,1);
ayMax = nan(n,1);

azMin = nan(n,1);
azMax = nan(n,1);

gxMin = nan(n,1);
gxMax = nan(n,1);

gyMin = nan(n,1);
gyMax = nan(n,1);

gzMin = nan(n,1);
gzMax = nan(n,1);

%% pull values from each row
for i = 1:n
row = split(dataLines(i), ",");
row = strtrim(row);

runNum(i) = sscanf(row(1), "RUN%d"); timeSec(i) = makeNum(row(3));

lightMin(i) = makeNum(row(4)); lightMax(i) = makeNum(row(5)); lightState(i) = row(6);

bmeTempMin(i) = makeNum(row(7)); bmeTempMax(i) = makeNum(row(8));

bmeHumMin(i) = makeNum(row(9)); bmeHumMax(i) = makeNum(row(10));

bmePresMin(i) = makeNum(row(11)); bmePresMax(i) = makeNum(row(12));

dsTempMin(i) = makeNum(row(13)); dsTempMax(i) = makeNum(row(14));

battMin(i) = makeNum(row(15)); battMax(i) = makeNum(row(16));

solarMin(i) = makeNum(row(17)); solarMax(i) = makeNum(row(18));

axMin(i) = makeNum(row(19)); axMax(i) = makeNum(row(20));

ayMin(i) = makeNum(row(21)); ayMax(i) = makeNum(row(22));

azMin(i) = makeNum(row(23)); azMax(i) = makeNum(row(24));

gxMin(i) = makeNum(row(25)); gxMax(i) = makeNum(row(26));

gyMin(i) = makeNum(row(27)); gyMax(i) = makeNum(row(28));

gzMin(i) = makeNum(row(29)); gzMax(i) = makeNum(row(30)); end

%% make table
T = table(runNum,timeSec,... lightMin,lightMax,lightState,... bmeTempMin,bmeTempMax,...
bmeHumMin,bmeHumMax,...
bmePresMin,bmePresMax,...
dsTempMin,dsTempMax,...
battMin,battMax,...
solarMin,solarMax,...
axMin,axMax,...
ayMin,ayMax,...
azMin,azMax,...
gxMin,gxMax,...
gyMin,gyMax,...
gzMin,gzMax);

%% choose run
allRuns = unique(T.runNum);

if runChoice == "latest"
runToUse = max(allRuns);
else
runToUse = double(runChoice); end

D = T(T.runNum == runToUse, :);
D = sortrows(D, "timeSec");

if isempty(D)
error("Selected run not found."); end

fprintf("Using RUN%d\n", runToUse);

Using RUN15
fprintf("Intervals logged: %d\n", height(D));

Intervals logged: 149 fprintf("Run duration: %.2f s\n", max(D.timeSec));

Run duration: 300.03 s

%% midpoint values
D.bmeTempMid = (D.bmeTempMin + D.bmeTempMax) / 2; D.dsTempMid = (D.dsTempMin + D.dsTempMax) / 2; D.bmeHumMid = (D.bmeHumMin + D.bmeHumMax) / 2; D.bmePresMid = (D.bmePresMin + D.bmePresMax) / 2;

%% average values for fit
avgBmeTemp = mean(D.bmeTempMid, 'omitnan'); avgDsTemp = mean(D.dsTempMid, 'omitnan');
avgHum | = mean(D.bmeHumMid, 'omitnan');
avgPres | = mean(D.bmePresMid, 'omitnan');

% use BME air temp for matching condition avgTempForFit = avgBmeTemp;

%% compare to all conditions and rank them envName = strings(height(profiles),1);

tempPassAll = false(height(profiles),1); humPassAll = false(height(profiles),1); presPassAll = false(height(profiles),1);

tempCloseAll = nan(height(profiles),1); humCloseAll = nan(height(profiles),1); presCloseAll = nan(height(profiles),1);

tempOffsetAll = nan(height(profiles),1); humOffsetAll = nan(height(profiles),1); presOffsetAll = nan(height(profiles),1);

matchCountAll = nan(height(profiles),1); overallClosenessAll = nan(height(profiles),1);

for k = 1:height(profiles)
envName(k) = profiles.Name(k);

[tempPassAll(k), tempCloseAll(k), tempOffsetAll(k)] = compareToRange(avgTempForFit, profiles.TempMin(k), profiles.TempMax(k)); [humPassAll(k), humCloseAll(k), humOffsetAll(k)] = compareToRange(avgHum, profiles.HumMin(k), profiles.HumMax(k));
[presPassAll(k), presCloseAll(k), presOffsetAll(k)] = compareToRange(avgPres, profiles.PresMin(k), profiles.PresMax(k));

matchCountAll(k) = sum([tempPassAll(k), humPassAll(k), presPassAll(k)]);

overallClosenessAll(k) = mean([tempCloseAll(k), humCloseAll(k), presCloseAll(k)], 'omitnan');
end
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

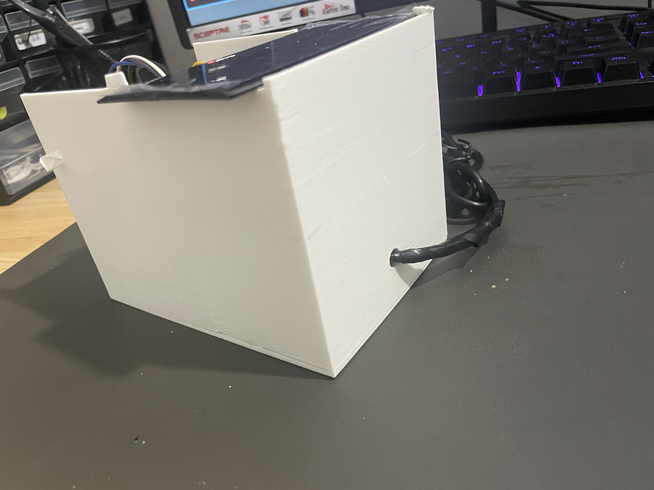
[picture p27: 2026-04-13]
Media/DS18B20 Exit hole.JPG

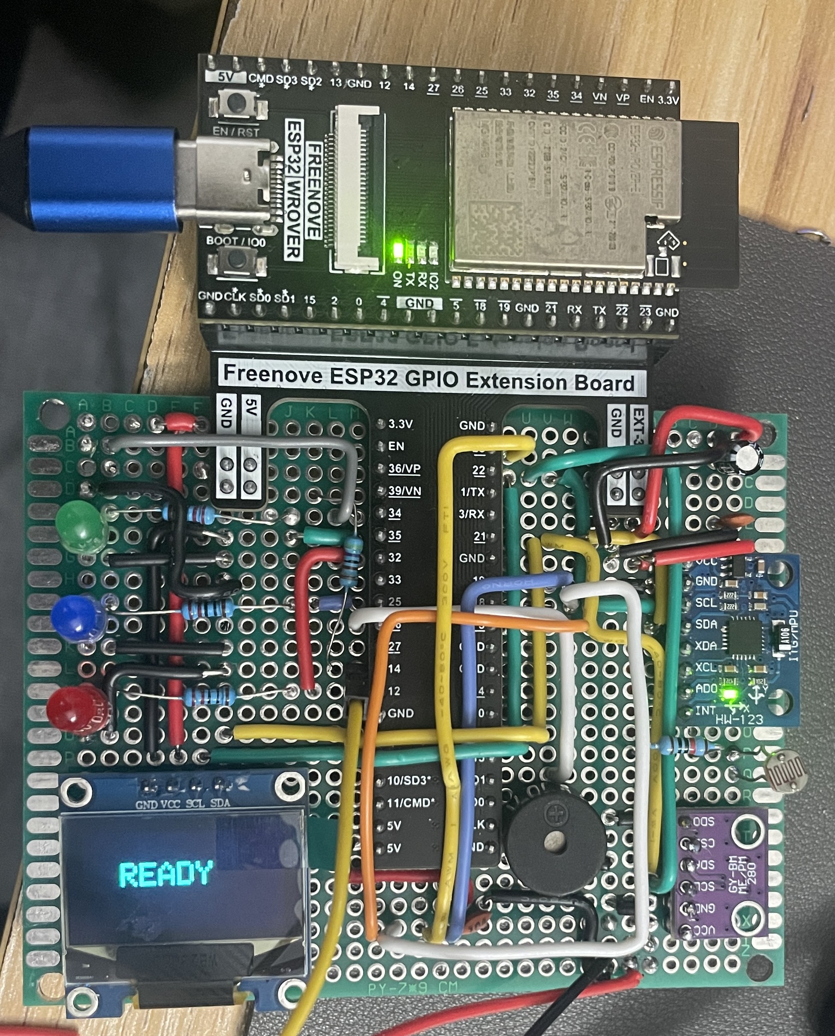
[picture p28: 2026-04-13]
Media/Final look of main board.JPG

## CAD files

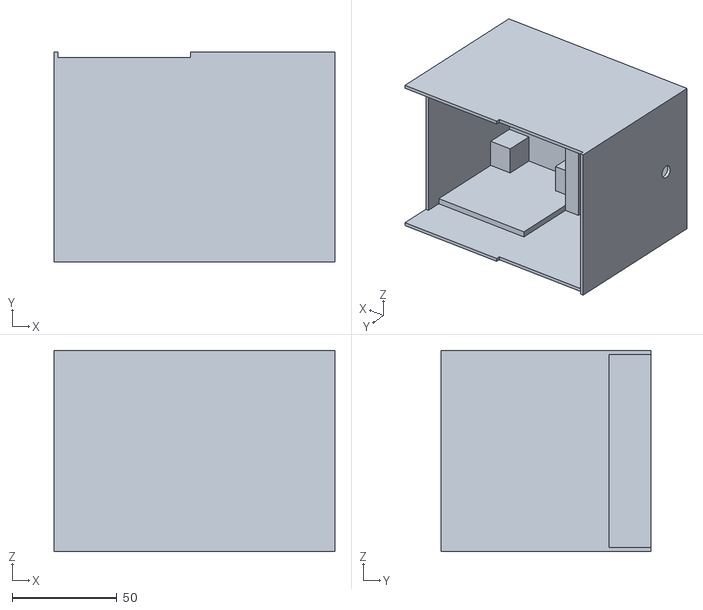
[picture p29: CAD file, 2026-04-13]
CAD Files/EBC HOUSING.stl
134.0 x 100.0 x 96.0

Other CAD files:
CAD Files/EBC HOUSING.dwg
CAD Files/EBC HOUSING.ipt

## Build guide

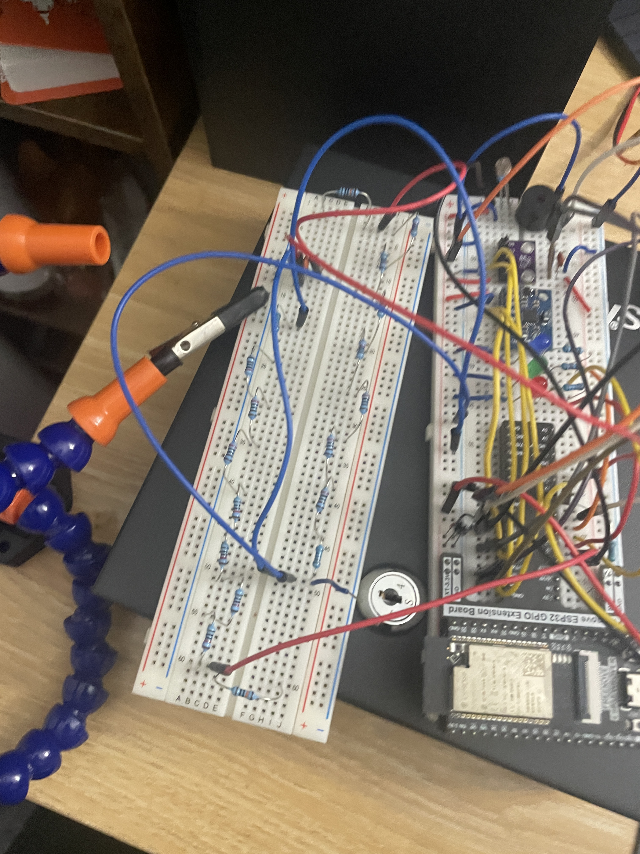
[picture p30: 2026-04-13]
Media/Rough Breadboard Setup .JPG

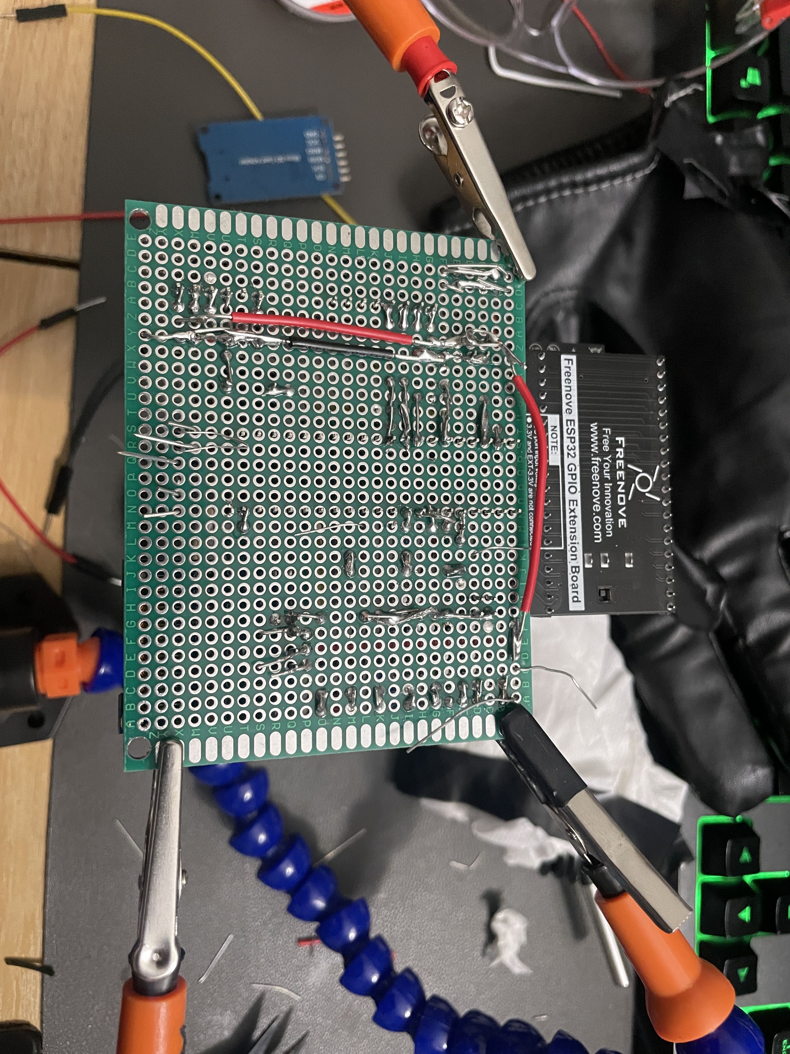
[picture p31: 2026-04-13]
Media/Soldering flip side of main board.JPG

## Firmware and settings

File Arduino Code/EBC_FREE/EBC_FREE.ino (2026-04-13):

/*
Environmental Brain Cube - Free Scanning Mode

This mode just watches the environment and logs what it sees.
It shows live values, gives warning alerts, and saves min/max data
to the SD card in time intervals.

Main job:
- read sensors
- show live values
- warn for high temp or humidity
- save interval min/max values to SD

Log file:
- /ebc_free_log.csv
*/

#include <Wire.h>
#include <SPI.h>
#include <SD.h>
#include <math.h>

#include <Adafruit_Sensor.h>
#include <Adafruit_BME280.h>
#include <MPU6050.h>
#include <OneWire.h>
#include <DallasTemperature.h>
#include <Adafruit_GFX.h>
#include <Adafruit_SSD1306.h>

// scale factors for the gravity(noraml_g) and gyroscope(noraml_gyro)
float normal_g = 1671.0;
float normal_gyro = 131.0;

// run time (use 0 if you want it to run forever)
const unsigned long RUN_DURATION_SEC = 0;

// time trackers
unsigned long runStartTime = 0;
bool runFinished = false;
bool finalLogWritten = false;

// pins
const int I2C_SDA = 21;
const int I2C_SCL = 22;

const int PIN_DS18B20 = 14;
const int PIN_LDR = 34;
const int PIN_BATTERY = 35;
const int PIN_SOLAR = 13;

const int LED_RED = 32;
const int LED_BLUE = 25;
const int LED_GREEN = 33;

const int PIN_BUZZER = 26;

const int SD_CS = 5;
const int SD_SCK = 18;
const int SD_MISO = 19;
const int SD_MOSI = 23;

// OLED
#define SCREEN_WIDTH 128
#define SCREEN_HEIGHT 64
#define OLED_RESET -1
#define SCREEN_ADDRESS 0x3C

Adafruit_SSD1306 display(SCREEN_WIDTH, SCREEN_HEIGHT, &Wire, OLED_RESET);

// sensors
OneWire oneWire(PIN_DS18B20);
DallasTemperature ds18b20(&oneWire);

Adafruit_BME280 bme;
MPU6050 mpu;

// adc references. 3.3 is pin voltage for the esp32. 4095 is max adc reading
const float ADC_REF = 3.3;
const float ADC_MAX = 4095.0;

// battery divider (this setup allows for the system to safely handle about 10V)
// the 9V battery will result in a 2.9V input into the pin
const float R1_BATT = 100000.0;
const float R2_BATT = 46800.0;
const float BATT_CAL = 0.959;      //calibration value for the battery

// solar divider (this setup allows for the system to safely handle about 10V)
const float R1_SOLAR = 100500.0;
const float R2_SOLAR = 46800.0;
const float SOLAR_CAL = 1.167;     //calibration value for the solar

// warning limits
const int LIGHT_DARK_TH = 1000;
const int LIGHT_BRIGHT_TH = 3800;

//========= IF YOU CHANGE THESE VALUES, CHANGE THEM IN MATLAB SCRIPT AS WELL =======//
const float TEMP_WARN_C = 50.0;
const float HUM_WARN_HIGH = 85.0;

// timing
const unsigned long FAST_INTERVAL_MS = 100;
const unsigned long BME_INTERVAL_MS = 500;
const unsigned long DS_INTERVAL_MS = 1000;
const unsigned long OLED_INTERVAL_MS = 250;
const unsigned long SD_INTERVAL_MS = 2000;

unsigned long lastFastRead = 0;
unsigned long lastBMERead = 0;
unsigned long lastDSRead = 0;
unsigned long lastOLEDRead = 0;
unsigned long lastSDWrite = 0;

// latest values
float bmeTemp = NAN;
float bmeHum = NAN;
float bmePres = NAN;
float dsTemp = NAN;
int lightRaw = 0;

int batteryRaw = 0;
float batteryAdcVoltage = 0.0;
float batteryVoltage = 0.0;

int solarRaw = 0;
float solarAdcVoltage = 0.0;
float solarVoltage = 0.0;

float ax_g = 0;
float ay_g = 0;
float az_g = 0;

float gx_dps = 0;
float gy_dps = 0;
float gz_dps = 0;

// alarms right now
bool bmeTempHighNow = false;
bool dsTempHighNow = false;
bool humHighNow = false;

// SD
bool sdOK = false;
const char* logFile = "/ebc_free_log.csv";
int currentRunNumber = 1;

// blink helper
struct BlinkState {
  bool on = false;
  unsigned long lastToggle = 0;
};

BlinkState blinkR;
BlinkState blinkB;

const unsigned long BLINK_MS = 200;

// simple min/max tracker
struct StatTracker {
  float minVal;
  float maxVal;
  unsigned long count;
};

// interval stats
StatTracker st_light;
StatTracker st_bmeTemp;
StatTracker st_bmeHum;
StatTracker st_bmePres;
StatTracker st_dsTemp;
StatTracker st_batt;
StatTracker st_solar;
StatTracker st_ax;
StatTracker st_ay;
StatTracker st_az;
StatTracker st_gx;
StatTracker st_gy;
StatTracker st_gz;

// reset one tracker
void resetStats(StatTracker &s) {
  s.minVal = 9999999.0;
  s.maxVal = -9999999.0;
  s.count = 0;
}

// add a value into a tracker
void updateStats(StatTracker &s, float v) {
  if (isnan(v)) {
    return;
  }

  if (v < s.minVal) {
    s.minVal = v;
  }

  if (v > s.maxVal) {
    s.maxVal = v;
  }

  s.count++;
}

bool hasStats(const StatTracker &s) {
  return s.count > 0;
}

void resetAllStats() {
  resetStats(st_light);
  resetStats(st_bmeTemp);
  resetStats(st_bmeHum);
  resetStats(st_bmePres);
  resetStats(st_dsTemp);
  resetStats(st_batt);
  resetStats(st_solar);
  resetStats(st_ax);
  resetStats(st_ay);
  resetStats(st_az);
  resetStats(st_gx);
  resetStats(st_gy);
  resetStats(st_gz);
}

void stopBuzzer() {
  ledcWriteTone(PIN_BUZZER, 0);
}

void stopOutputs() {
  digitalWrite(LED_RED, LOW);
  digitalWrite(LED_BLUE, LOW);
  digitalWrite(LED_GREEN, LOW);
  stopBuzzer();
}

void blinkLED(int pin, bool alarm, BlinkState &st, unsigned long now) {
  if (!alarm) {
    digitalWrite(pin, LOW);
    st.on = false;
    return;
  }

  if (now - st.lastToggle >= BLINK_MS) {
    st.lastToggle = now;
    st.on = !st.on;
    digitalWrite(pin, st.on ? HIGH : LOW);
  }
}

const char* getLightState(int raw) {
  if (raw <= LIGHT_DARK_TH) {
    return "DARK";
  }

  if (raw < LIGHT_BRIGHT_TH) {
    return "NORMAL";
  }

  return "BRIGHT";
}

void printStatOrNA(File &file, const StatTracker &s, int decimals) {
  if (hasStats(s)) {
    file.print(s.minVal, decimals);
  } else {
    file.print("NA");
  }

  file.print(",");

  if (hasStats(s)) {
    file.print(s.maxVal, decimals);
  } else {
    file.print("NA");
  }
}

int extractRunNumber(String line) {
  line.trim();

  if (!line.startsWith("RUN")) {
    return -1;
  }

  int commaIndex = line.indexOf(',');
  if (commaIndex == -1) {
    return -1;
  }

  String runText = line.substring(3, commaIndex);
  runText.trim();

  if (runText.length()) {
    return runText.toInt();
  }

  return -1;
}

int findNextRunNumber() {
  if (!SD.exists(logFile)) {
    return 1;
  }

  File file = SD.open(logFile, FILE_READ);
  if (!file) {
    return 1;
  }

  int lastRun = 0;

  while (file.available()) {
    int runNum = extractRunNumber(file.readStringUntil('
'));
    if (runNum > lastRun) {
      lastRun = runNum;
    }
  }

  file.close();
  return lastRun + 1;
}

void writeRunSeparator() {
  if (!sdOK) {
    return;
  }

  File file = SD.open(logFile, FILE_APPEND);
  if (!file) {
    Serial.println("Failed to open log file for run separator");
    return;
  }

  file.println();
  file.print("=== RUN");
  file.print(currentRunNumber);
  file.println(" START ===");

  file.println(
    "runLabel,millis,elapsedSec,"
    "lightMin,lightMax,lightState,"
    "bmeTempMin,bmeTempMax,"
    "bmeHumMin,bmeHumMax,"
    "bmePresMin,bmePresMax,"
    "dsTempMin,dsTempMax,"
    "battMin,battMax,"
    "solarMin,solarMax,"
    "axMin,axMax,"
    "ayMin,ayMax,"
    "azMin,azMax,"
    "gxMin,gxMax,"
    "gyMin,gyMax,"
    "gzMin,gzMax"
  );

  file.close();

  Serial.print("Run separator written for RUN");
  Serial.println(currentRunNumber);
}

void updateBuzzer(unsigned long now, bool tempHigh, bool humHigh) {
  bool anyAlarm = tempHigh || humHigh;

  if (!anyAlarm) {
    stopBuzzer();
    return;
  }

  int toneFreq = tempHigh ? 2200 : 1800;

  const unsigned long beepOnMs = 150;
  const unsigned long beepPeriodMs = 350;

  if ((now % beepPeriodMs) < beepOnMs) {
    ledcWriteTone(PIN_BUZZER, toneFreq);
  } else {
    stopBuzzer();
  }
}

float readBatteryVoltage() {
  long sum = 0;

  for (int i = 0; i < 10; i++) {
    sum += analogRead(PIN_BATTERY);
    delay(2);
  }

  batteryRaw = sum / 10.0;
  batteryAdcVoltage = (batteryRaw * ADC_REF) / ADC_MAX;
  batteryVoltage = batteryAdcVoltage * ((R1_BATT + R2_BATT) / R2_BATT) * BATT_CAL;

  return batteryVoltage;
}

float readSolarVoltage() {
  long sum = 0;

  for (int i = 0; i < 10; i++) {
    sum += analogRead(PIN_SOLAR);
    delay(2);
  }

  solarRaw = sum / 10.0;
  solarAdcVoltage = (solarRaw * ADC_REF) / ADC_MAX;
  solarVoltage = solarAdcVoltage * ((R1_SOLAR + R2_SOLAR) / R2_SOLAR) * SOLAR_CAL;

  return solarVoltage;
}

void bootScreen() {
  display.clearDisplay();
  display.setTextColor(SSD1306_WHITE);

  display.setTextSize(2);
  display.setCursor(10, 8);
  display.println("ENV");
  display.setCursor(0, 30);
  display.println("BRAIN CUBE");

  display.setTextSize(1);
  display.setCursor(28, 54);
  display.println("WELCOME");

  display.display();
  delay(2000);

  display.clearDisplay();
  display.setTextSize(1);
  display.setCursor(20, 10);
  display.println("Booting System");
  display.drawRect(14, 30, 100, 10, SSD1306_WHITE);
  display.display();

  for (int i = 0; i <= 96; i += 6) {
    display.fillRect(16, 32, i, 6, SSD1306_WHITE);
    display.display();
    delay(120);
  }

  display.clearDisplay();
  display.setTextSize(2);
  display.setCursor(24, 20);
  display.println("READY");
  display.display();
  delay(1500);
}

void showFinishedScreen(unsigned long now) {
  display.clearDisplay();
  display.setTextSize(1);
  display.setTextColor(SSD1306_WHITE);

  display.setCursor(18, 12);
  display.println("RUN COMPLETE");

  display.setCursor(0, 30);
  display.print("RUN");
  display.print(currentRunNumber);

  display.setCursor(0, 44);
  display.print("t=");
  display.print(now / 1000.0, 0);
  display.print("s");

  display.display();
}

void updateOLED(unsigned long now) {
  float elapsedSec = (now - runStartTime) / 1000.0;
  bool flashOn = ((now / 300) % 2 == 0);

  bool tempAlarm = bmeTempHighNow || dsTempHighNow;
  bool humAlarm = humHighNow;

  display.clearDisplay();
  display.setTextSize(1);
  display.setTextColor(SSD1306_WHITE);

  display.setCursor(0, 0);
  display.print("T:");
  if (!isnan(bmeTemp)) {
    if (tempAlarm && !flashOn) {
      display.print("   ");
    } else {
      display.print(bmeTemp, 1);
      display.print("C");
    }
  } else {
    display.print("--");
  }

  display.print(" DS:");
  if (!isnan(dsTemp)) {
    if (tempAlarm && !flashOn) {
      display.print("   ");
    } else {
      display.print(dsTemp, 1);
      display.print("C");
    }
  } else {
    display.print("--");
  }

  display.setCursor(90, 0);
  display.print("   R");
  display.print(currentRunNumber);

  display.setCursor(0, 10);
  display.print("H:");
  if (!isnan(bmeHum)) {
    if (humAlarm && !flashOn) {
      display.print("   ");
    } else {
      display.print(bmeHum, 0);
      display.print("%");
    }
  } else {
    display.print("--");
  }

  display.print(" P:");
  if (!isnan(bmePres)) {
    display.print(bmePres, 0);
    display.print("h");
  } else {
    display.print("--");
  }

  display.setCursor(0, 20);
  display.print("Bat:");
  display.print(batteryVoltage, 2);
  display.print("V");

  display.setCursor(64, 20);
  display.print("Sol:");
  display.print(solarVoltage, 2);
  display.print("V");

  display.setCursor(0, 30);
  display.print("L:");
  display.print(getLightState(lightRaw));

  display.setCursor(0, 40);
  display.print("X:");
  display.print(ax_g, 1);
  display.print(" Y:");
  display.print(ay_g, 1);
  display.print(" Z:");
  display.print(az_g, 1);

  display.setCursor(0, 50);
  display.print("t:");
  display.print(elapsedSec, 0);
  display.print("s");

  if (tempAlarm) {
    display.setCursor(92, 50);
    display.print("HOT");
  } else if (humAlarm) {
    display.setCursor(92, 50);
    display.print("HUM");
  }

  display.display();
}

void logToSD(unsigned long now) {
  if (!sdOK) {
    return;
  }

  File file = SD.open(logFile, FILE_APPEND);
  if (!file) {
    Serial.println("Failed to open log file for writing");
    return;
  }

  float elapsedSec = (now - runStartTime) / 1000.0;

  file.print("RUN");
  file.print(currentRunNumber);
  file.print(",");
  file.print(now);
  file.print(",");
  file.print(elapsedSec, 2);
  file.print(",");

  printStatOrNA(file, st_light, 0);
  file.print(",");
  file.print(getLightState(lightRaw));
  file.print(",");

  printStatOrNA(file, st_bmeTemp, 2);
  file.print(",");
  printStatOrNA(file, st_bmeHum, 2);
  file.print(",");
  printStatOrNA(file, st_bmePres, 2);
  file.print(",");
  printStatOrNA(file, st_dsTemp, 2);
  file.print(",");
  printStatOrNA(file, st_batt, 2);
  file.print(",");
  printStatOrNA(file, st_solar, 2);
  file.print(",");
  printStatOrNA(file, st_ax, 3);
  file.print(",");
  printStatOrNA(file, st_ay, 3);
  file.print(",");
  printStatOrNA(file, st_az, 3);
  file.print(",");
  printStatOrNA(file, st_gx, 2);
  file.print(",");
  printStatOrNA(file, st_gy, 2);
  file.print(",");
  printStatOrNA(file, st_gz, 2);

  file.println();
  file.close();

  Serial.print("Data logged to SD (min/max only), RUN");
  Serial.println(currentRunNumber);
}

void setup() {
  Serial.begin(115200);
  delay(1500);

  Serial.println();
  Serial.println("=== BOOT ===");

  Wire.begin(I2C_SDA, I2C_SCL);
  Serial.println("I2C started on SDA=21 SCL=22");

  analogReadResolution(12);
  analogSetPinAttenuation(PIN_LDR, ADC_11db);
  analogSetPinAttenuation(PIN_BATTERY, ADC_11db);
  analogSetPinAttenuation(PIN_SOLAR, ADC_11db);

  pinMode(LED_RED, OUTPUT);
  pinMode(LED_BLUE, OUTPUT);
  pinMode(LED_GREEN, OUTPUT);
  stopOutputs();

  ledcAttach(PIN_BUZZER, 2000, 8);
  stopBuzzer();

  if (!display.begin(SSD1306_SWITCHCAPVCC, SCREEN_ADDRESS)) {
    Serial.println("OLED init failed");
    while (1) {
    }
  }

  bootScreen();

  Serial.print("BME280 init at 0x76... ");
  bool bmeOK = bme.begin(0x76, &Wire);
  Serial.println(bmeOK ? "OK" : "FAIL");
  if (!bmeOK) {
    Serial.println("Check wiring: VCC=3.3V, GND, SDA=21, SCL=22");
    while (1) {
    }
  }

  Serial.print("MPU6050 init... ");
  mpu.initialize();
  bool mpuOK = mpu.testConnection();
  Serial.println(mpuOK ? "OK" : "FAIL");
  if (!mpuOK) {
    Serial.println("MPU6050 not found! Check I2C wiring.");
    while (1) {
    }
  }

  ds18b20.begin();
  Serial.println("DS18B20 begin() called");

  SPI.begin(SD_SCK, SD_MISO, SD_MOSI, SD_CS);
  Serial.print("SD init... ");

  if (SD.begin(SD_CS)) {
    sdOK = true;
    Serial.println("OK");

    if (!SD.exists(logFile)) {
      File file = SD.open(logFile, FILE_WRITE);
      if (file) {
        file.println("Environmental Brain Cube Free Scan Log");
        file.close();
        Serial.println("Log file created");
      }
    }

    currentRunNumber = findNextRunNumber();

    Serial.print("Current run label: RUN");
    Serial.println(currentRunNumber);

    writeRunSeparator();
  } else {
    sdOK = false;
    Serial.println("FAIL");
    Serial.println("Check SD wiring and card");
  }

  resetAllStats();
  runStartTime = millis();

  display.clearDisplay();
  display.setTextSize(2);
  display.setTextColor(SSD1306_WHITE);
  display.setCursor(10, 10);
  display.println("Sensors");

  display.setTextSize(1);
  display.setCursor(25, 40);
  display.println(sdOK ? "SD Ready" : "SD Not Found");

  display.setCursor(40, 52);
  display.print("RUN");
  display.println(currentRunNumber);

  display.display();

  Serial.println("Free scanning mode active");
  delay(1500);
}

void loop() {
  unsigned long now = millis();

  if (!runFinished && RUN_DURATION_SEC != 0) {
    if ((now - runStartTime) >= (RUN_DURATION_SEC * 1000UL)) {
      runFinished = true;
      stopOutputs();

      if (!finalLogWritten) {
        logToSD(now);
        resetAllStats();
        finalLogWritten = true;
      }

      Serial.print("RUN");
      Serial.print(currentRunNumber);
      Serial.println(" COMPLETE");
      showFinishedScreen(now);
    }
  }

  if (runFinished) {
    return;
  }

  if (now - lastDSRead >= DS_INTERVAL_MS) {
    lastDSRead = now;

    ds18b20.requestTemperatures();
    float t = ds18b20.getTempCByIndex(0);

    if (t != DEVICE_DISCONNECTED_C) {
      dsTemp = t;
      updateStats(st_dsTemp, dsTemp);
    }
  }

  if (now - lastBMERead >= BME_INTERVAL_MS) {
    lastBMERead = now;

    bmeTemp = bme.readTemperature();
    bmeHum = bme.readHumidity();
    bmePres = bme.readPressure() / 100.0f;

    updateStats(st_bmeTemp, bmeTemp);
    updateStats(st_bmeHum, bmeHum);
    updateStats(st_bmePres, bmePres);
  }


  if (now - lastFastRead >= FAST_INTERVAL_MS) {
    lastFastRead = now;

    lightRaw = analogRead(PIN_LDR);
    updateStats(st_light, (float)lightRaw);

    batteryVoltage = readBatteryVoltage();
    solarVoltage = readSolarVoltage();

    updateStats(st_batt, batteryVoltage);
    updateStats(st_solar, solarVoltage);

    int16_t ax, ay, az;
    mpu.getAcceleration(&ax, &ay, &az);

    ax_g = (float)ax / normal_g;
    ay_g = (float)ay / normal_g;
    az_g = (float)az / normal_g;

    int16_t gx_raw, gy_raw, gz_raw;
    mpu.getRotation(&gx_raw, &gy_raw, &gz_raw);

    gx_dps = gx_raw / normal_gyro;
    gy_dps = gy_raw / normal_gyro;
    gz_dps = gz_raw / normal_gyro;

    updateStats(st_ax, ax_g);
    updateStats(st_ay, ay_g);
    updateStats(st_az, az_g);
    updateStats(st_gx, gx_dps);
    updateStats(st_gy, gy_dps);
    updateStats(st_gz, gz_dps);

    bmeTempHighNow = !isnan(bmeTemp) && (bmeTemp > TEMP_WARN_C);
    dsTempHighNow = !isnan(dsTemp) && (dsTemp > TEMP_WARN_C);
    humHighNow = !isnan(bmeHum) && (bmeHum > HUM_WARN_HIGH);

    bool tempAlarm = bmeTempHighNow || dsTempHighNow;
    bool humAlarm = humHighNow;

    blinkLED(LED_RED, tempAlarm, blinkR, now);
    blinkLED(LED_BLUE, humAlarm, blinkB, now);
    digitalWrite(LED_GREEN, LOW);

    updateBuzzer(now, tempAlarm, humAlarm);

    Serial.print("RUN");
    Serial.print(currentRunNumber);
    Serial.print(" | t=");
    Serial.print((now - runStartTime) / 1000.0, 2);
    Serial.print(" s, Light: ");
    Serial.print(getLightState(lightRaw));
    Serial.print(" (raw=");
    Serial.print(lightRaw);
    Serial.print("), Battery: ");
    Serial.print(batteryVoltage, 2);
    Serial.print(" V, Solar: ");
    Serial.print(solarVoltage, 2);
    Serial.print(" V, BME Temp: ");
    Serial.print(bmeTemp, 1);
    Serial.print(" C, Hum: ");
    Serial.print(bmeHum, 1);
    Serial.print(" %, Pres: ");
    Serial.print(bmePres, 1);
    Serial.print(" hPa, DS18B20 Temp: ");
    Serial.print(dsTemp, 2);
    Serial.print(" C, Accel(g): (");
    Serial.print(ax_g, 3);
    Serial.print(", ");
    Serial.print(ay_g, 3);
    Serial.print(", ");
    Serial.print(az_g, 3);
    Serial.print("), Gyro(dps): (");
    Serial.print(gx_dps, 2);
    Serial.print(", ");
    Serial.print(gy_dps, 2);
    Serial.print(", ");
    Serial.print(gz_dps, 2);
    Serial.print(")");

    if (tempAlarm) {
      Serial.print(" [TEMP WARNING]");
    }
    if (humAlarm) {
      Serial.print(" [HUMIDITY WARNING]");
    }

    Serial.println();
  }

  if (now - lastOLEDRead >= OLED_INTERVAL_MS) {
    lastOLEDRead = now;
    updateOLED(now);
  }

  if (now - lastSDWrite >= SD_INTERVAL_MS) {
    lastSDWrite = now;
    logToSD(now);
    resetAllStats();
  }
}

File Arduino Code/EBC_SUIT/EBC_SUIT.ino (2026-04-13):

/*
Environmental Brain Cube - Suitability Mode

This mode runs the system for a test time and checks if the environment
stays safe enough for the cube. It shows live values, logs data to SD,
gives warnings, and can stop early if a warning lasts too long.

Main things it does:
- reads all sensors
- shows live values on OLED
- logs snapshot min/max values to SD
- watches warning times
- stops early if a bad condition lasts too long
- prints a final suitability summary

Log file:
- /ebc_suitability_log.csv
*/

#include <Wire.h>
#include <SPI.h>
#include <SD.h>
#include <math.h>

#include <Adafruit_Sensor.h>
#include <Adafruit_BME280.h>
#include <MPU6050.h>
#include <OneWire.h>
#include <DallasTemperature.h>
#include <Adafruit_GFX.h>
#include <Adafruit_SSD1306.h>

// scale factors for the gravity(noraml_g) and gyroscope(noraml_gyro)
float normal_g = 1671.0;
float normal_gyro = 131.0;

// run time (use 0 if you want it to run forever)
const unsigned long RUN_DURATION_SEC = 500;
const unsigned long MAX_CONT_WARN_SEC = 15; //warning counter

// time trackers
unsigned long runStartTime = 0;
bool runFinished = false;
bool finalSummaryWritten = false;
bool stoppedBySuitabilityFail = false;

// pins
const int I2C_SDA = 21;
const int I2C_SCL = 22;

const int PIN_DS18B20 = 14;
const int PIN_LDR = 34;
const int PIN_BATTERY = 35;
const int PIN_SOLAR = 13;

const int LED_RED = 32;
const int LED_BLUE = 25;
const int LED_GREEN = 33;

const int PIN_BUZZER = 26;

const int SD_CS = 5;
const int SD_SCK = 18;
const int SD_MISO = 19;
const int SD_MOSI = 23;

// oled
#define SCREEN_WIDTH 128
#define SCREEN_HEIGHT 64
#define OLED_RESET -1
#define SCREEN_ADDRESS 0x3C

Adafruit_SSD1306 display(SCREEN_WIDTH, SCREEN_HEIGHT, &Wire, OLED_RESET);

// sensors
OneWire oneWire(PIN_DS18B20);
DallasTemperature ds18b20(&oneWire);

Adafruit_BME280 bme;
MPU6050 mpu;

//=========IF YOU CHANGE THESE VALUES, CHANGE THEM IN MATLAB SCRIPT AS WELL=======

// adc references. 3.3 is pin voltage for the esp32. 4095 is max adc reading
const float ADC_REF = 3.3;
const float ADC_MAX = 4095.0;

// battery divider (this setup allows for the system to safely handle about 10V)
// the 9V battery will result in a 2.9V input into the pin
const float R1_BATT = 100000.0;
const float R2_BATT = 46800.0;
const float BATT_CAL = 0.959;       //calibration value for the battery

const float R1_SOLAR = 100500.0;
const float R2_SOLAR = 46800.0;
const float SOLAR_CAL = 1.167;      //calibration value for the solar

// thresholds for system
const int LIGHT_DARK_TH = 3000;
const int LIGHT_BRIGHT_TH = 3500;

const float BME_TEMP_MIN_C = 20.0;
const float BME_TEMP_MAX_C = 25.0;

const float DS_TEMP_MIN_C = 20.0;
const float DS_TEMP_MAX_C = 25.0;

const float HUM_MIN_PCT = 40.0;
const float HUM_MAX_PCT = 55.0;

const float PRES_MIN_HPA = 950.0;
const float PRES_MAX_HPA = 1050.0;

const float BATT_MIN_V = 5.00;
const float BATT_MAX_V = 7.20;

const float SOLAR_MIN_V = 3.50;
const float SOLAR_MAX_V = 5.50;

const float LIGHT_MIN_RAW = 0.0;
const float LIGHT_MAX_RAW = 4095.0;

const float AX_MIN_G = -16.0;
const float AX_MAX_G = 16.0;
const float AY_MIN_G = -16.0;
const float AY_MAX_G = 16.0;
const float AZ_MIN_G = -16.0;
const float AZ_MAX_G = 16.0;

const float GX_MIN_DPS = -250.0;
const float GX_MAX_DPS = 250.0;
const float GY_MIN_DPS = -250.0;
const float GY_MAX_DPS = 250.0;
const float GZ_MIN_DPS = -250.0;
const float GZ_MAX_DPS = 250.0;

// final rating margins
const float VERY_MARGIN_FRAC = 0.20;
const float GOOD_MARGIN_FRAC = 0.10;

// timing
const unsigned long FAST_INTERVAL_MS = 100;
const unsigned long BME_INTERVAL_MS = 500;
const unsigned long DS_INTERVAL_MS = 1000;
const unsigned long OLED_INTERVAL_MS = 250;
const unsigned long SD_INTERVAL_MS = 2000;

unsigned long lastFastRead = 0;
unsigned long lastBMERead = 0;
unsigned long lastDSRead = 0;
unsigned long lastOLEDRead = 0;
unsigned long lastSDWrite = 0;

// latest values
float bmeTemp = NAN;
float bmeHum = NAN;
float bmePres = NAN;
float dsTemp = NAN;
int lightRaw = 0;

int batteryRaw = 0;
float batteryAdcVoltage = 0.0;
float batteryVoltage = 0.0;

int solarRaw = 0;
float solarAdcVoltage = 0.0;
float solarVoltage = 0.0;

float ax_g = 0;
float ay_g = 0;
float az_g = 0;

float gx_dps = 0;
float gy_dps = 0;
float gz_dps = 0;

// warnings now
bool bmeTempWarnNow = false;
bool dsTempWarnNow = false;
bool humWarnNow = false;
bool presWarnNow = false;
bool battWarnNow = false;
bool solarWarnNow = false;
bool lightWarnNow = false;
bool axWarnNow = false;
bool ayWarnNow = false;
bool azWarnNow = false;
bool gxWarnNow = false;
bool gyWarnNow = false;
bool gzWarnNow = false;

// how long warnings have lasted
unsigned long bmeTempWarnStart = 0;
unsigned long dsTempWarnStart = 0;
unsigned long humWarnStart = 0;
unsigned long presWarnStart = 0;
unsigned long battWarnStart = 0;
unsigned long solarWarnStart = 0;
unsigned long lightWarnStart = 0;
unsigned long axWarnStart = 0;
unsigned long ayWarnStart = 0;
unsigned long azWarnStart = 0;
unsigned long gxWarnStart = 0;
unsigned long gyWarnStart = 0;
unsigned long gzWarnStart = 0;

String failReason = "NONE";
String finalRating = "UNRATED";

// sd
bool sdOK = false;
const char* logFile = "/ebc_suitability_log.csv";
int currentRunNumber = 1;

// blink helper
struct BlinkState {
  bool on = false;
  unsigned long lastToggle = 0;
};

BlinkState blinkR;
BlinkState blinkB;
BlinkState blinkG;

const unsigned long BLINK_MS = 200;

// full run stats
struct StatTracker {
  float minVal;
  float maxVal;
  double sumVal;
  unsigned long count;
};

// one log interval stats
struct IntervalStatTracker {
  float minVal;
  float maxVal;
  unsigned long count;
};

// interval stats
StatTracker st_light;
StatTracker st_bmeTemp;
StatTracker st_bmeHum;
StatTracker st_bmePres;
StatTracker st_dsTemp;
StatTracker st_batt;
StatTracker st_solar;
StatTracker st_ax;
StatTracker st_ay;
StatTracker st_az;
StatTracker st_gx;
StatTracker st_gy;
StatTracker st_gz;

IntervalStatTracker int_light;
IntervalStatTracker int_bmeTemp;
IntervalStatTracker int_bmeHum;
IntervalStatTracker int_bmePres;
IntervalStatTracker int_dsTemp;
IntervalStatTracker int_batt;
IntervalStatTracker int_solar;
IntervalStatTracker int_ax;
IntervalStatTracker int_ay;
IntervalStatTracker int_az;
IntervalStatTracker int_gx;
IntervalStatTracker int_gy;
IntervalStatTracker int_gz;

// basic stat helpers
void resetStats(StatTracker &s) {
  s.minVal = 9999999.0;
  s.maxVal = -9999999.0;
  s.sumVal = 0.0;
  s.count = 0;
}

void updateStats(StatTracker &s, float v) {
  if (isnan(v)) {
    return;
  }

  if (v < s.minVal) {
    s.minVal = v;
  }

  if (v > s.maxVal) {
    s.maxVal = v;
  }

  s.sumVal += v;
  s.count++;
}

bool hasStats(const StatTracker &s) {
  return s.count > 0;
}

float avgStat(const StatTracker &s) {
  if (hasStats(s)) {
    return s.sumVal / s.count;
  }
  return NAN;
}
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
